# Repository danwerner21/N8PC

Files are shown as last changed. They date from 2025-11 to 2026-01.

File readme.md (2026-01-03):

# N8PC
The N8PC is a Z180 ATX format board with 512K RAM, 512K of ROM, that supports RomWBW and is compatible enough with MSX to run many games.  It supports a 82c42 PS2 keyboard controller, a TMS9918 emulator (either Pico9918, F19A or Tang Nano) for 80 column video output, a Ay-3-8910 PSG for sound, a 6242 RTC, ATARI/MSX style Joysticks (2 button supported) and 6 ISAish slots.  This computer is supported by the RomWBW ecosystem with full CP/M OS Support.

Note that 9.218Mhz is the recommended system clock speed for this system.  

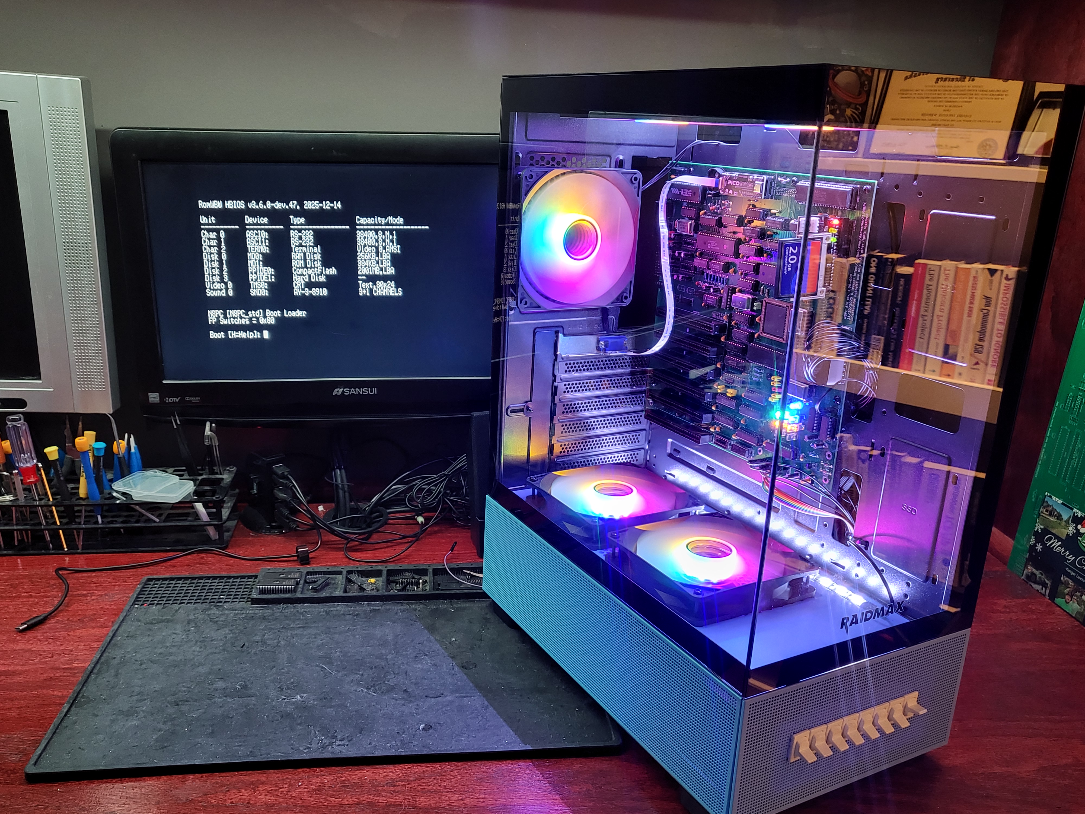
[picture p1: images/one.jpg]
System


## BUGS
```
V1.1 version PCBs have not been tested yet.

Bodges for V1.0 of Board
U33 Cut Pin 3 traces on both Top and Bottom
U33 Cut Pin 5 trace on Bottom

U6 Cut Pin 8 trace on Bottom (NOT TOP!!)

Connect CS_RTC from U47 Pin 2 to U9 Pin 11
Connect U33 Pin 3 To U5 Pin 5
Connect U33 Pin 5 To U5 Pin 6
Connect U18 Pin 2 to U18 Pin 13
```

### Jumper Settings
[TO DO]

### Building the system
[TO DO]

### Default Memory Map
** See RomWBW or C-BIOS Documentation
RomWBW Support: https://github.com/wwarthen/RomWBW
CBIOS MSX Game Support: https://github.com/danwerner21/msxbios

Note that the CBIOS MSX game support is still a work in progress.  It does work, but there is still much work to do. I am not including any actual game ROMS, I leave that to the builder to locate those ROMs as they are easily found on the Internet.

### Bill Of Materials
Reference|Value|Qty|Description
---------|-----|---|-----------
BT1|Battery_Cell|1|CR2032 battery holder
C1-C4,C17|22 uF|5|Polarized capacitor
C5-C8,C10-C13,C15,C16,C18-C27,C29-C33,C36-C41,C43-C54,C56|0.1 uF|44|Unpolarized capacitor
C28|1uF|1|Polarized capacitor
C34|4.7pF|1|
C35|10uF|1|Polarized capacitor
C55,C58,C61-C64,C67,C71-C73|1.0 uF|10|Polarized capacitor, small symbol
C57|0.01 uF|1|Unpolarized capacitor
C59,C60|15pf|2|Unpolarized capacitor
C101,C102|270 pF|2|Unpolarized capacitor
C109,C110|10 uF|2|Polarized capacitor, small symbol
D1,D2|1N4148|2|Diode
D3,D4|D|2|Diode
D5|1N5817|1|20V 1A Schottky Barrier Rectifier Diode, DO-41
D6|RUN/HALT|1|Dual LED, bidirectional
D7|LED1|1|Light emitting diode
D8|LED2|1|Light emitting diode
D9|LED3|1|Light emitting diode
D10|LED0|1|Light emitting diode
D11|IDE|1|Light emitting diode
D12|STATUS|1|Light emitting diode
J1,J2,J5,J7,J9,J13|IRQ Selection|6|Generic connector, double row, 02x06
J3,J4,J6,J8,J10,J14|Bus_ISA_8bit|6|8-bit ISA-PC bus connector
J11|F18A TANG NANO Connector|1|Generic connector, double row, 02x10
J12|FRONT_PANEL|1|Generic connector, double row, 02x11
J15|MOUSE|1|6-pin Mini-DIN connector
J16|KEYBOARD|1|6-pin Mini-DIN connector
J17,J19|TTL SERIAL CONSOLE|2|Generic connector, single row, 01x06
J18,J20|TTL CONSOLE PWR|2|Generic connector, single row, 01x02
J21|KEYBOARD IRQ|1|Generic connector, double row, 02x02
J22|BUS IRQ|1|Generic connector, double row, 02x02
J23|VIDEO IRQ|1|Generic connector, double row, 02x02
JP2|CTS0|1|Jumper, 2-pole, open
JP3|CTS1|1|Jumper, 2-pole, open
JP10|JUMPER|1|Jumper, 2-pole, open
K2|IDE_PWR|1|Generic connector, single row, 01x03
K3-K5,K16,K18|CONN_3|5|Generic connector, single row, 01x03
K17|CPU_CLK|1|Generic connector, single row, 01x03
P1|IO_ADDR|1|Generic connector, double row, 02x03
P11|CONN_10X2|1|Generic connector, double row, 02x10
P12|POWER_SW|1|Generic connector, single row, 01x02
P13,P18|SERIAL|2|Generic connector, double row, 02x05
P14|14.31818 MHz CLK|1|
P15|AUDIO|1|Generic connector, double row, 02x05
P16|IO_ADDR2|1|Generic connector, double row, 02x03
P19|ASCI OSC|1|
P27|FLOPPY|1|Generic connector, double row, 02x17
P29|PPIDE|1|Generic connector, double row, 02x20
P31|PARALLEL EXP|1|Generic connector, double row, 02x13
P37|CPU OSC|1|
P41|OSC_FDC|1|
P43|CHAN_MIX|1|Generic connector, double row, 02x02
P51|JOYSTICK0|1|Generic connector, double row, 02x05
P52|JOYSTICK1|1|Generic connector, double row, 02x05
R1,R3|10k|2|Resistor
R2,R5,R7,R9,R10,R36|470|6|Resistor
R4,R13,R14,R26|4.7K|4|Resistor
R6,R17,R19,R21|1000|4|Resistor
R8,R12,R46,R47,RN5,RR1,RR5,RR8,RV1,RV2|4700|10|9 resistor network, star topology, bussed resistors, small US symbol,Potentiometer,Resistor
R11|100|1|Resistor
R16,R22-R24|10K|4|Resistor
R42|2200|1|Resistor
RP1|150|1|8 resistor network, star topology, bussed resistors, small symbol
SW1|POWER|1|Push button switch, generic, two pins
SW2|RESET|1|Push button switch, generic, two pins
U1,U3,U4,U16,U31|74LS244|5|Octal Buffer and Line Driver With 3-State Output, active-low enables, non-inverting outputs
U2,U63|74LS14|2|Hex inverter schmitt trigger
U5|74LS02|1|quad 2-input NOR gate
U6,U7,U18|74LS32|3|Quad 2-input OR
U8|74LS08|1|Quad And2
U9,U58,U68|74LS138|3|Decoder 3 to 8 active low outputs
U10,U35|MAX232|2|Dual RS232 driver/receiver, 5V supply, 120kb/s, 0C-70C
U12|74LS74|1|Dual D Flip-flop, Set & Reset
U13|27C080|1|OTP EPROM 8 MiBit (1 Mi x 8)
U14|74LS125|1|Quad buffer 3-State outputs
U15|74LS245|1|Octal BUS Transceivers, 3-State outputs
U19|74HCT14|1|Hex inverter schmitt trigger
U21,U57|74LS682N|2|
U23|TMS9918 EMU|1|
U24|CLK|1|
U25|82c42|1|
U26|74LS06|1|
U29|DS1233|1|
U32|74LS139|1|Dual Decoder 1 of 4, Active low outputs
U33|74LS10|1|Triple 3-input NAND
U34|74LS393|1|Dual BCD 4-bit counter
U38|8255|1|Programmable Peripheral Interface, PDIP-40
U39|74LS04|1|Hex Inverter
U47|M6242|1|M6242
U48|AY-3-8910|1|
U49|74LS07N|1|Hex Buffers and Drivers With Open Collector High Voltage Outputs
U51|STEREO_JACK|1|Audio Jack, 3 Poles (Stereo / TRS)
U52|Z8S180|1|
U53|SRAM_512KO|1|512K x 8 Low Power CMOS RAM, DIP-32
U55|74LS273|1|8-bit D Flip-Flop, reset
U61|WD37C65BJM|1|
U66,U67|74LS157|2|Quad 2 to 1 line Multiplexer
U70|74LS174|1|Hex D-type Flip-Flop, reset
X1|RTC_OSC|1|Two pin crystal

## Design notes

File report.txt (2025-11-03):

Info: Backing up file '\\truenas.\Development\Vintage\ECB 6x0x-6U-012\sym-lib-table' to '\\truenas.\Development\Vintage\ECB 6x0x-6U-012\rescue-backup\sym-lib-table-2024-12-25-17-23-22'.
Info: Backing up file '\\truenas.\Development\Vintage\ECB 6x0x-6U-012\6x0x-6U.sch' to '\\truenas.\Development\Vintage\ECB 6x0x-6U-012\rescue-backup\6x0x-6U-2024-12-25-17-23-22.sch'.
Info: Backing up file '\\truenas.\Development\Vintage\ECB 6x0x-6U-012\PropTerm.sch' to '\\truenas.\Development\Vintage\ECB 6x0x-6U-012\rescue-backup\PropTerm-2024-12-25-17-23-22.sch'.
Info: Backing up file '\\truenas.\Development\Vintage\ECB 6x0x-6U-012\Power.sch' to '\\truenas.\Development\Vintage\ECB 6x0x-6U-012\rescue-backup\Power-2024-12-25-17-23-22.sch'.
Info: Backing up file '\\truenas.\Development\Vintage\ECB 6x0x-6U-012\Reset.sch' to '\\truenas.\Development\Vintage\ECB 6x0x-6U-012\rescue-backup\Reset-2024-12-25-17-23-22.sch'.
Info: Backing up file '\\truenas.\Development\Vintage\ECB 6x0x-6U-012\MMU-4.sch' to '\\truenas.\Development\Vintage\ECB 6x0x-6U-012\rescue-backup\MMU-4-2024-12-25-17-23-22.sch'.
Info: Backing up file '\\truenas.\Development\Vintage\ECB 6x0x-6U-012\cpu-6809.sch' to '\\truenas.\Development\Vintage\ECB 6x0x-6U-012\rescue-backup\cpu-6809-2024-12-25-17-23-22.sch'.
Info: Backing up file '\\truenas.\Development\Vintage\ECB 6x0x-6U-012\Spare.sch' to '\\truenas.\Development\Vintage\ECB 6x0x-6U-012\rescue-backup\Spare-2024-12-25-17-23-22.sch'.
Info: Backing up file '\\truenas.\Development\Vintage\ECB 6x0x-6U-012\IO.sch' to '\\truenas.\Development\Vintage\ECB 6x0x-6U-012\rescue-backup\IO-2024-12-25-17-23-22.sch'.
Info: Backing up file '\\truenas.\Development\Vintage\ECB 6x0x-6U-012\CPU-6802.sch' to '\\truenas.\Development\Vintage\ECB 6x0x-6U-012\rescue-backup\CPU-6802-2024-12-25-17-23-22.sch'.
Info: Backing up file '\\truenas.\Development\Vintage\ECB 6x0x-6U-012\memory-map.sch' to '\\truenas.\Development\Vintage\ECB 6x0x-6U-012\rescue-backup\memory-map-2024-12-25-17-23-22.sch'.
Info: Backing up file '\\truenas.\Development\Vintage\ECB 6x0x-6U-012\ECBbus.sch' to '\\truenas.\Development\Vintage\ECB 6x0x-6U-012\rescue-backup\ECBbus-2024-12-25-17-23-22.sch'.
Info: Backing up file '\\truenas.\Development\Vintage\ECB 6x0x-6U-012\Decoder.sch' to '\\truenas.\Development\Vintage\ECB 6x0x-6U-012\rescue-backup\Decoder-2024-12-25-17-23-22.sch'.
Info: Backing up file '\\truenas.\Development\Vintage\ECB 6x0x-6U-012\ACIA.sch' to '\\truenas.\Development\Vintage\ECB 6x0x-6U-012\rescue-backup\ACIA-2024-12-25-17-23-22.sch'.
Info: Backing up file '\\truenas.\Development\Vintage\ECB 6x0x-6U-012\TIMER.sch' to '\\truenas.\Development\Vintage\ECB 6x0x-6U-012\rescue-backup\TIMER-2024-12-25-17-23-22.sch'.
Info: Backing up file '\\truenas.\Development\Vintage\ECB 6x0x-6U-012\VIAS.sch' to '\\truenas.\Development\Vintage\ECB 6x0x-6U-012\rescue-backup\VIAS-2024-12-25-17-23-22.sch'.
Info: Backing up file '\\truenas.\Development\Vintage\ECB 6x0x-6U-012\PIA.sch' to '\\truenas.\Development\Vintage\ECB 6x0x-6U-012\rescue-backup\PIA-2024-12-25-17-23-22.sch'.
Info: Backing up file '\\truenas.\Development\Vintage\ECB 6x0x-6U-012\RTC.sch' to '\\truenas.\Development\Vintage\ECB 6x0x-6U-012\rescue-backup\RTC-2024-12-25-17-23-22.sch'.
Info: Backing up file '\\truenas.\Development\Vintage\ECB 6x0x-6U-012\6x0x-6U.kicad_pro' to '\\truenas.\Development\Vintage\ECB 6x0x-6U-012\rescue-backup\6x0x-6U-2024-12-25-17-23-22.kicad_pro'.
Info: Backing up file '\\truenas.\Development\Vintage\ECB 6x0x-6U-012\6x0x-6U-cache.lib' to '\\truenas.\Development\Vintage\ECB 6x0x-6U-012\rescue-backup\6x0x-6U-cache-2024-12-25-17-23-22.lib'.
Info: Backing up file '\\truenas.\Development\Vintage\ECB 6x0x-6U-012\6x0x-6U-rescue.lib' to '\\truenas.\Development\Vintage\ECB 6x0x-6U-012\rescue-backup\6x0x-6U-rescue-2024-12-25-17-23-22.lib'.
Info: Backing up file '\\truenas.\Development\Vintage\ECB 6x0x-6U-012\6x0x-6U-rescue.dcm' to '\\truenas.\Development\Vintage\ECB 6x0x-6U-012\rescue-backup\6x0x-6U-rescue-2024-12-25-17-23-22.dcm'.
Info: Adding library '6x0x-6U-rescue', file '${KIPRJMOD}/6x0x-6U-rescue.lib' to project symbol library table.
Symbol R mapped to symbol library '6x0x-6U-rescue'.
Symbol R_PACK7 mapped to symbol library '6x0x-6U-rescue'.
Symbol CP1 mapped to symbol library '6x0x-6U-rescue'.
Symbol 24C512 mapped to symbol library '6x0x-6U-rescue'.
Symbol CONN_4 mapped to symbol library '6x0x-6U-rescue'.
Symbol GND mapped to symbol library '6x0x-6U-rescue'.
Symbol VDD mapped to symbol library '6x0x-6U-rescue'.
Symbol MAX232 mapped to symbol library '6x0x-6U-rescue'.
Symbol CP1 mapped to symbol library '6x0x-6U-rescue'.
Symbol R mapped to symbol library '6x0x-6U-rescue'.
Symbol R mapped to symbol library '6x0x-6U-rescue'.
Symbol CRYSTAL mapped to symbol library '6x0x-6U-rescue'.
Symbol VDD mapped to symbol library '6x0x-6U-rescue'.
Symbol R mapped to symbol library '6x0x-6U-rescue'.
Symbol R mapped to symbol library '6x0x-6U-rescue'.
Symbol R mapped to symbol library '6x0x-6U-rescue'.
Symbol R mapped to symbol library '6x0x-6U-rescue'.
Symbol R mapped to symbol library '6x0x-6U-rescue'.
Symbol R mapped to symbol library '6x0x-6U-rescue'.
Symbol R mapped to symbol library '6x0x-6U-rescue'.
Symbol VCC mapped to symbol library '6x0x-6U-rescue'.
Symbol FUSE mapped to symbol library '6x0x-6U-rescue'.
Symbol R_PACK7 mapped to symbol library '6x0x-6U-rescue'.
Symbol JUMPER3 mapped to symbol library '6x0x-6U-rescue'.
Symbol 74LS06 mapped to symbol library '6x0x-6U-rescue'.
Symbol P8X32A mapped to symbol library '6x0x-6U-rescue'.
Symbol GND mapped to symbol library '6x0x-6U-rescue'.
Symbol VDD mapped to symbol library '6x0x-6U-rescue'.
Symbol GND mapped to symbol library '6x0x-6U-rescue'.
Symbol LED mapped to symbol library '6x0x-6U-rescue'.
Symbol 74LS06 mapped to symbol library '6x0x-6U-rescue'.
Symbol SDcard-mini_04 mapped to symbol library '6x0x-6U-rescue'.
Symbol VCC mapped to symbol library '6x0x-6U-rescue'.
Symbol R mapped to symbol library '6x0x-6U-rescue'.
Symbol CONN_6X2 mapped to symbol library '6x0x-6U-rescue'.
Symbol R mapped to symbol library '6x0x-6U-rescue'.
Symbol R mapped to symbol library '6x0x-6U-rescue'.
Symbol VDD mapped to symbol library '6x0x-6U-rescue'.
Symbol VDD mapped to symbol library '6x0x-6U-rescue'.
Symbol CP1 mapped to symbol library '6x0x-6U-rescue'.
Symbol C mapped to symbol library '6x0x-6U-rescue'.
Symbol GND mapped to symbol library '6x0x-6U-rescue'.
Symbol 74LS06 mapped to symbol library '6x0x-6U-rescue'.
Symbol GND mapped to symbol library '6x0x-6U-rescue'.
Symbol SPEAKER mapped to symbol library '6x0x-6U-rescue'.
Symbol GND mapped to symbol library '6x0x-6U-rescue'.
Symbol R mapped to symbol library '6x0x-6U-rescue'.
Symbol R mapped to symbol library '6x0x-6U-rescue'.
Symbol R mapped to symbol library '6x0x-6U-rescue'.
Symbol RR9 mapped to symbol library '6x0x-6U-rescue'.
Symbol VDD mapped to symbol library '6x0x-6U-rescue'.
Symbol JUMPER mapped to symbol library '6x0x-6U-rescue'.
Symbol CP1 mapped to symbol library '6x0x-6U-rescue'.
Symbol GND mapped to symbol library '6x0x-6U-rescue'.
Symbol VCC mapped to symbol library '6x0x-6U-rescue'.
Symbol CP1 mapped to symbol library '6x0x-6U-rescue'.
Symbol CONN_5X2 mapped to symbol library '6x0x-6U-rescue'.
Symbol CP1 mapped to symbol library '6x0x-6U-rescue'.
Symbol R mapped to symbol library '6x0x-6U-rescue'.
Symbol R mapped to symbol library '6x0x-6U-rescue'.
Symbol R mapped to symbol library '6x0x-6U-rescue'.
Symbol DE15 mapped to symbol library '6x0x-6U-rescue'.
Symbol GND mapped to symbol library '6x0x-6U-rescue'.
Symbol GND mapped to symbol library '6x0x-6U-rescue'.
Symbol CONN_9 mapped to symbol library '6x0x-6U-rescue'.
Symbol JUMPER mapped to symbol library '6x0x-6U-rescue'.
Symbol CONN_4 mapped to symbol library '6x0x-6U-rescue'.
Symbol GND mapped to symbol library '6x0x-6U-rescue'.
Symbol GND mapped to symbol library '6x0x-6U-rescue'.
Symbol GND mapped to symbol library '6x0x-6U-rescue'.
Symbol MINI_DIN_6 mapped to symbol library '6x0x-6U-rescue'.
Symbol R mapped to symbol library '6x0x-6U-rescue'.
Symbol 74LS14PWR mapped to symbol library '6x0x-6U-rescue'.
Symbol 74LS14PWR mapped to symbol library '6x0x-6U-rescue'.
Symbol DIODE mapped to symbol library '6x0x-6U-rescue'.
Symbol CP1 mapped to symbol library '6x0x-6U-rescue'.
Symbol 74LS14PWR mapped to symbol library '6x0x-6U-rescue'.
Symbol 74LS14PWR mapped to symbol library '6x0x-6U-rescue'.
Symbol 74LS14PWR mapped to symbol library '6x0x-6U-rescue'.
Symbol 74LS14PWR mapped to symbol library '6x0x-6U-rescue'.
Symbol 74LS74PWR mapped to symbol library '6x0x-6U-rescue'.
Symbol C mapped to symbol library '6x0x-6U-rescue'.
Symbol C mapped to symbol library '6x0x-6U-rescue'.
Symbol C mapped to symbol library '6x0x-6U-rescue'.
Symbol C mapped to symbol library '6x0x-6U-rescue'.
Symbol C mapped to symbol library '6x0x-6U-rescue'.
Symbol C mapped to symbol library '6x0x-6U-rescue'.
Symbol C mapped to symbol library '6x0x-6U-rescue'.
Symbol C mapped to symbol library '6x0x-6U-rescue'.
Symbol C mapped to symbol library '6x0x-6U-rescue'.
Symbol C mapped to symbol library '6x0x-6U-rescue'.
Symbol C mapped to symbol library '6x0x-6U-rescue'.
Symbol C mapped to symbol library '6x0x-6U-rescue'.
Symbol C mapped to symbol library '6x0x-6U-rescue'.
Symbol C mapped to symbol library '6x0x-6U-rescue'.
Symbol C mapped to symbol library '6x0x-6U-rescue'.
Symbol C mapped to symbol library '6x0x-6U-rescue'.
Symbol C mapped to symbol library '6x0x-6U-rescue'.
Symbol C mapped to symbol library '6x0x-6U-rescue'.
Symbol C mapped to symbol library '6x0x-6U-rescue'.
Symbol C mapped to symbol library '6x0x-6U-rescue'.
Symbol C mapped to symbol library '6x0x-6U-rescue'.
Symbol C mapped to symbol library '6x0x-6U-rescue'.
Symbol C mapped to symbol library '6x0x-6U-rescue'.
Symbol PWR_FLAG mapped to symbol library '6x0x-6U-rescue'.
Symbol DIODE mapped to symbol library '6x0x-6U-rescue'.
Symbol R mapped to symbol library '6x0x-6U-rescue'.
Symbol CONN_2 mapped to symbol library '6x0x-6U-rescue'.
Symbol SW_PUSH mapped to symbol library '6x0x-6U-rescue'.
Symbol CP1 mapped to symbol library '6x0x-6U-rescue'.
Symbol GND mapped to symbol library '6x0x-6U-rescue'.
Symbol R mapped to symbol library '6x0x-6U-rescue'.
Symbol R mapped to symbol library '6x0x-6U-rescue'.
Symbol PWR_FLAG mapped to symbol library '6x0x-6U-rescue'.
Symbol GND mapped to symbol library '6x0x-6U-rescue'.
Symbol CONN_10X2 mapped to symbol library '6x0x-6U-rescue'.
Symbol PWR_FLAG mapped to symbol library '6x0x-6U-rescue'.
Symbol GND mapped to symbol library '6x0x-6U-rescue'.
Symbol CONN_5 mapped to symbol library '6x0x-6U-rescue'.
Symbol GND mapped to symbol library '6x0x-6U-rescue'.
Symbol C mapped to symbol library '6x0x-6U-rescue'.
Symbol C mapped to symbol library '6x0x-6U-rescue'.
Symbol C mapped to symbol library '6x0x-6U-rescue'.
Symbol C mapped to symbol library '6x0x-6U-rescue'.
Symbol C mapped to symbol library '6x0x-6U-rescue'.
Symbol GND mapped to symbol library '6x0x-6U-rescue'.
Symbol VDD mapped to symbol library '6x0x-6U-rescue'.
Symbol C mapped to symbol library '6x0x-6U-rescue'.
Symbol C mapped to symbol library '6x0x-6U-rescue'.
Symbol C mapped to symbol library '6x0x-6U-rescue'.
Symbol C mapped to symbol library '6x0x-6U-rescue'.
Symbol C mapped to symbol library '6x0x-6U-rescue'.
Symbol PWR_FLAG mapped to symbol library '6x0x-6U-rescue'.
Symbol CONN_4 mapped to symbol library '6x0x-6U-rescue'.
Symbol GND mapped to symbol library '6x0x-6U-rescue'.
Symbol C mapped to symbol library '6x0x-6U-rescue'.
Symbol C mapped to symbol library '6x0x-6U-rescue'.
Symbol VCC mapped to symbol library '6x0x-6U-rescue'.
Symbol C mapped to symbol library '6x0x-6U-rescue'.
Symbol GND mapped to symbol library '6x0x-6U-rescue'.
Symbol VCC mapped to symbol library '6x0x-6U-rescue'.
Symbol C mapped to symbol library '6x0x-6U-rescue'.
Symbol C mapped to symbol library '6x0x-6U-rescue'.
Symbol C mapped to symbol library '6x0x-6U-rescue'.
Symbol C mapped to symbol library '6x0x-6U-rescue'.
Symbol C mapped to symbol library '6x0x-6U-rescue'.
Symbol C mapped to symbol library '6x0x-6U-rescue'.
Symbol C mapped to symbol library '6x0x-6U-rescue'.
Symbol C mapped to symbol library '6x0x-6U-rescue'.
Symbol C mapped to symbol library '6x0x-6U-rescue'.
Symbol C mapped to symbol library '6x0x-6U-rescue'.
Symbol GND mapped to symbol library '6x0x-6U-rescue'.
Symbol VCC mapped to symbol library '6x0x-6U-rescue'.
Symbol C mapped to symbol library '6x0x-6U-rescue'.
Symbol C mapped to symbol library '6x0x-6U-rescue'.
Symbol C mapped to symbol library '6x0x-6U-rescue'.
Symbol CP mapped to symbol library '6x0x-6U-rescue'.
Symbol CONN_1 mapped to symbol library '6x0x-6U-rescue'.
Symbol GND mapped to symbol library '6x0x-6U-rescue'.
Symbol CONN_1 mapped to symbol library '6x0x-6U-rescue'.
Symbol CP mapped to symbol library '6x0x-6U-rescue'.
Symbol GND mapped to symbol library '6x0x-6U-rescue'.
Symbol LM7805 mapped to symbol library '6x0x-6U-rescue'.
Symbol GND mapped to symbol library '6x0x-6U-rescue'.
Symbol GND mapped to symbol library '6x0x-6U-rescue'.
Symbol VCC mapped to symbol library '6x0x-6U-rescue'.
Symbol GND mapped to symbol library '6x0x-6U-rescue'.
Symbol CP mapped to symbol library '6x0x-6U-rescue'.
Symbol VCC mapped to symbol library '6x0x-6U-rescue'.
Symbol GND mapped to symbol library '6x0x-6U-rescue'.
Symbol CP mapped to symbol library '6x0x-6U-rescue'.
Symbol VCC mapped to symbol library '6x0x-6U-rescue'.
Symbol GND mapped to symbol library '6x0x-6U-rescue'.
Symbol CP mapped to symbol library '6x0x-6U-rescue'.
Symbol VCC mapped to symbol library '6x0x-6U-rescue'.
Symbol GND mapped to symbol library '6x0x-6U-rescue'.
Symbol CP mapped to symbol library '6x0x-6U-rescue'.
Symbol GND mapped to symbol library '6x0x-6U-rescue'.
Symbol GND mapped to symbol library '6x0x-6U-rescue'.
Symbol CONN_1 mapped to symbol library '6x0x-6U-rescue'.
Symbol CONN_1 mapped to symbol library '6x0x-6U-rescue'.
Symbol CONN_1 mapped to symbol library '6x0x-6U-rescue'.
Symbol SWITCH_INV mapped to symbol library '6x0x-6U-rescue'.
Symbol LED mapped to symbol library '6x0x-6U-rescue'.
Symbol GND mapped to symbol library '6x0x-6U-rescue'.
Symbol R mapped to symbol library '6x0x-6U-rescue'.
Symbol SW_PUSH mapped to symbol library '6x0x-6U-rescue'.
Symbol CP1 mapped to symbol library '6x0x-6U-rescue'.
Symbol VCC mapped to symbol library '6x0x-6U-rescue'.
Symbol R mapped to symbol library '6x0x-6U-rescue'.
Symbol 74LS14 mapped to symbol library '6x0x-6U-rescue'.
Symbol 74LS06 mapped to symbol library '6x0x-6U-rescue'.
Symbol 74LS32 mapped to symbol library '6x0x-6U-rescue'.
Symbol 74LS06 mapped to symbol library '6x0x-6U-rescue'.
Symbol R mapped to symbol library '6x0x-6U-rescue'.
Symbol JUMPER mapped to symbol library '6x0x-6U-rescue'.
Symbol 74LS174 mapped to symbol library '6x0x-6U-rescue'.
Symbol 74LS138 mapped to symbol library '6x0x-6U-rescue'.
Symbol 74LS08 mapped to symbol library '6x0x-6U-rescue'.
Symbol GND mapped to symbol library '6x0x-6U-rescue'.
Symbol VCC mapped to symbol library '6x0x-6U-rescue'.
Symbol GND mapped to symbol library '6x0x-6U-rescue'.
Symbol 74LS244 mapped to symbol library '6x0x-6U-rescue'.
Symbol 74LS245 mapped to symbol library '6x0x-6U-rescue'.
Symbol SRAM-32K mapped to symbol library '6x0x-6U-rescue'.
Symbol 74LS04 mapped to symbol library '6x0x-6U-rescue'.
Symbol 74LS374 mapped to symbol library '6x0x-6U-rescue'.
Symbol 74LS157 mapped to symbol library '6x0x-6U-rescue'.
Symbol 74LS244 mapped to symbol library '6x0x-6U-rescue'.
Symbol 74LS08 mapped to symbol library '6x0x-6U-rescue'.
Symbol 74LS257 mapped to symbol library '6x0x-6U-rescue'.
Symbol 74LS257 mapped to symbol library '6x0x-6U-rescue'.
Symbol 74LS08 mapped to symbol library '6x0x-6U-rescue'.
Symbol 74LS08 mapped to symbol library '6x0x-6U-rescue'.
Symbol VCC mapped to symbol library '6x0x-6U-rescue'.
Symbol 74LS74 mapped to symbol library '6x0x-6U-rescue'.
Symbol 74LS244 mapped to symbol library '6x0x-6U-rescue'.
Symbol 74LS244 mapped to symbol library '6x0x-6U-rescue'.
Symbol 74LS14 mapped to symbol library '6x0x-6U-rescue'.
Symbol 74LS06 mapped to symbol library '6x0x-6U-rescue'.
Symbol CONN_3 mapped to symbol library '6x0x-6U-rescue'.
Symbol 74LS04 mapped to symbol library '6x0x-6U-rescue'.
Symbol 74LS00 mapped to symbol library '6x0x-6U-rescue'.
Symbol 74LS14 mapped to symbol library '6x0x-6U-rescue'.
Symbol GND mapped to symbol library '6x0x-6U-rescue'.
Symbol GND mapped to symbol library '6x0x-6U-rescue'.
Symbol CONN_3X2 mapped to symbol library '6x0x-6U-rescue'.
Symbol 74LS02 mapped to symbol library '6x0x-6U-rescue'.
Symbol MC68B09 mapped to symbol library '6x0x-6U-rescue'.
Symbol JUMPER mapped to symbol library '6x0x-6U-rescue'.
Symbol 74LS244 mapped to symbol library '6x0x-6U-rescue'.
Symbol CONN_3 mapped to symbol library '6x0x-6U-rescue'.
Symbol CONN_4X2 mapped to symbol library '6x0x-6U-rescue'.
Symbol VCC mapped to symbol library '6x0x-6U-rescue'.
Symbol RR9 mapped to symbol library '6x0x-6U-rescue'.
Symbol R mapped to symbol library '6x0x-6U-rescue'.
Symbol VCC mapped to symbol library '6x0x-6U-rescue'.
Symbol VCC mapped to symbol library '6x0x-6U-rescue'.
Symbol R mapped to symbol library '6x0x-6U-rescue'.
Symbol 74LS240 mapped to symbol library '6x0x-6U-rescue'.
Symbol GND mapped to symbol library '6x0x-6U-rescue'.
Symbol GND mapped to symbol library '6x0x-6U-rescue'.
Symbol C mapped to symbol library '6x0x-6U-rescue'.
Symbol VCC mapped to symbol library '6x0x-6U-rescue'.
Symbol GND mapped to symbol library '6x0x-6U-rescue'.
Symbol DIL14 mapped to symbol library '6x0x-6U-rescue'.
Symbol 74LS06 mapped to symbol library '6x0x-6U-rescue'.
Symbol 74LS04 mapped to symbol library '6x0x-6U-rescue'.
Symbol 74LS00 mapped to symbol library '6x0x-6U-rescue'.
Symbol 74LS163 mapped to symbol library '6x0x-6U-rescue'.
Symbol 74LS00 mapped to symbol library '6x0x-6U-rescue'.
Symbol 74LS14 mapped to symbol library '6x0x-6U-rescue'.
Symbol 74LS14 mapped to symbol library '6x0x-6U-rescue'.
Symbol 74LS86 mapped to symbol library '6x0x-6U-rescue'.
Symbol 74LS74 mapped to symbol library '6x0x-6U-rescue'.
Symbol 74LS74PWR mapped to symbol library '6x0x-6U-rescue'.
Symbol 74LS06 mapped to symbol library '6x0x-6U-rescue'.
Symbol 74LS06 mapped to symbol library '6x0x-6U-rescue'.
Symbol 74LS06 mapped to symbol library '6x0x-6U-rescue'.
Symbol GND mapped to symbol library '6x0x-6U-rescue'.
Symbol 74LS245 mapped to symbol library '6x0x-6U-rescue'.
Symbol RR9 mapped to symbol library '6x0x-6U-rescue'.
Symbol 74LS245 mapped to symbol library '6x0x-6U-rescue'.
Symbol 74LS245 mapped to symbol library '6x0x-6U-rescue'.
Symbol 74LS245 mapped to symbol library '6x0x-6U-rescue'.
Symbol 74LS06 mapped to symbol library '6x0x-6U-rescue'.
Symbol JUMPER mapped to symbol library '6x0x-6U-rescue'.
Symbol 74LS00 mapped to symbol library '6x0x-6U-rescue'.
Symbol 74LS86 mapped to symbol library '6x0x-6U-rescue'.
Symbol 74LS00 mapped to symbol library '6x0x-6U-rescue'.
Symbol GND mapped to symbol library '6x0x-6U-rescue'.
Symbol GND mapped to symbol library '6x0x-6U-rescue'.
Symbol MC6802-6502-N8VEM mapped to symbol library '6x0x-6U-rescue'.
Symbol CONN_4 mapped to symbol library '6x0x-6U-rescue'.
Symbol CONN_3 mapped to symbol library '6x0x-6U-rescue'.
Symbol CONN_3 mapped to symbol library '6x0x-6U-rescue'.
Symbol GND mapped to symbol library '6x0x-6U-rescue'.
Symbol VCC mapped to symbol library '6x0x-6U-rescue'.
Symbol CONN_3 mapped to symbol library '6x0x-6U-rescue'.
Symbol GND mapped to symbol library '6x0x-6U-rescue'.
Symbol CONN_3 mapped to symbol library '6x0x-6U-rescue'.
Symbol GND mapped to symbol library '6x0x-6U-rescue'.
Symbol 74LS245 mapped to symbol library '6x0x-6U-rescue'.
Symbol CONN_3 mapped to symbol library '6x0x-6U-rescue'.
Symbol 74LS14 mapped to symbol library '6x0x-6U-rescue'.
Symbol 74LS00 mapped to symbol library '6x0x-6U-rescue'.
Symbol CONN_3 mapped to symbol library '6x0x-6U-rescue'.
Symbol 74LS244 mapped to symbol library '6x0x-6U-rescue'.
Symbol 74LS682 mapped to symbol library '6x0x-6U-rescue'.
Symbol 74LS04 mapped to symbol library '6x0x-6U-rescue'.
Symbol GND mapped to symbol library '6x0x-6U-rescue'.
Symbol VCC mapped to symbol library '6x0x-6U-rescue'.
Symbol CONN_4X2 mapped to symbol library '6x0x-6U-rescue'.
Symbol 74LS32 mapped to symbol library '6x0x-6U-rescue'.
Symbol 74LS32 mapped to symbol library '6x0x-6U-rescue'.
Symbol 74LS00 mapped to symbol library '6x0x-6U-rescue'.
Symbol CONN_3 mapped to symbol library '6x0x-6U-rescue'.
Symbol 74LS02 mapped to symbol library '6x0x-6U-rescue'.
Symbol 74LS86 mapped to symbol library '6x0x-6U-rescue'.
Symbol 74LS86 mapped to symbol library '6x0x-6U-rescue'.
Symbol 74LS04 mapped to symbol library '6x0x-6U-rescue'.
Symbol 74LS02 mapped to symbol library '6x0x-6U-rescue'.
Symbol 74LS02 mapped to symbol library '6x0x-6U-rescue'.
Symbol SRAM_512K mapped to symbol library '6x0x-6U-rescue'.
Symbol VCC mapped to symbol library '6x0x-6U-rescue'.
Symbol R mapped to symbol library '6x0x-6U-rescue'.
Symbol 29F040 mapped to symbol library '6x0x-6U-rescue'.
Symbol VCC mapped to symbol library '6x0x-6U-rescue'.
Symbol GND mapped to symbol library '6x0x-6U-rescue'.
Symbol C96ABC mapped to symbol library '6x0x-6U-rescue'.
Symbol 74LS138 mapped to symbol library '6x0x-6U-rescue'.
Symbol 74LS04 mapped to symbol library '6x0x-6U-rescue'.
Symbol 74LS32 mapped to symbol library '6x0x-6U-rescue'.
Symbol 74LS00 mapped to symbol library '6x0x-6U-rescue'.
Symbol R mapped to symbol library '6x0x-6U-rescue'.
Symbol JUMPER mapped to symbol library '6x0x-6U-rescue'.
Symbol VCC mapped to symbol library '6x0x-6U-rescue'.
Symbol R mapped to symbol library '6x0x-6U-rescue'.
Symbol R mapped to symbol library '6x0x-6U-rescue'.
Symbol G65SC51P mapped to symbol library '6x0x-6U-rescue'.
Symbol VCC mapped to symbol library '6x0x-6U-rescue'.
Symbol R mapped to symbol library '6x0x-6U-rescue'.
Symbol GND mapped to symbol library '6x0x-6U-rescue'.
Symbol C mapped to symbol library '6x0x-6U-rescue'.
Symbol VCC mapped to symbol library '6x0x-6U-rescue'.
Symbol GND mapped to symbol library '6x0x-6U-rescue'.
Symbol CONN_5X2 mapped to symbol library '6x0x-6U-rescue'.
Symbol GND mapped to symbol library '6x0x-6U-rescue'.
Symbol DIL14 mapped to symbol library '6x0x-6U-rescue'.
Symbol CP mapped to symbol library '6x0x-6U-rescue'.
Symbol CP mapped to symbol library '6x0x-6U-rescue'.
Symbol MAX232 mapped to symbol library '6x0x-6U-rescue'.
Symbol GND mapped to symbol library '6x0x-6U-rescue'.
Symbol VCC mapped to symbol library '6x0x-6U-rescue'.
Symbol CONN_5X2 mapped to symbol library '6x0x-6U-rescue'.
Symbol GND mapped to symbol library '6x0x-6U-rescue'.
Symbol CP mapped to symbol library '6x0x-6U-rescue'.
Symbol CP mapped to symbol library '6x0x-6U-rescue'.
Symbol GND mapped to symbol library '6x0x-6U-rescue'.
Symbol CP mapped to symbol library '6x0x-6U-rescue'.
Symbol 74LS06 mapped to symbol library '6x0x-6U-rescue'.
Symbol JUMPER mapped to symbol library '6x0x-6U-rescue'.
Symbol 6840 mapped to symbol library '6x0x-6U-rescue'.
Symbol CONN_8X2 mapped to symbol library '6x0x-6U-rescue'.
Symbol CONN_3 mapped to symbol library '6x0x-6U-rescue'.
Symbol CONN_3 mapped to symbol library '6x0x-6U-rescue'.
Symbol GND mapped to symbol library '6x0x-6U-rescue'.
Symbol CONN_13X2 mapped to symbol library '6x0x-6U-rescue'.
Symbol G65SC22P mapped to symbol library '6x0x-6U-rescue'.
Symbol CONN_5X2 mapped to symbol library '6x0x-6U-rescue'.
Symbol JUMPER mapped to symbol library '6x0x-6U-rescue'.
Symbol G65SC22P mapped to symbol library '6x0x-6U-rescue'.
Symbol 6821 mapped to symbol library '6x0x-6U-rescue'.
Symbol CONN_8X2 mapped to symbol library '6x0x-6U-rescue'.
Symbol RR9 mapped to symbol library '6x0x-6U-rescue'.
Symbol CONN_4 mapped to symbol library '6x0x-6U-rescue'.
Symbol GND mapped to symbol library '6x0x-6U-rescue'.
Symbol CRYSTAL mapped to symbol library '6x0x-6U-rescue'.
Symbol JUMPER mapped to symbol library '6x0x-6U-rescue'.
Symbol DS1302 mapped to symbol library '6x0x-6U-rescue'.
Symbol VCC mapped to symbol library '6x0x-6U-rescue'.
Symbol GND mapped to symbol library '6x0x-6U-rescue'.
Info: Symbol library table mapping complete!
Info: Created project symbol library table.

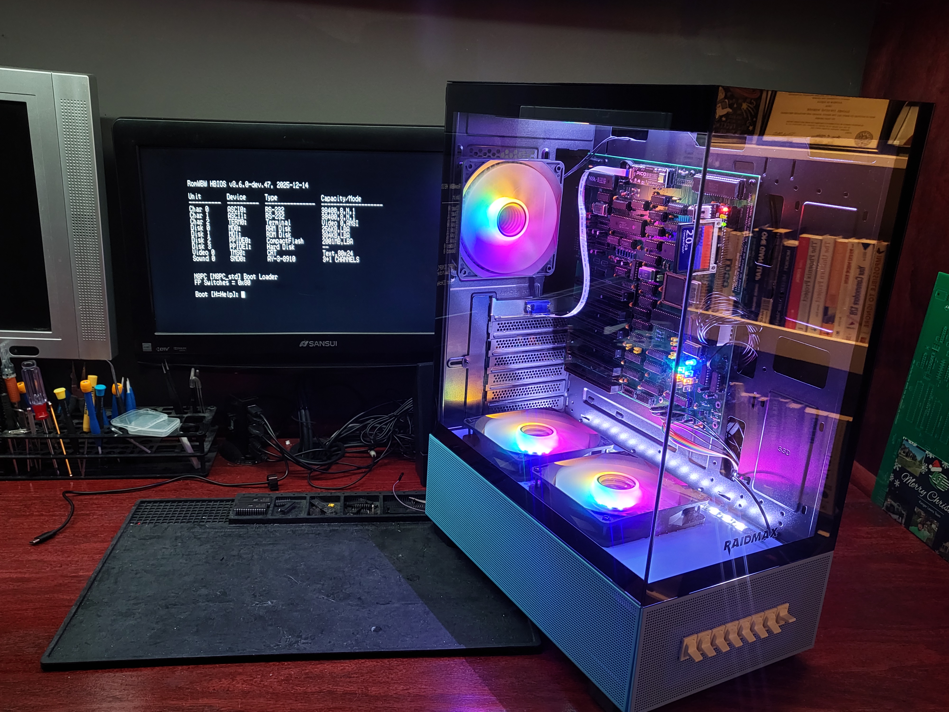
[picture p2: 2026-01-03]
images/three.jpg

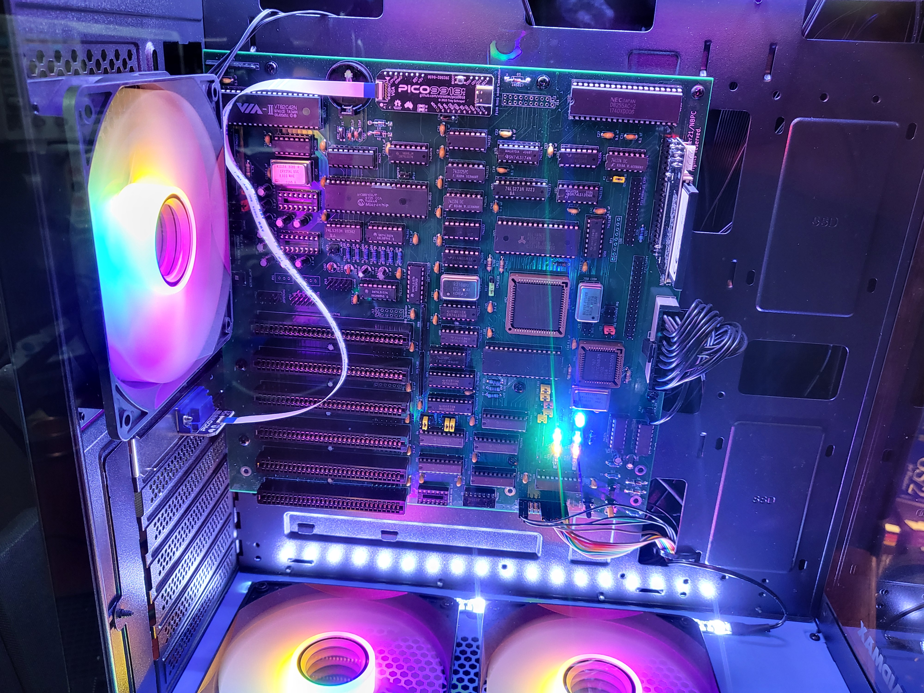
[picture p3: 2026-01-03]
images/two.jpg

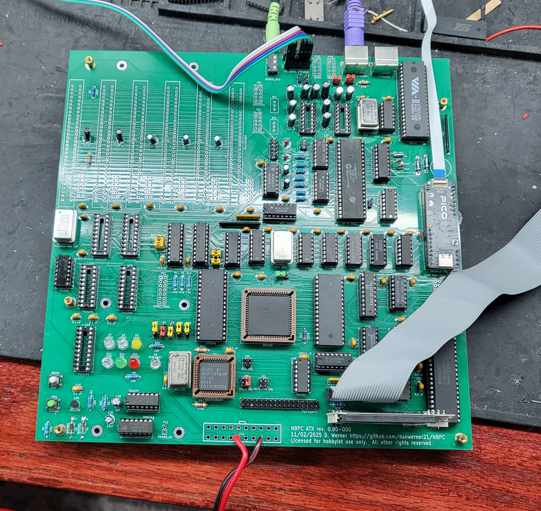
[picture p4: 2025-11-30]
images/N8PC.png

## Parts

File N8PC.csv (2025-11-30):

Reference | Value | Qty | Description
BT1 | Battery_Cell | 1 | Single-cell battery
C1-C4,C17 | 22 uF | 5 | Polarized capacitor
C5-C8,C10-C13,C15,C16,C18-C27,C29-C33,C36-C41,C43-C54,C56 | 0.1 uF | 44 | Unpolarized capacitor
C28 | 1uF | 1 | Polarized capacitor
C34 | 4.7pF | 1
C35 | 10uF | 1 | Polarized capacitor
C55,C58,C61-C64,C67,C71-C73 | 1.0 uF | 10 | Polarized capacitor, small symbol
C57 | 0.01 uF | 1 | Unpolarized capacitor
C59,C60 | 15pf | 2 | Unpolarized capacitor
C101,C102 | 270 pF | 2 | Unpolarized capacitor
C109,C110 | 10 uF | 2 | Polarized capacitor, small symbol
D1,D2 | 1N4148 | 2 | Diode
D3,D4 | D | 2 | Diode
D5 | 1N5817 | 1 | 20V 1A Schottky Barrier Rectifier Diode, DO-41
D6 | RUN/HALT | 1 | Dual LED, bidirectional
D7 | LED1 | 1 | Light emitting diode
D8 | LED2 | 1 | Light emitting diode
D9 | LED3 | 1 | Light emitting diode
D10 | LED0 | 1 | Light emitting diode
D11 | IDE | 1 | Light emitting diode
D12 | STATUS | 1 | Light emitting diode
J1,J2,J5,J7,J9,J13 | IRQ Selection | 6 | Generic connector, double row, 02x06, odd/even pin numbering scheme (row 1 odd numbers, row 2 even numbers), script generated (kicad-library-utils/schlib/autogen/connector/)
J3,J4,J6,J8,J10,J14 | Bus_ISA_8bit | 6 | 8-bit ISA-PC bus connector
J11 | F18A TANG NANO Connector | 1 | Generic connector, double row, 02x10, odd/even pin numbering scheme (row 1 odd numbers, row 2 even numbers), script generated (kicad-library-utils/schlib/autogen/connector/)
J12 | FRONT_PANEL | 1 | Generic connector, double row, 02x11, odd/even pin numbering scheme (row 1 odd numbers, row 2 even numbers), script generated (kicad-library-utils/schlib/autogen/connector/)
J15 | MOUSE | 1 | 6-pin Mini-DIN connector
J16 | KEYBOARD | 1 | 6-pin Mini-DIN connector
J17,J19 | TTL SERIAL CONSOLE | 2 | Generic connector, single row, 01x06, script generated (kicad-library-utils/schlib/autogen/connector/)
J18,J20 | TTL CONSOLE PWR | 2 | Generic connector, single row, 01x02, script generated (kicad-library-utils/schlib/autogen/connector/)
J21 | KEYBOARD IRQ | 1 | Generic connector, double row, 02x02, counter clockwise pin numbering scheme (similar to DIP package numbering), script generated (kicad-library-utils/schlib/autogen/connector/)
J22 | BUS IRQ | 1 | Generic connector, double row, 02x02, counter clockwise pin numbering scheme (similar to DIP package numbering), script generated (kicad-library-utils/schlib/autogen/connector/)
J23 | VIDEO IRQ | 1 | Generic connector, double row, 02x02, counter clockwise pin numbering scheme (similar to DIP package numbering), script generated (kicad-library-utils/schlib/autogen/connector/)
JP2 | CTS0 | 1 | Jumper, 2-pole, open
JP3 | CTS1 | 1 | Jumper, 2-pole, open
JP10 | JUMPER | 1 | Jumper, 2-pole, open
K2 | IDE_PWR | 1 | Generic connector, single row, 01x03, script generated (kicad-library-utils/schlib/autogen/connector/)
K3-K5,K16,K18 | CONN_3 | 5 | Generic connector, single row, 01x03, script generated (kicad-library-utils/schlib/autogen/connector/)
K17 | CPU_CLK | 1 | Generic connector, single row, 01x03, script generated (kicad-library-utils/schlib/autogen/connector/)
P1 | IO_ADDR | 1 | Generic connector, double row, 02x03, odd/even pin numbering scheme (row 1 odd numbers, row 2 even numbers), script generated (kicad-library-utils/schlib/autogen/connector/)
P11 | CONN_10X2 | 1 | Generic connector, double row, 02x10, odd/even pin numbering scheme (row 1 odd numbers, row 2 even numbers), script generated (kicad-library-utils/schlib/autogen/connector/)
P12 | POWER_SW | 1 | Generic connector, single row, 01x02, script generated (kicad-library-utils/schlib/autogen/connector/)
P13,P18 | SERIAL | 2 | Generic connector, double row, 02x05, odd/even pin numbering scheme (row 1 odd numbers, row 2 even numbers), script generated (kicad-library-utils/schlib/autogen/connector/)
P14 | 14.31818 MHz CLK | 1
P15 | AUDIO | 1 | Generic connector, double row, 02x05, odd/even pin numbering scheme (row 1 odd numbers, row 2 even numbers), script generated (kicad-library-utils/schlib/autogen/connector/)
P16 | IO_ADDR2 | 1 | Generic connector, double row, 02x03, odd/even pin numbering scheme (row 1 odd numbers, row 2 even numbers), script generated (kicad-library-utils/schlib/autogen/connector/)
P19 | ASCI OSC | 1
P27 | FLOPPY | 1 | Generic connector, double row, 02x17, odd/even pin numbering scheme (row 1 odd numbers, row 2 even numbers), script generated (kicad-library-utils/schlib/autogen/connector/)
P29 | PPIDE | 1 | Generic connector, double row, 02x20, odd/even pin numbering scheme (row 1 odd numbers, row 2 even numbers), script generated (kicad-library-utils/schlib/autogen/connector/)
P31 | PARALLEL EXP | 1 | Generic connector, double row, 02x13, odd/even pin numbering scheme (row 1 odd numbers, row 2 even numbers), script generated (kicad-library-utils/schlib/autogen/connector/)
P37 | CPU OSC | 1
P41 | OSC_FDC | 1
P43 | CHAN_MIX | 1 | Generic connector, double row, 02x02, odd/even pin numbering scheme (row 1 odd numbers, row 2 even numbers), script generated (kicad-library-utils/schlib/autogen/connector/)
P51 | JOYSTICK0 | 1 | Generic connector, double row, 02x05, odd/even pin numbering scheme (row 1 odd numbers, row 2 even numbers), script generated (kicad-library-utils/schlib/autogen/connector/)
P52 | JOYSTICK1 | 1 | Generic connector, double row, 02x05, odd/even pin numbering scheme (row 1 odd numbers, row 2 even numbers), script generated (kicad-library-utils/schlib/autogen/connector/)
R1,R3 | 10k | 2 | Resistor
R2,R5,R7,R9,R10,R36 | 470 | 6 | Resistor
R4,R13,R14,R26 | 4.7K | 4 | Resistor
R6,R17,R19,R21 | 1000 | 4 | Resistor
R8,R12,R46,R47,RN5,RR1,RR5,RR8,RV1,RV2 | 4700 | 10 | 9 resistor network, star topology, bussed resistors, small US symbol,Potentiometer,Resistor
R11 | 100 | 1 | Resistor
R16,R22-R24 | 10K | 4 | Resistor
R42 | 2200 | 1 | Resistor
RP1 | 150 | 1 | 8 resistor network, star topology, bussed resistors, small symbol
SW1 | POWER | 1 | Push button switch, generic, two pins
SW2 | RESET | 1 | Push button switch, generic, two pins
U1,U3,U4,U16,U31 | 74LS244 | 5 | Octal Buffer and Line Driver With 3-State Output, active-low enables, non-inverting outputs
U2,U63 | 74LS14 | 2 | Hex inverter schmitt trigger
U5 | 74LS02 | 1 | quad 2-input NOR gate
U6,U7,U18 | 74LS32 | 3 | Quad 2-input OR
U8 | 74LS08 | 1 | Quad And2
U9,U58,U68 | 74LS138 | 3 | Decoder 3 to 8 active low outputs
U10,U35 | MAX232 | 2 | Dual RS232 driver/receiver, 5V supply, 120kb/s, 0C-70C
U12 | 74LS74 | 1 | Dual D Flip-flop, Set & Reset
U13 | 27C080 | 1 | OTP EPROM 8 MiBit (1 Mi x 8)
U14 | 74LS125 | 1 | Quad buffer 3-State outputs
U15 | 74LS245 | 1 | Octal BUS Transceivers, 3-State outputs
U19 | 74HCT14 | 1 | Hex inverter schmitt trigger
U21,U57 | 74LS682N | 2
U23 | TMS9918 EMU | 1
U24 | CLK | 1
U25 | 82c42 | 1
U26 | 74LS06 | 1
U29 | DS1233 | 1
U32 | 74LS139 | 1 | Dual Decoder 1 of 4, Active low outputs
U33 | 74LS10 | 1 | Triple 3-input NAND
U34 | 74LS393 | 1 | Dual BCD 4-bit counter
U38 | 8255 | 1 | Programmable Peripheral Interface, PDIP-40
U39 | 74LS04 | 1 | Hex Inverter
U47 | M6242 | 1 | M6242
U48 | AY-3-8910 | 1
U49 | 74LS07N | 1 | Hex Buffers and Drivers With Open Collector High Voltage Outputs
U51 | STEREO_JACK | 1 | Audio Jack, 3 Poles (Stereo / TRS)
U52 | Z8S180 | 1
U53 | SRAM_512KO | 1 | 512K x 8 Low Power CMOS RAM, DIP-32
U55 | 74LS273 | 1 | 8-bit D Flip-Flop, reset
U61 | WD37C65BJM | 1
U66,U67 | 74LS157 | 2 | Quad 2 to 1 line Multiplexer
U70 | 74LS174 | 1 | Hex D-type Flip-Flop, reset
X1 | RTC_OSC | 1 | Two pin crystal

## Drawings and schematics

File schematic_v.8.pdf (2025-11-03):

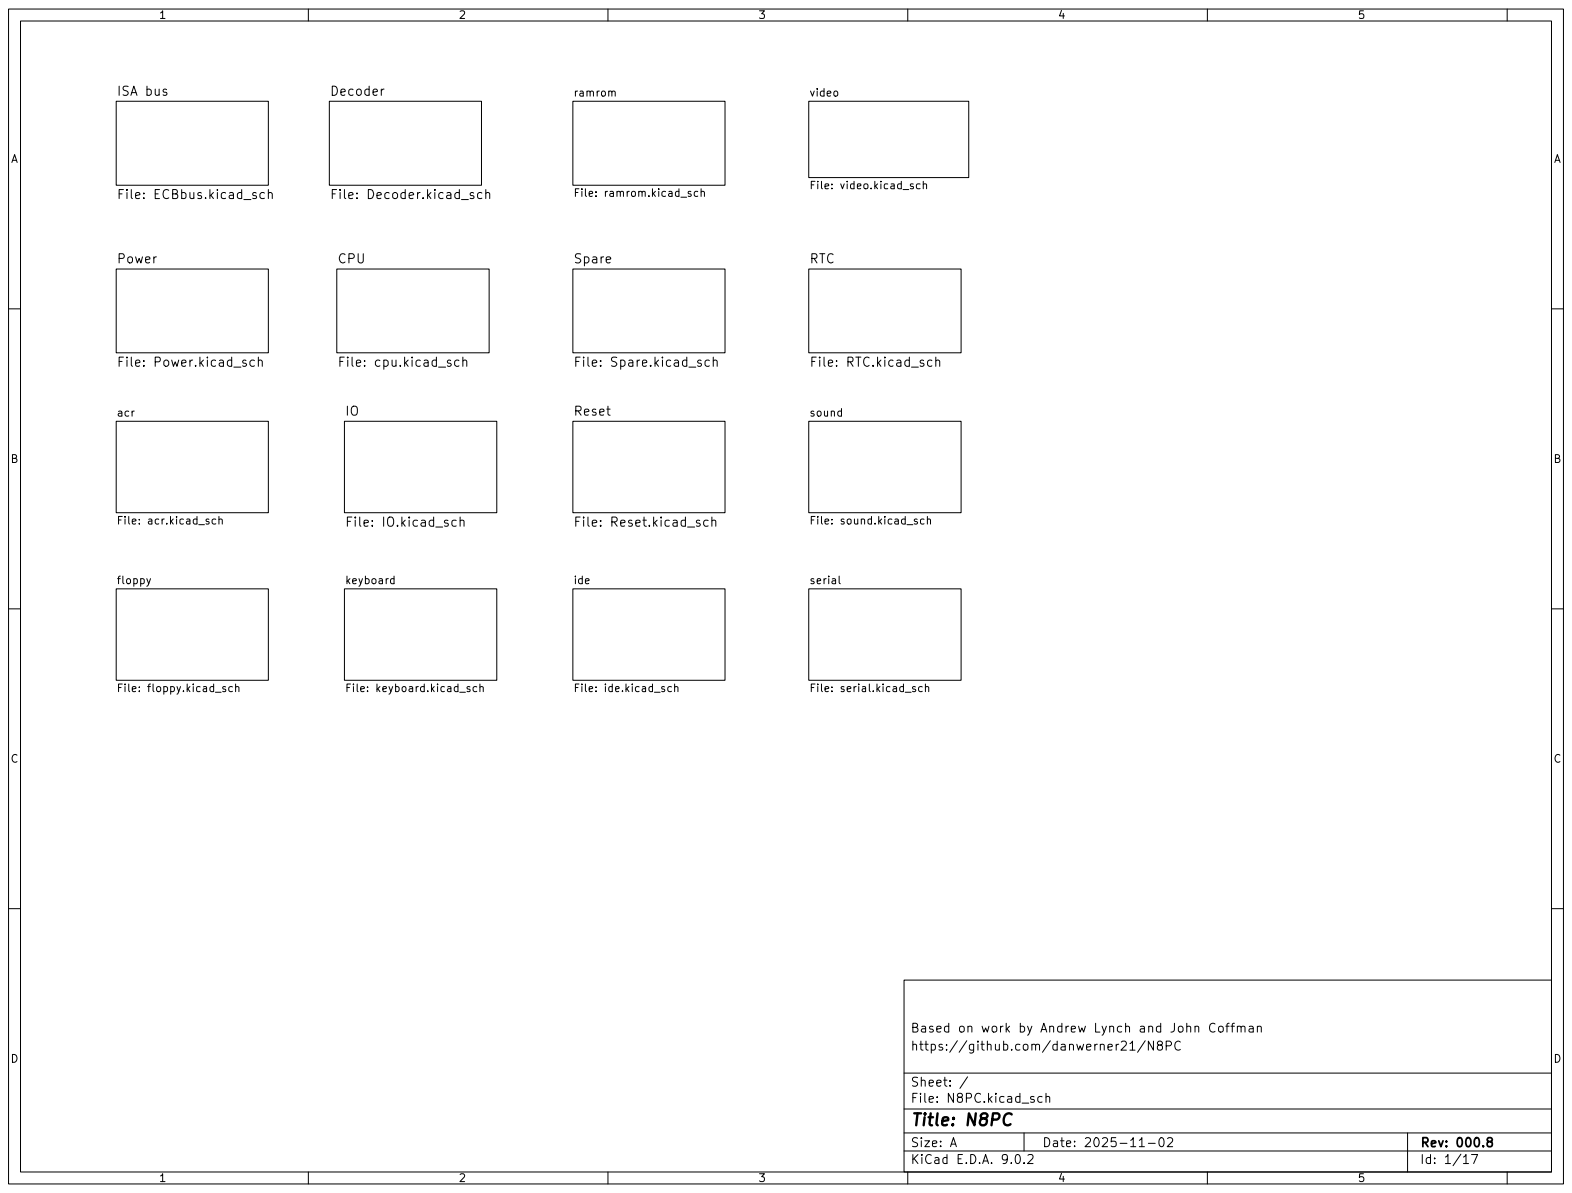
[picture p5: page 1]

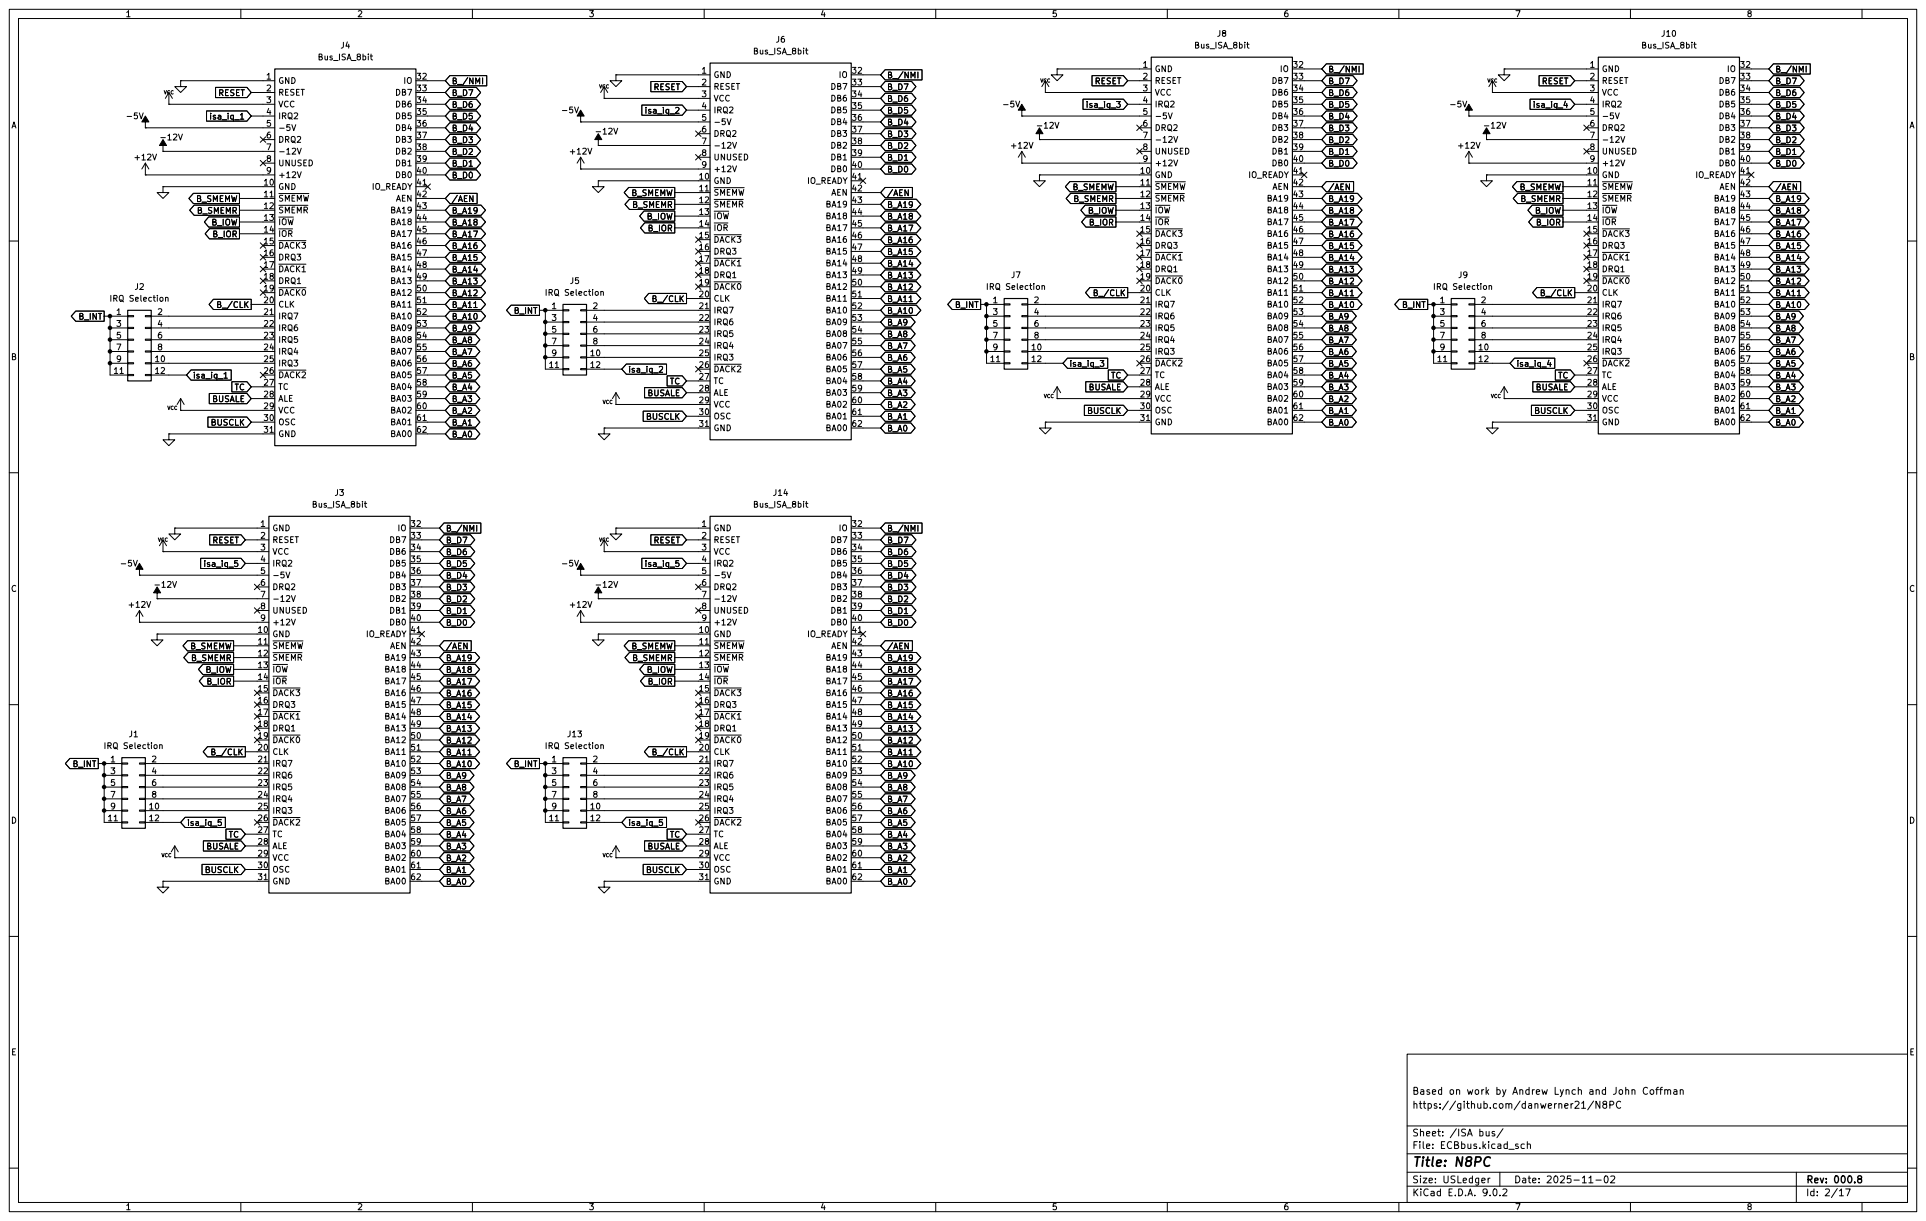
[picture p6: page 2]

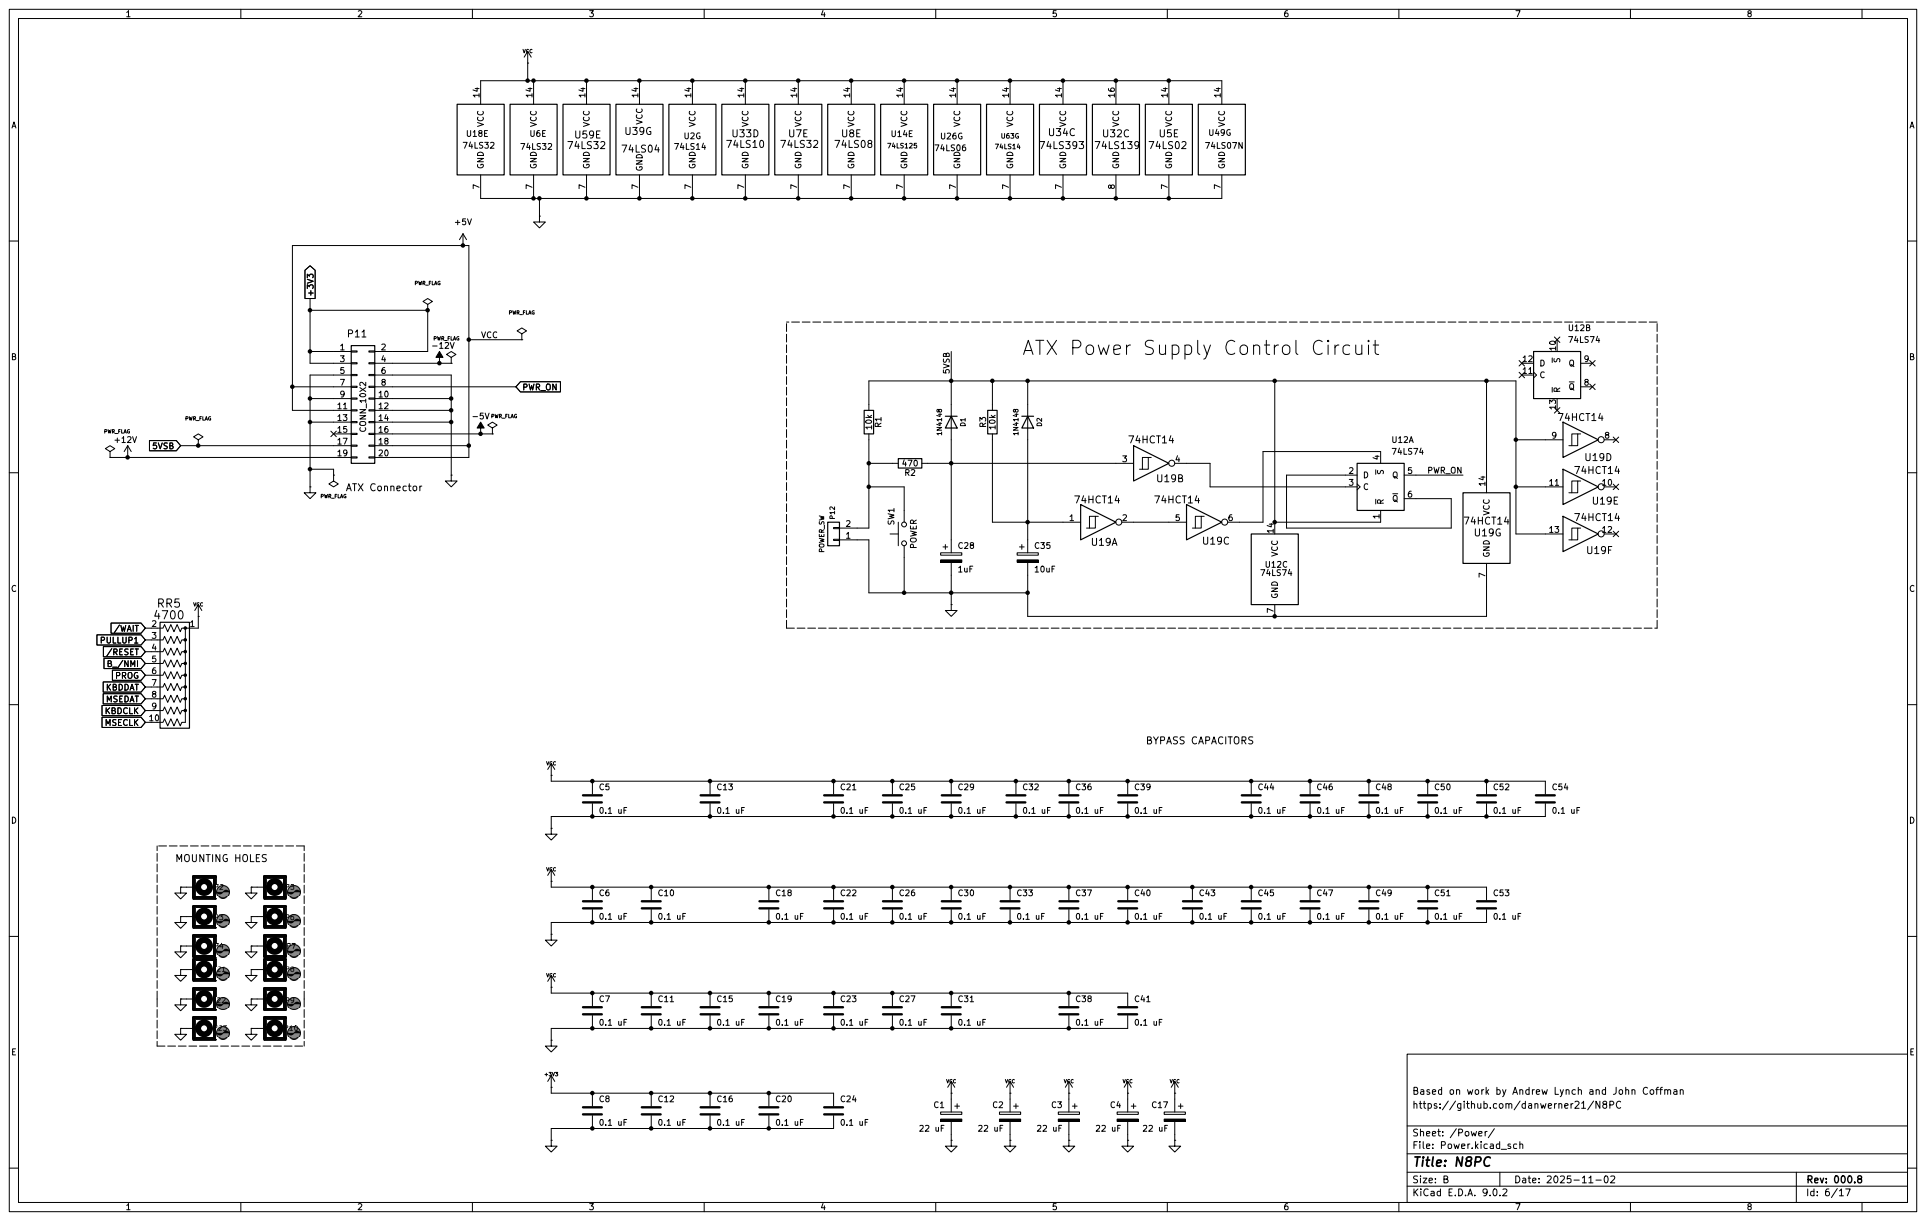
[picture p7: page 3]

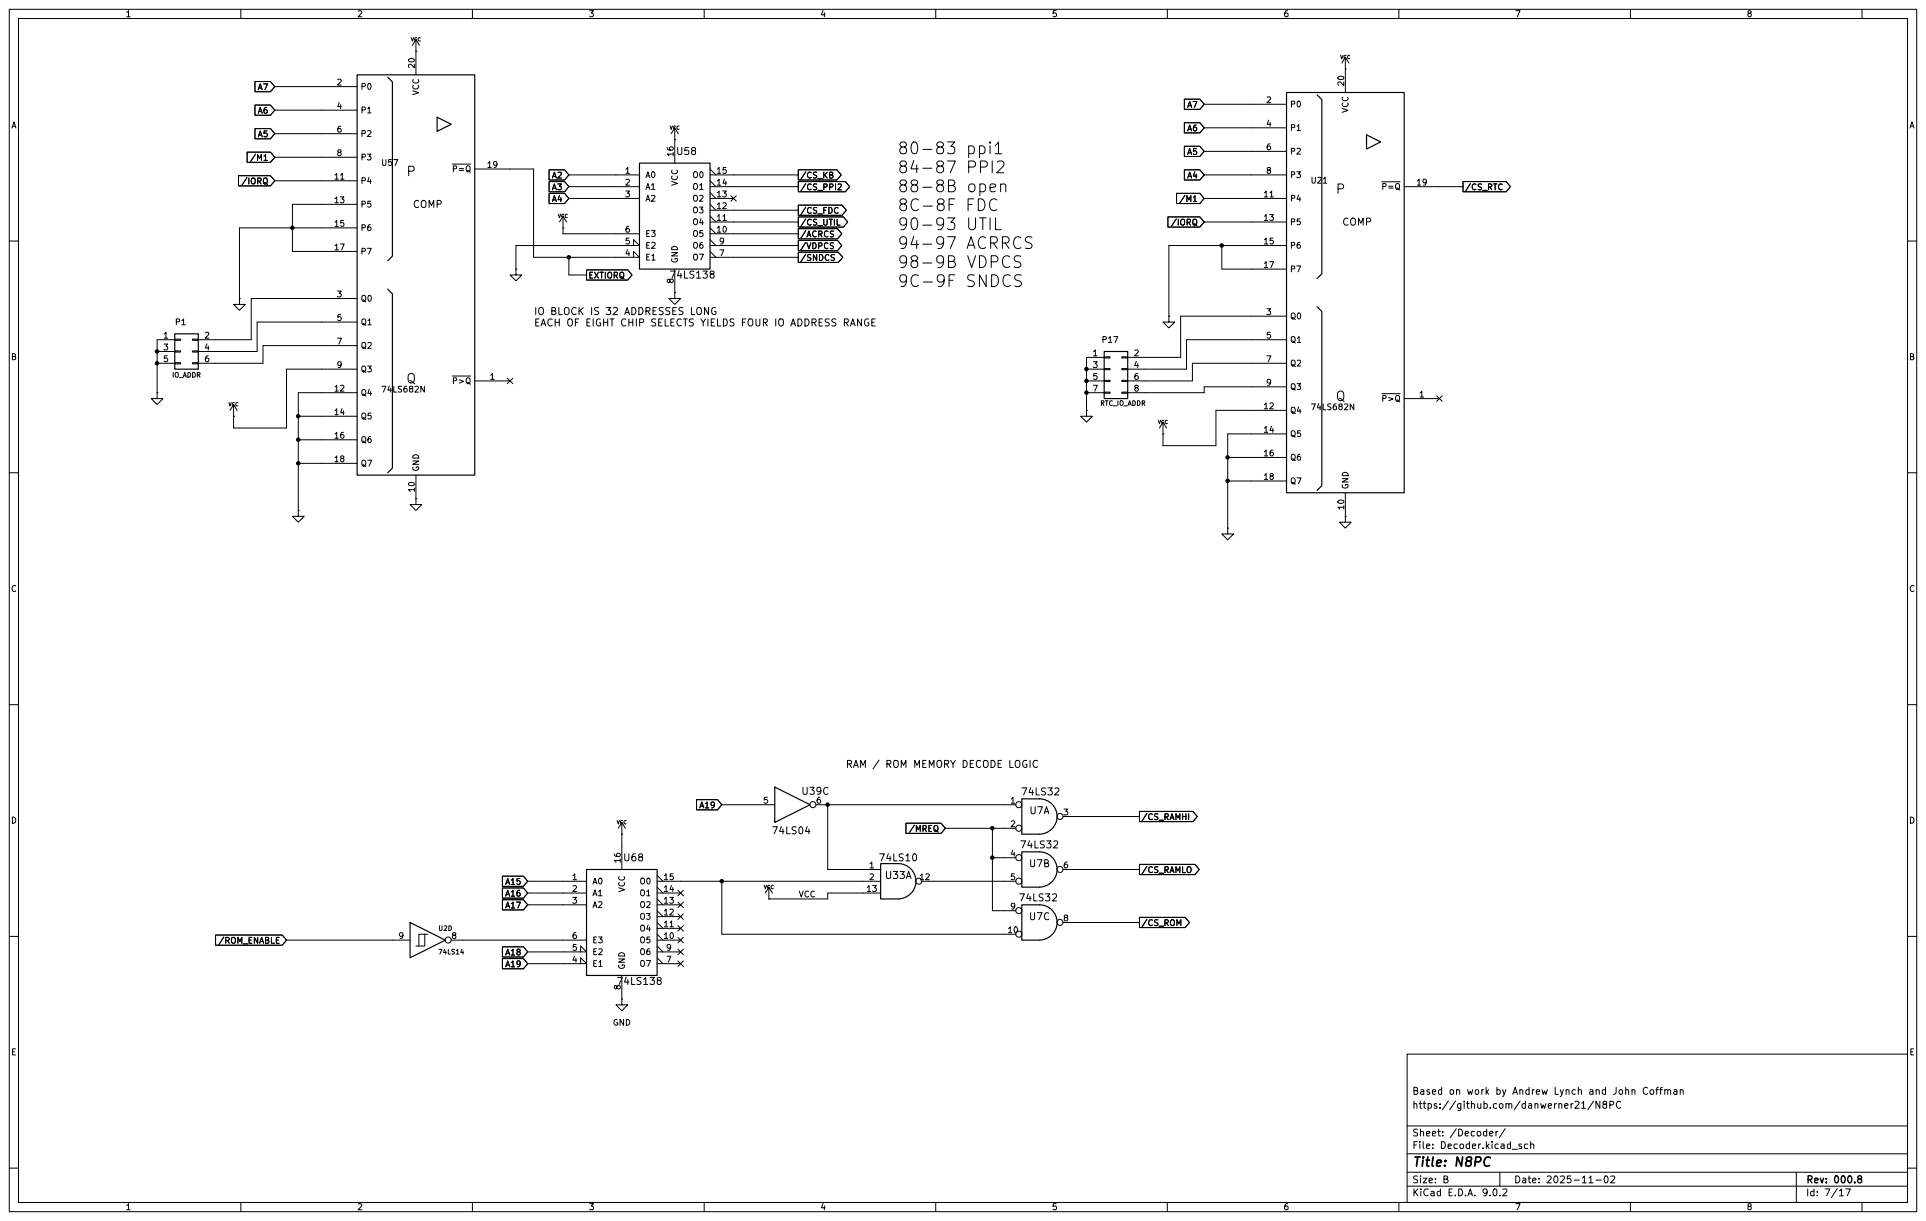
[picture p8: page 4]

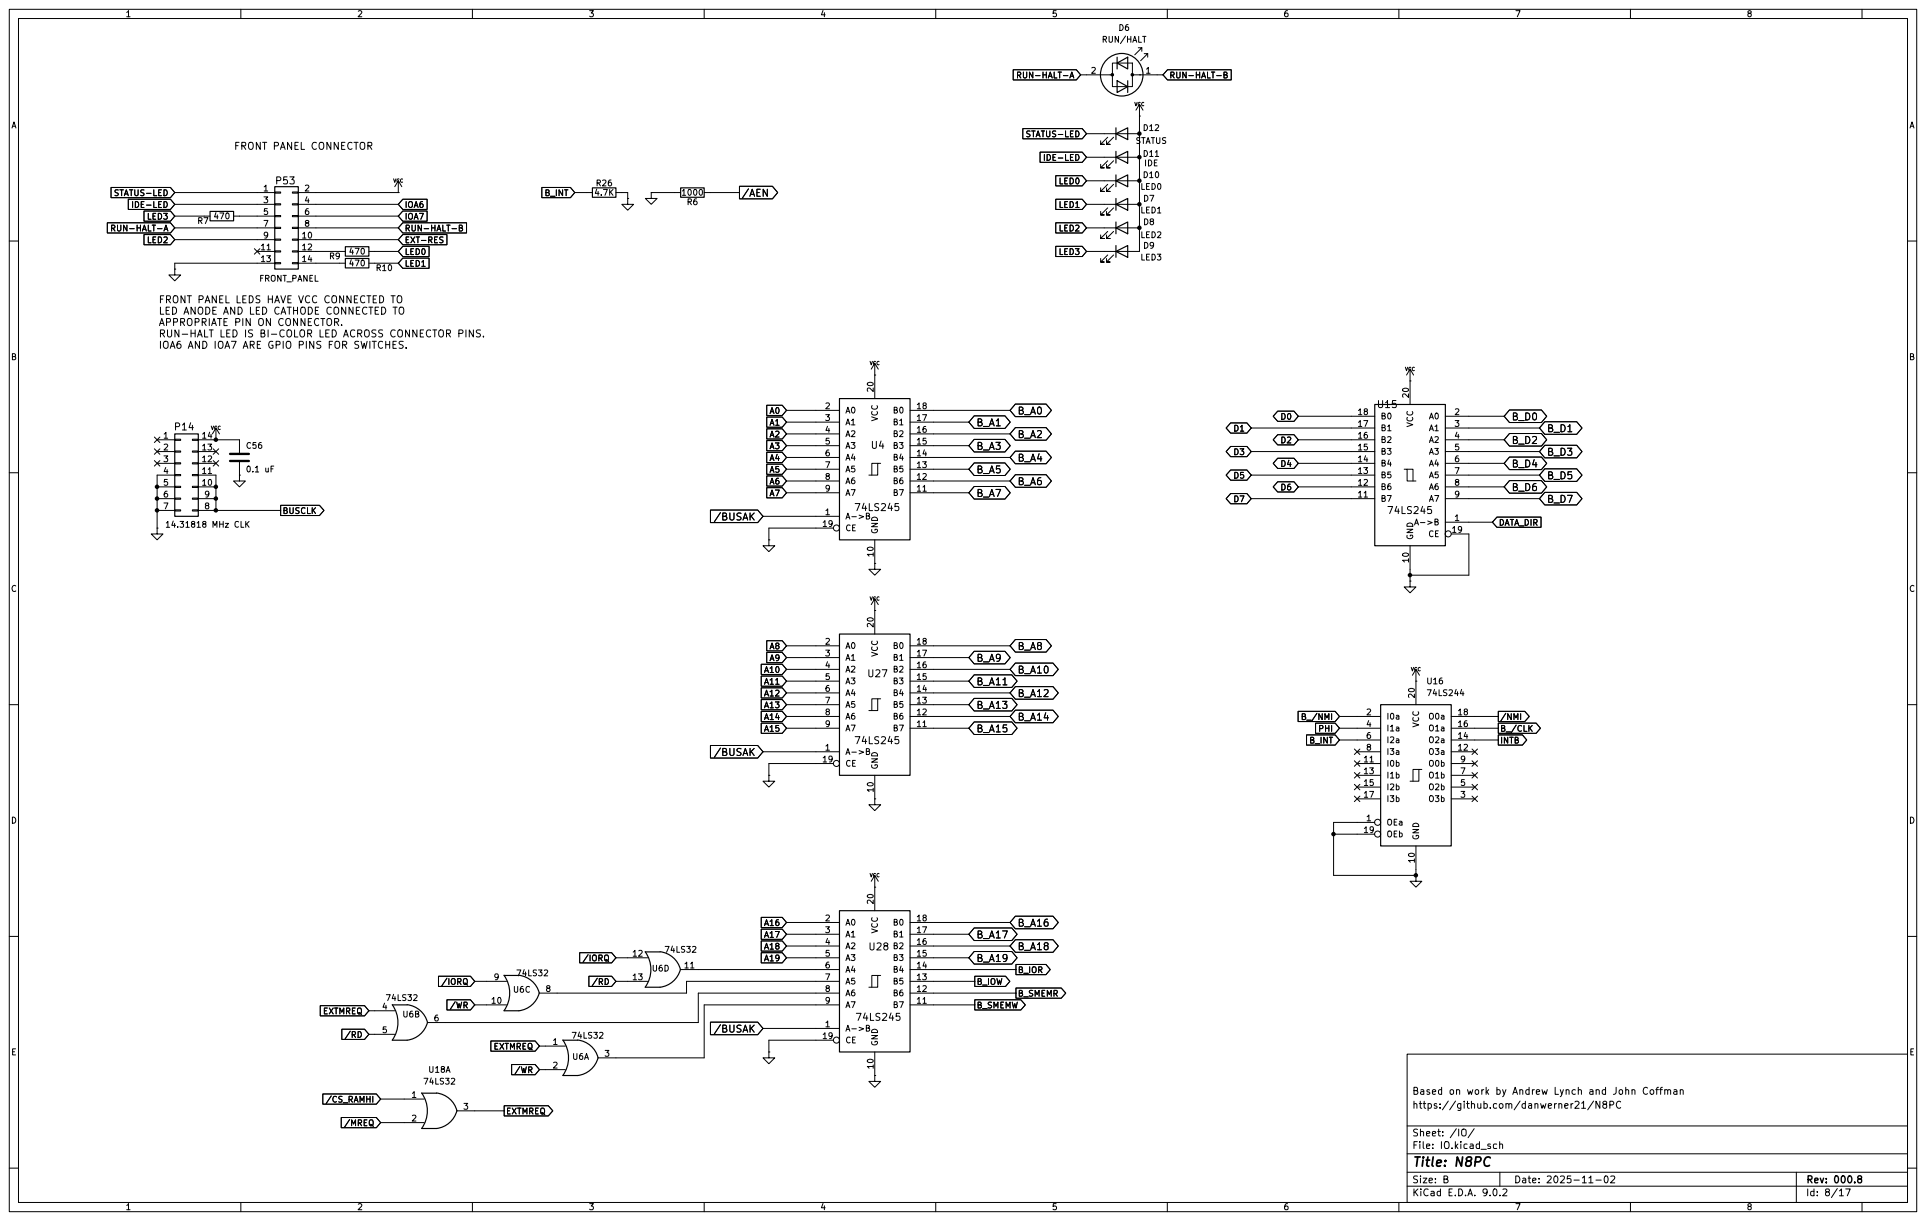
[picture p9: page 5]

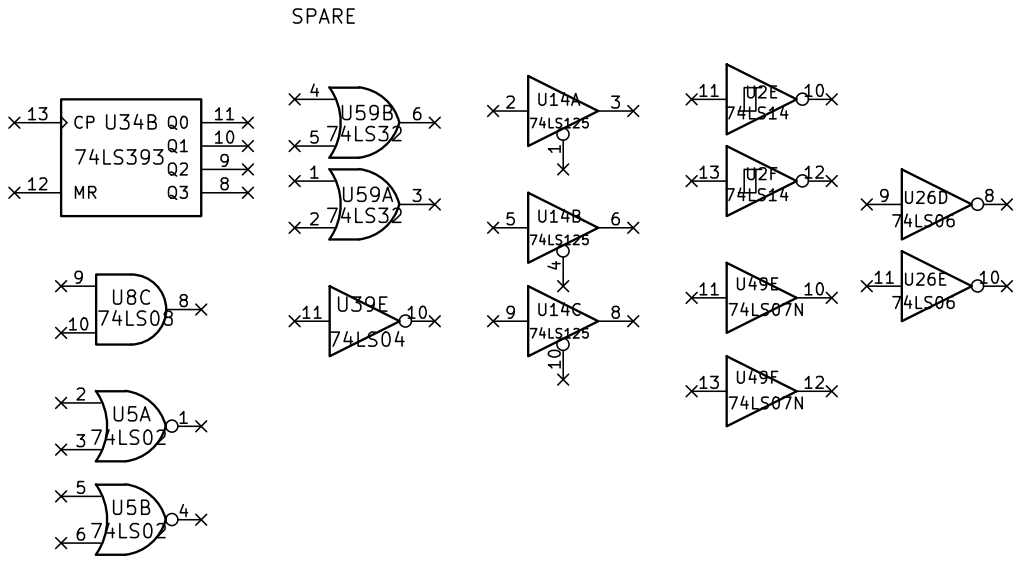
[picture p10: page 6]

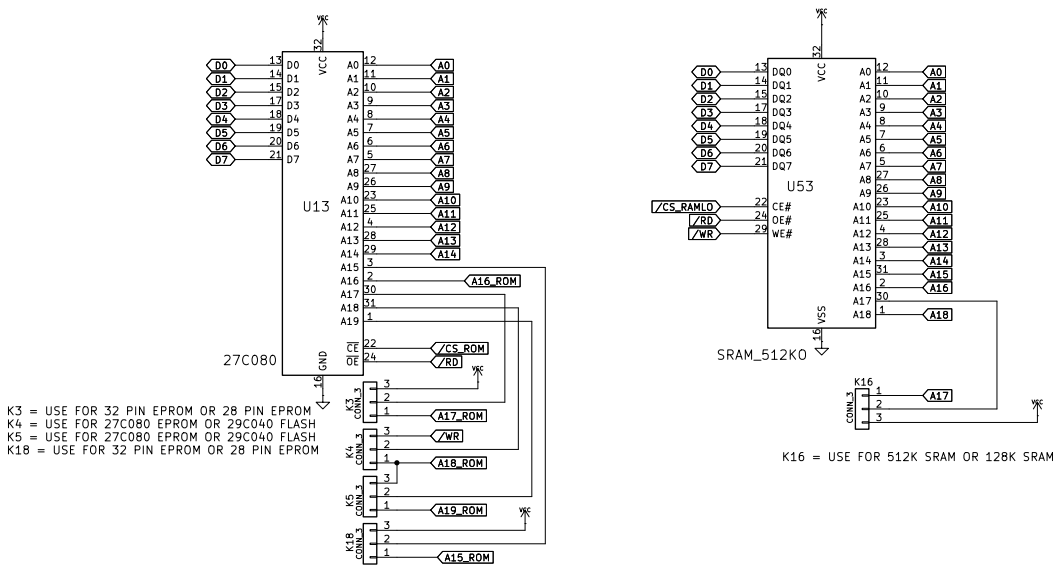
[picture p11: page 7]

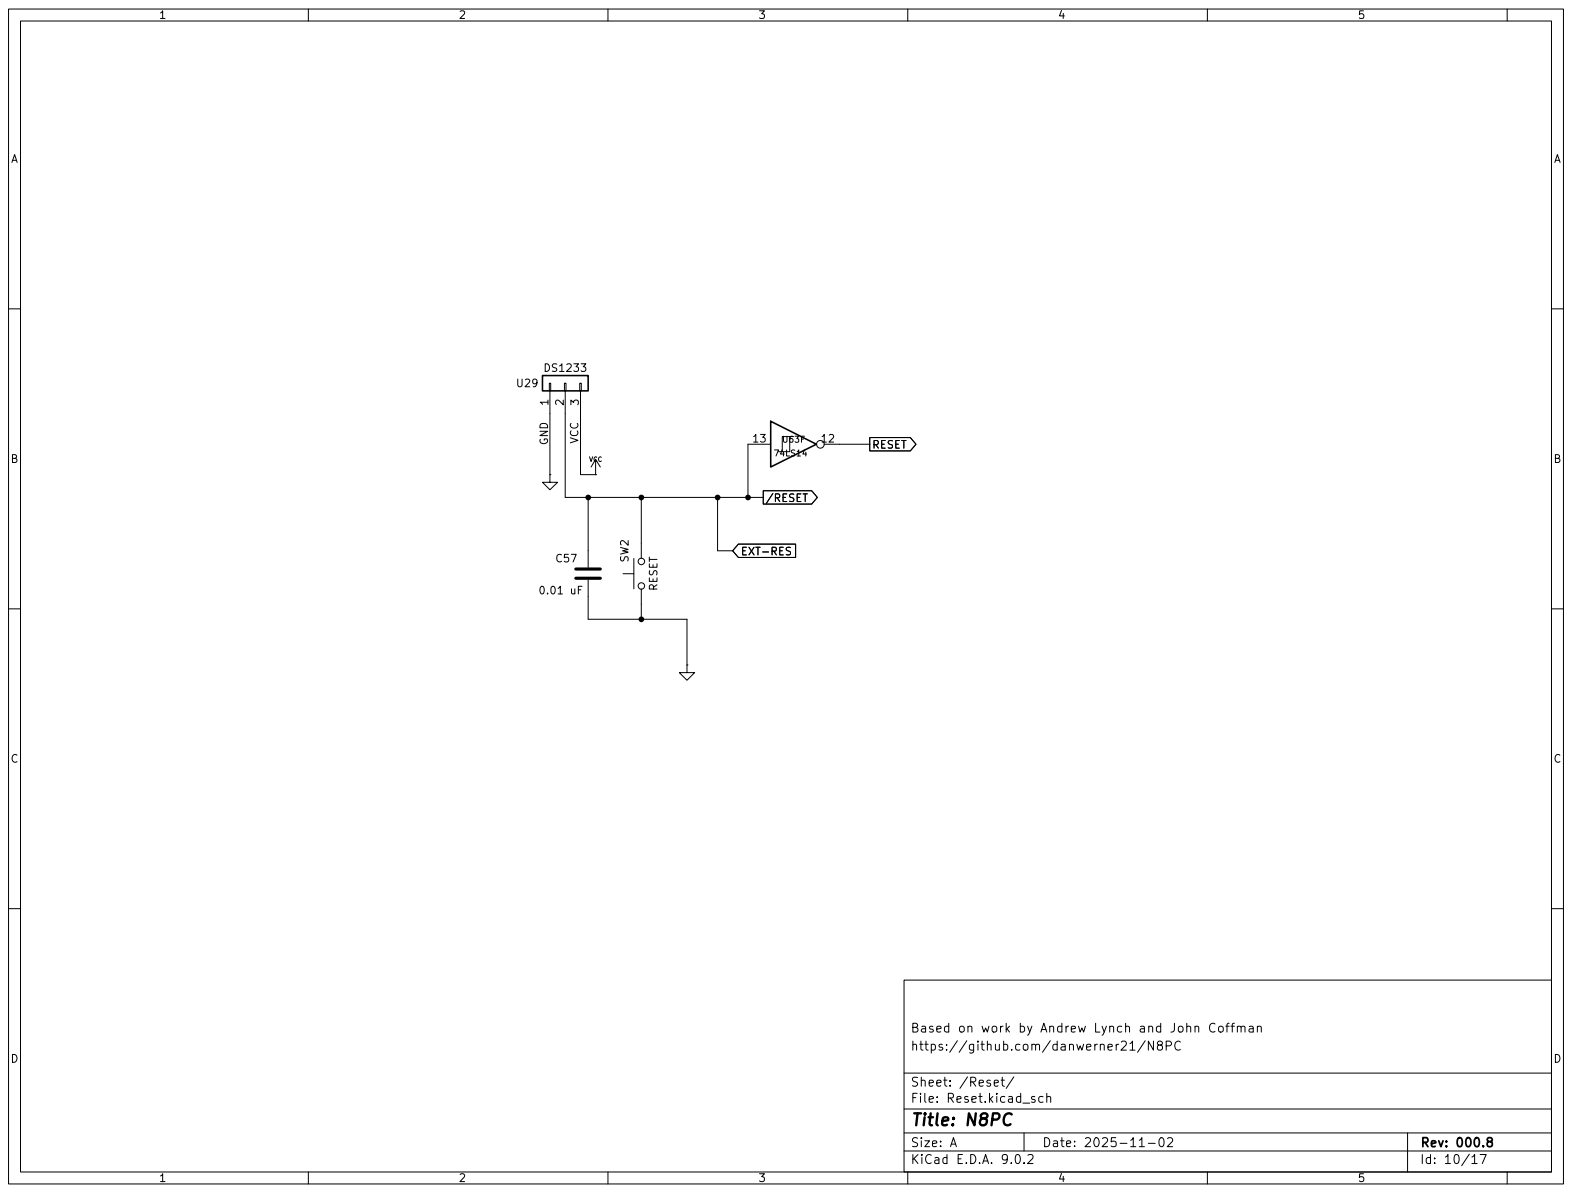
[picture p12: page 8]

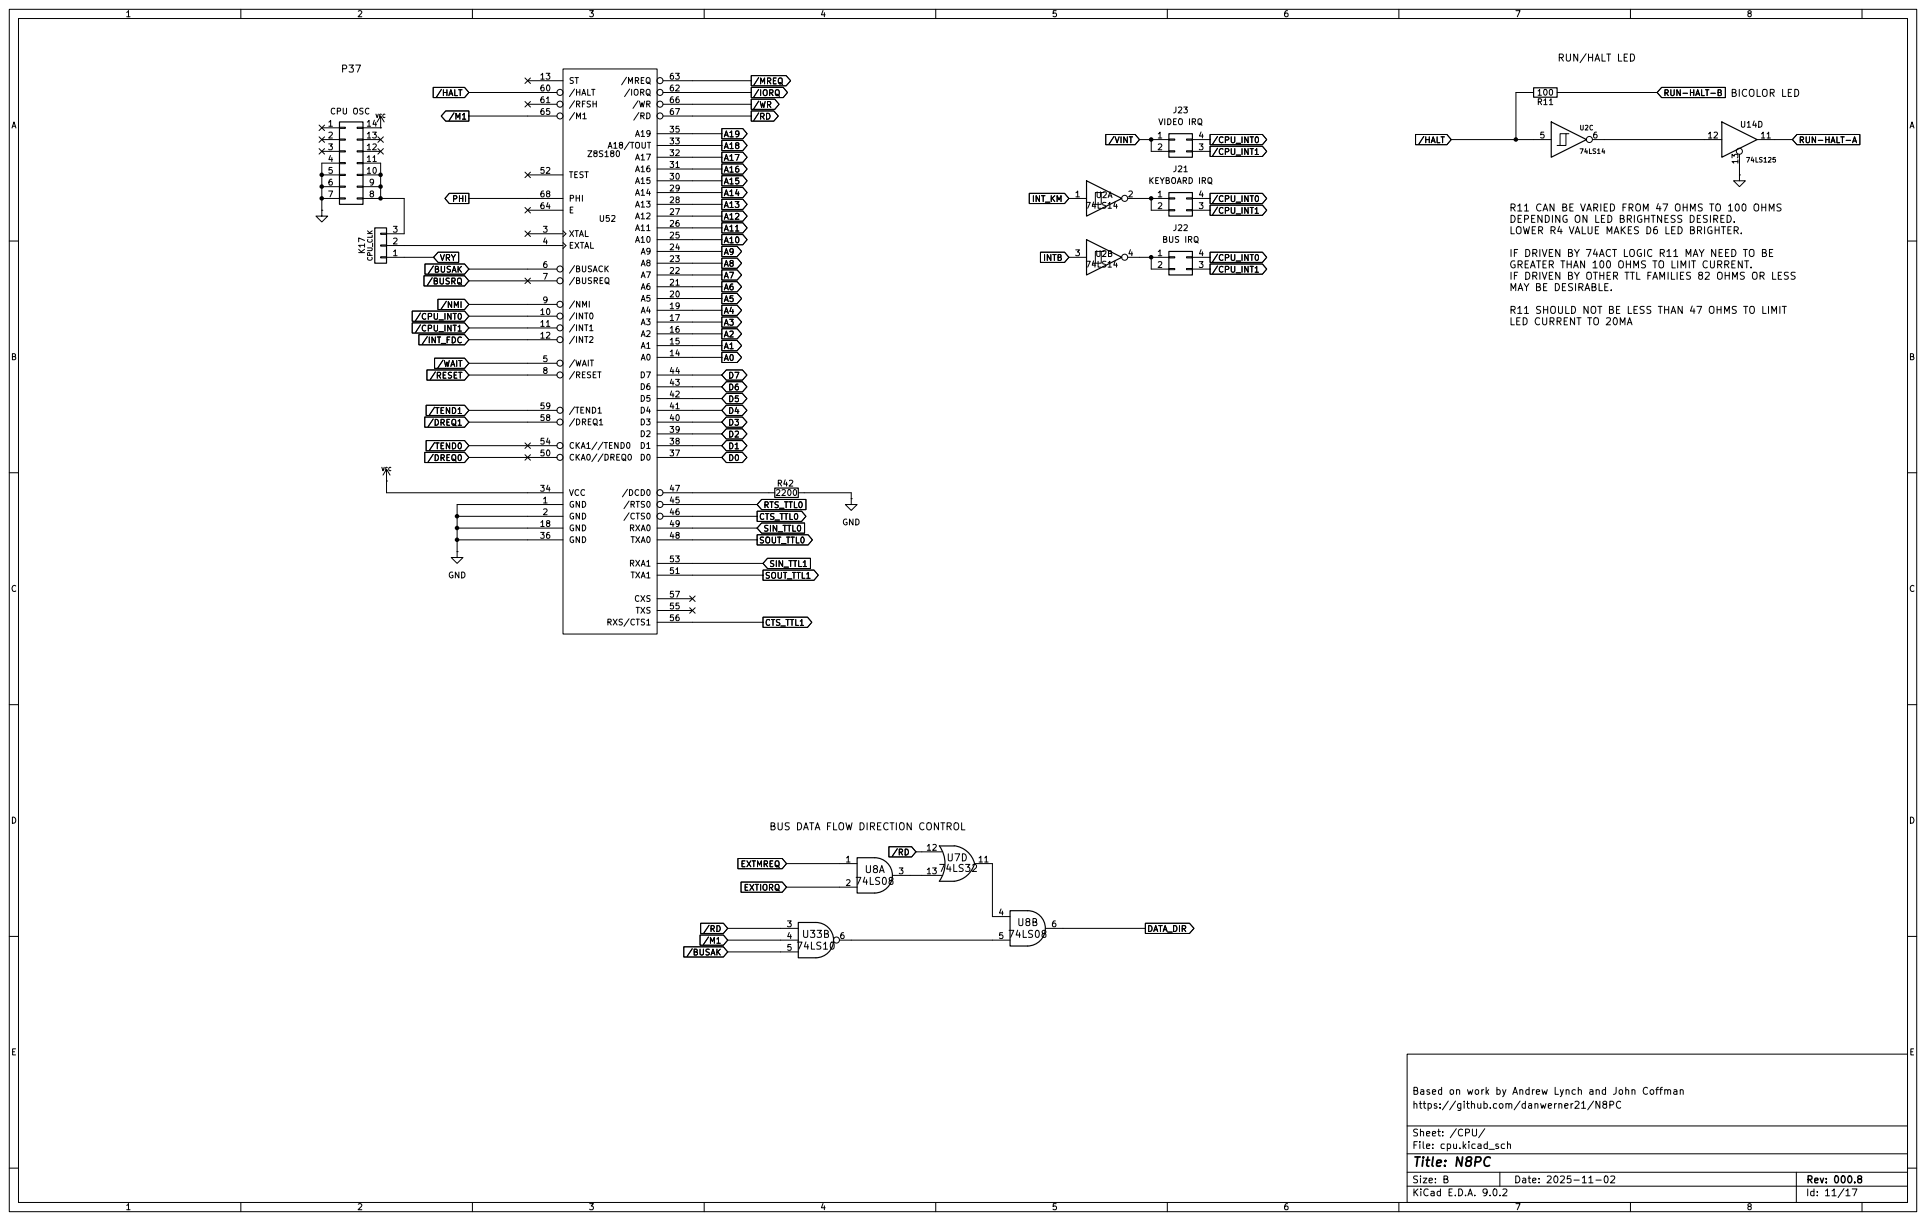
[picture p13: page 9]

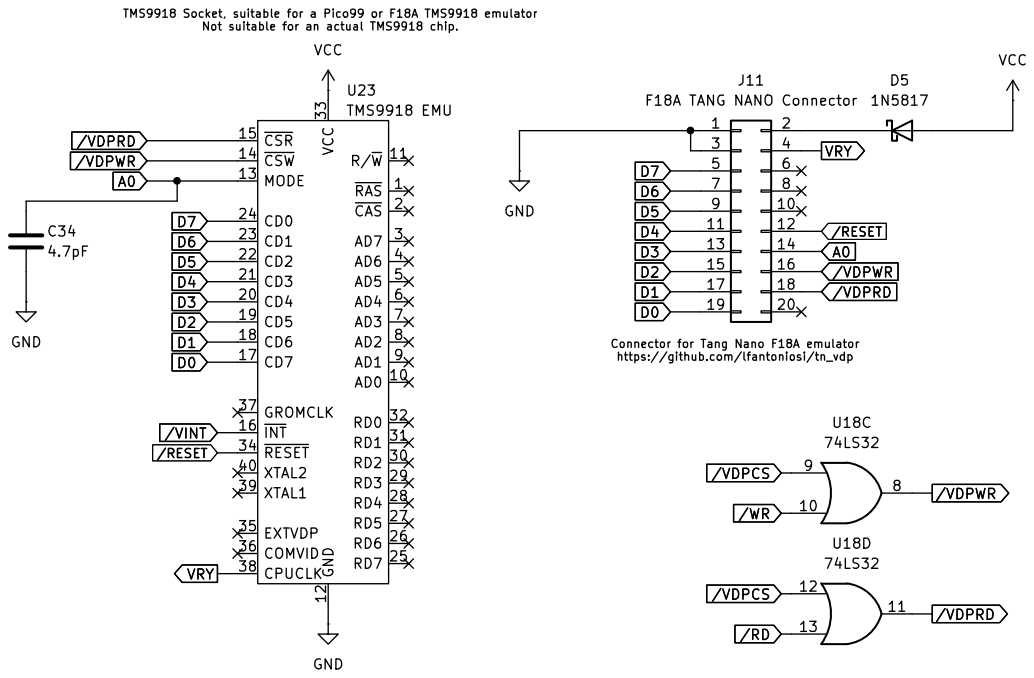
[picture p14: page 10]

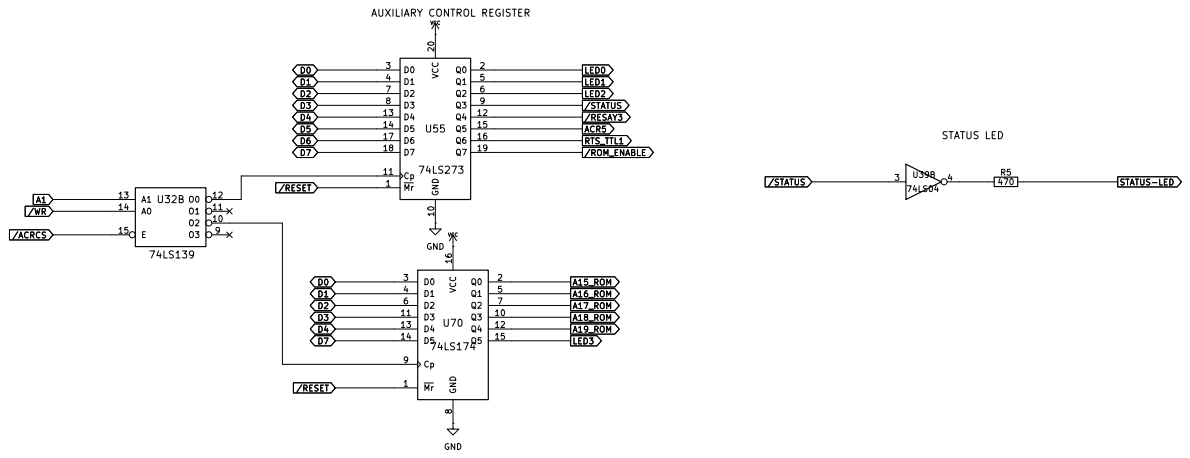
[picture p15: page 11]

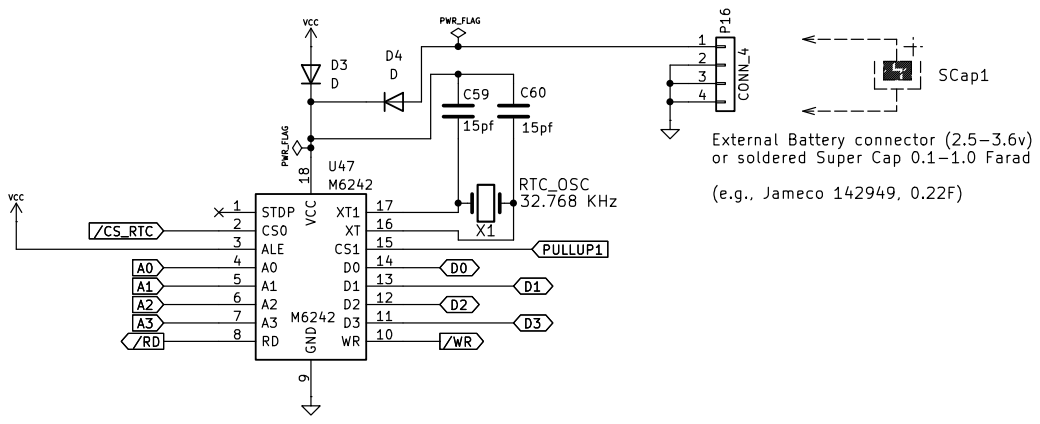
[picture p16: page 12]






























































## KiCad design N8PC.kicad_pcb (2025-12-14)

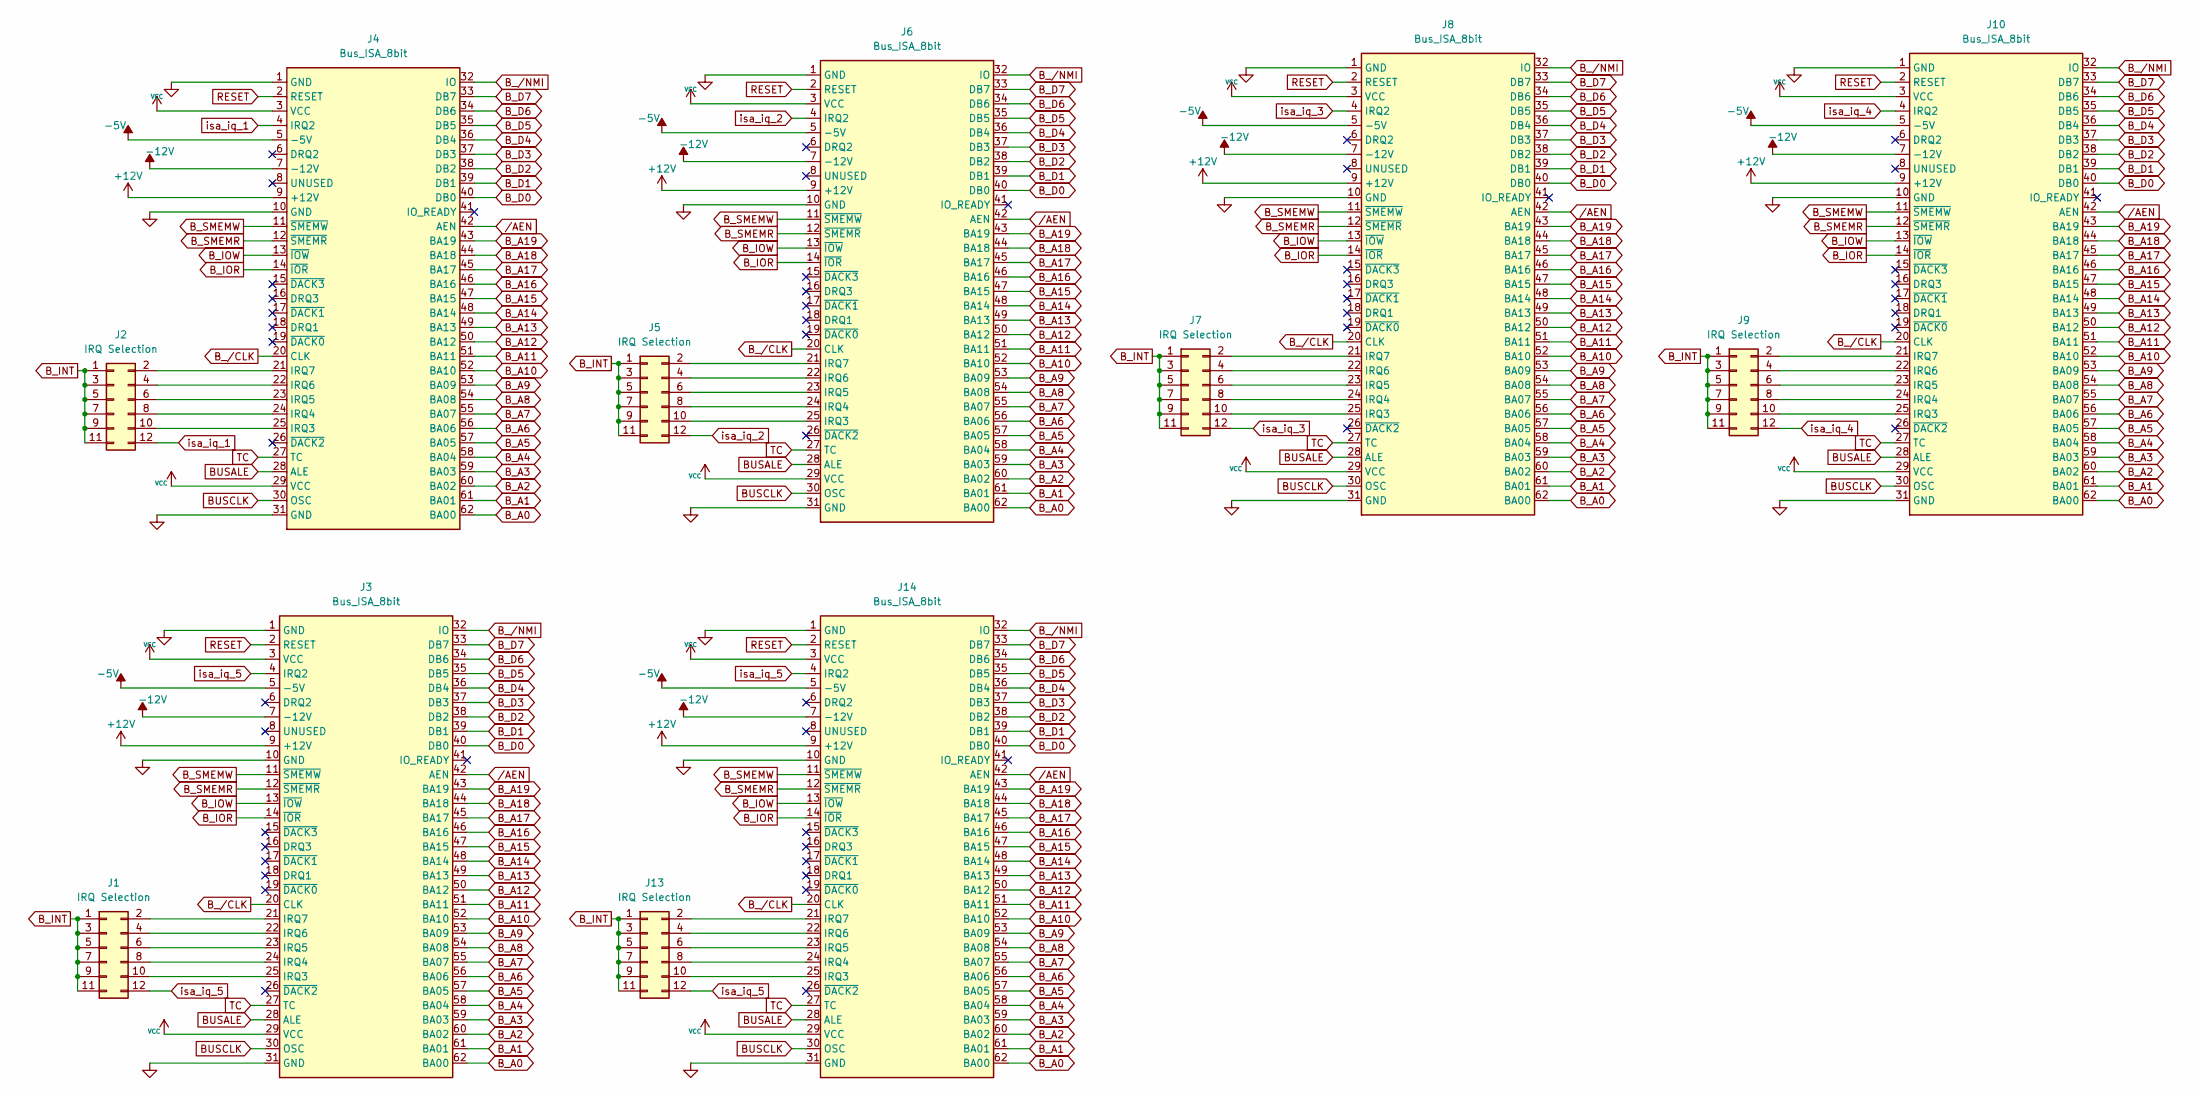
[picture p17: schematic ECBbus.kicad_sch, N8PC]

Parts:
J1, J2, J5, J7, J9, J13: IRQ Selection; STD_DDW_PINHEAD_V_2x06
J3, J4, J6, J8, J10, J14: Bus_ISA_8bit; BUSPC_HOST

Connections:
+5V: J3.3 (VCC), J3.29 (VCC), J4.3 (VCC), J4.29 (VCC), J6.3 (VCC), J6.29 (VCC), J8.3 (VCC), J8.29 (VCC), J10.3 (VCC), J10.29 (VCC), J14.3 (VCC), J14.29 (VCC); also elsewhere on the board
+12V: J3.9 (+12V), J4.9 (+12V), J6.9 (+12V), J8.9 (+12V), J10.9 (+12V), J14.9 (+12V); also elsewhere on the board
-5V: J3.5 (-5V), J4.5 (-5V), J6.5 (-5V), J8.5 (-5V), J10.5 (-5V), J14.5 (-5V); also elsewhere on the board
-12V: J3.7 (-12V), J4.7 (-12V), J6.7 (-12V), J8.7 (-12V), J10.7 (-12V), J14.7 (-12V); also elsewhere on the board
BUSALE: J3.28 (ALE), J4.28 (ALE), J6.28 (ALE), J8.28 (ALE), J10.28 (ALE), J14.28 (ALE)
BUSCLK: J3.30 (OSC), J4.30 (OSC), J6.30 (OSC), J8.30 (OSC), J10.30 (OSC), J14.30 (OSC); also elsewhere on the board
B_A0: J3.62 (BA00), J4.62 (BA00), J6.62 (BA00), J8.62 (BA00), J10.62 (BA00), J14.62 (BA00); also elsewhere on the board
B_A1: J3.61 (BA01), J4.61 (BA01), J6.61 (BA01), J8.61 (BA01), J10.61 (BA01), J14.61 (BA01); also elsewhere on the board
B_A2: J3.60 (BA02), J4.60 (BA02), J6.60 (BA02), J8.60 (BA02), J10.60 (BA02), J14.60 (BA02); also elsewhere on the board
B_A3: J3.59 (BA03), J4.59 (BA03), J6.59 (BA03), J8.59 (BA03), J10.59 (BA03), J14.59 (BA03); also elsewhere on the board
B_A4: J3.58 (BA04), J4.58 (BA04), J6.58 (BA04), J8.58 (BA04), J10.58 (BA04), J14.58 (BA04); also elsewhere on the board
B_A5: J3.57 (BA05), J4.57 (BA05), J6.57 (BA05), J8.57 (BA05), J10.57 (BA05), J14.57 (BA05); also elsewhere on the board
B_A6: J3.56 (BA06), J4.56 (BA06), J6.56 (BA06), J8.56 (BA06), J10.56 (BA06), J14.56 (BA06); also elsewhere on the board
B_A7: J3.55 (BA07), J4.55 (BA07), J6.55 (BA07), J8.55 (BA07), J10.55 (BA07), J14.55 (BA07); also elsewhere on the board
B_A8: J3.54 (BA08), J4.54 (BA08), J6.54 (BA08), J8.54 (BA08), J10.54 (BA08), J14.54 (BA08); also elsewhere on the board
B_A9: J3.53 (BA09), J4.53 (BA09), J6.53 (BA09), J8.53 (BA09), J10.53 (BA09), J14.53 (BA09); also elsewhere on the board
B_A10: J3.52 (BA10), J4.52 (BA10), J6.52 (BA10), J8.52 (BA10), J10.52 (BA10), J14.52 (BA10); also elsewhere on the board
B_A11: J3.51 (BA11), J4.51 (BA11), J6.51 (BA11), J8.51 (BA11), J10.51 (BA11), J14.51 (BA11); also elsewhere on the board
B_A12: J3.50 (BA12), J4.50 (BA12), J6.50 (BA12), J8.50 (BA12), J10.50 (BA12), J14.50 (BA12); also elsewhere on the board
B_A13: J3.49 (BA13), J4.49 (BA13), J6.49 (BA13), J8.49 (BA13), J10.49 (BA13), J14.49 (BA13); also elsewhere on the board
B_A14: J3.48 (BA14), J4.48 (BA14), J6.48 (BA14), J8.48 (BA14), J10.48 (BA14), J14.48 (BA14); also elsewhere on the board
B_A15: J3.47 (BA15), J4.47 (BA15), J6.47 (BA15), J8.47 (BA15), J10.47 (BA15), J14.47 (BA15); also elsewhere on the board
B_A16: J3.46 (BA16), J4.46 (BA16), J6.46 (BA16), J8.46 (BA16), J10.46 (BA16), J14.46 (BA16); also elsewhere on the board
B_A17: J3.45 (BA17), J4.45 (BA17), J6.45 (BA17), J8.45 (BA17), J10.45 (BA17), J14.45 (BA17); also elsewhere on the board
B_A18: J3.44 (BA18), J4.44 (BA18), J6.44 (BA18), J8.44 (BA18), J10.44 (BA18), J14.44 (BA18); also elsewhere on the board
B_A19: J3.43 (BA19), J4.43 (BA19), J6.43 (BA19), J8.43 (BA19), J10.43 (BA19), J14.43 (BA19); also elsewhere on the board
B_D0: J3.40 (DB0), J4.40 (DB0), J6.40 (DB0), J8.40 (DB0), J10.40 (DB0), J14.40 (DB0); also elsewhere on the board
B_D1: J3.39 (DB1), J4.39 (DB1), J6.39 (DB1), J8.39 (DB1), J10.39 (DB1), J14.39 (DB1); also elsewhere on the board
B_D2: J3.38 (DB2), J4.38 (DB2), J6.38 (DB2), J8.38 (DB2), J10.38 (DB2), J14.38 (DB2); also elsewhere on the board
B_D3: J3.37 (DB3), J4.37 (DB3), J6.37 (DB3), J8.37 (DB3), J10.37 (DB3), J14.37 (DB3); also elsewhere on the board
B_D4: J3.36 (DB4), J4.36 (DB4), J6.36 (DB4), J8.36 (DB4), J10.36 (DB4), J14.36 (DB4); also elsewhere on the board
B_D5: J3.35 (DB5), J4.35 (DB5), J6.35 (DB5), J8.35 (DB5), J10.35 (DB5), J14.35 (DB5); also elsewhere on the board
B_D6: J3.34 (DB6), J4.34 (DB6), J6.34 (DB6), J8.34 (DB6), J10.34 (DB6), J14.34 (DB6); also elsewhere on the board
B_D7: J3.33 (DB7), J4.33 (DB7), J6.33 (DB7), J8.33 (DB7), J10.33 (DB7), J14.33 (DB7); also elsewhere on the board
B_INT: J1.1, J1.3, J1.5, J1.7, J1.9, J1.11, J2.1, J2.3, J2.5, J2.7, J2.9, J2.11, J5.1, J5.3, J5.5, J5.7, J5.9, J5.11, J7.1, J7.3, J7.5, J7.7, J7.9, J7.11, J9.1, J9.3, J9.5, J9.7, J9.9, J9.11, J13.1, J13.3, J13.5, J13.7, J13.9, J13.11; also elsewhere on the board
B_IOR: J3.14 (~IOR), J4.14 (~IOR), J6.14 (~IOR), J8.14 (~IOR), J10.14 (~IOR), J14.14 (~IOR); also elsewhere on the board
B_IOW: J3.13 (~IOW), J4.13 (~IOW), J6.13 (~IOW), J8.13 (~IOW), J10.13 (~IOW), J14.13 (~IOW); also elsewhere on the board
B_SMEMR: J3.12 (~SMEMR), J4.12 (~SMEMR), J6.12 (~SMEMR), J8.12 (~SMEMR), J10.12 (~SMEMR), J14.12 (~SMEMR); also elsewhere on the board
B_SMEMW: J3.11 (~SMEMW), J4.11 (~SMEMW), J6.11 (~SMEMW), J8.11 (~SMEMW), J10.11 (~SMEMW), J14.11 (~SMEMW); also elsewhere on the board
B_/CLK: J3.20 (CLK), J4.20 (CLK), J6.20 (CLK), J8.20 (CLK), J10.20 (CLK), J14.20 (CLK); also elsewhere on the board
B_/NMI: J3.32 (IO), J4.32 (IO), J6.32 (IO), J8.32 (IO), J10.32 (IO), J14.32 (IO); also elsewhere on the board
GND: J3.1 (GND), J3.10 (GND), J3.31 (GND), J4.1 (GND), J4.10 (GND), J4.31 (GND), J6.1 (GND), J6.10 (GND), J6.31 (GND), J8.1 (GND), J8.10 (GND), J8.31 (GND), J10.1 (GND), J10.10 (GND), J10.31 (GND), J14.1 (GND), J14.10 (GND), J14.31 (GND); also elsewhere on the board
unnamed: J1.2, J3.21 (IRQ7)
unnamed: J1.4, J3.22 (IRQ6)
unnamed: J1.6, J3.23 (IRQ5)
unnamed: J1.8, J3.24 (IRQ4)
unnamed: J1.10, J3.25 (IRQ3)
unnamed: J2.2, J4.21 (IRQ7)
unnamed: J2.4, J4.22 (IRQ6)
unnamed: J2.6, J4.23 (IRQ5)
unnamed: J2.8, J4.24 (IRQ4)
unnamed: J2.10, J4.25 (IRQ3)
unnamed: J5.2, J6.21 (IRQ7)
unnamed: J5.4, J6.22 (IRQ6)
unnamed: J5.6, J6.23 (IRQ5)
unnamed: J5.8, J6.24 (IRQ4)
unnamed: J5.10, J6.25 (IRQ3)
unnamed: J7.2, J8.21 (IRQ7)
unnamed: J7.4, J8.22 (IRQ6)
unnamed: J7.6, J8.23 (IRQ5)
unnamed: J7.8, J8.24 (IRQ4)
unnamed: J7.10, J8.25 (IRQ3)
unnamed: J9.10, J10.25 (IRQ3)
unnamed: J9.8, J10.24 (IRQ4)
unnamed: J9.6, J10.23 (IRQ5)
unnamed: J9.4, J10.22 (IRQ6)
unnamed: J9.2, J10.21 (IRQ7)
unnamed: J13.2, J14.21 (IRQ7)
unnamed: J13.4, J14.22 (IRQ6)
unnamed: J13.6, J14.23 (IRQ5)
unnamed: J13.8, J14.24 (IRQ4)
unnamed: J13.10, J14.25 (IRQ3)
RESET: J3.2 (RESET), J4.2 (RESET), J6.2 (RESET), J8.2 (RESET), J10.2 (RESET), J14.2 (RESET); also elsewhere on the board
TC: J3.27 (TC), J4.27 (TC), J6.27 (TC), J8.27 (TC), J10.27 (TC), J14.27 (TC)
isa_iq_1: J2.12, J4.4 (IRQ2)
isa_iq_2: J5.12, J6.4 (IRQ2)
isa_iq_3: J7.12, J8.4 (IRQ2)
isa_iq_4: J9.12, J10.4 (IRQ2)
isa_iq_5: J1.12, J3.4 (IRQ2), J13.12, J14.4 (IRQ2)
/AEN: J3.42 (AEN), J4.42 (AEN), J6.42 (AEN), J8.42 (AEN), J10.42 (AEN), J14.42 (AEN); also elsewhere on the board

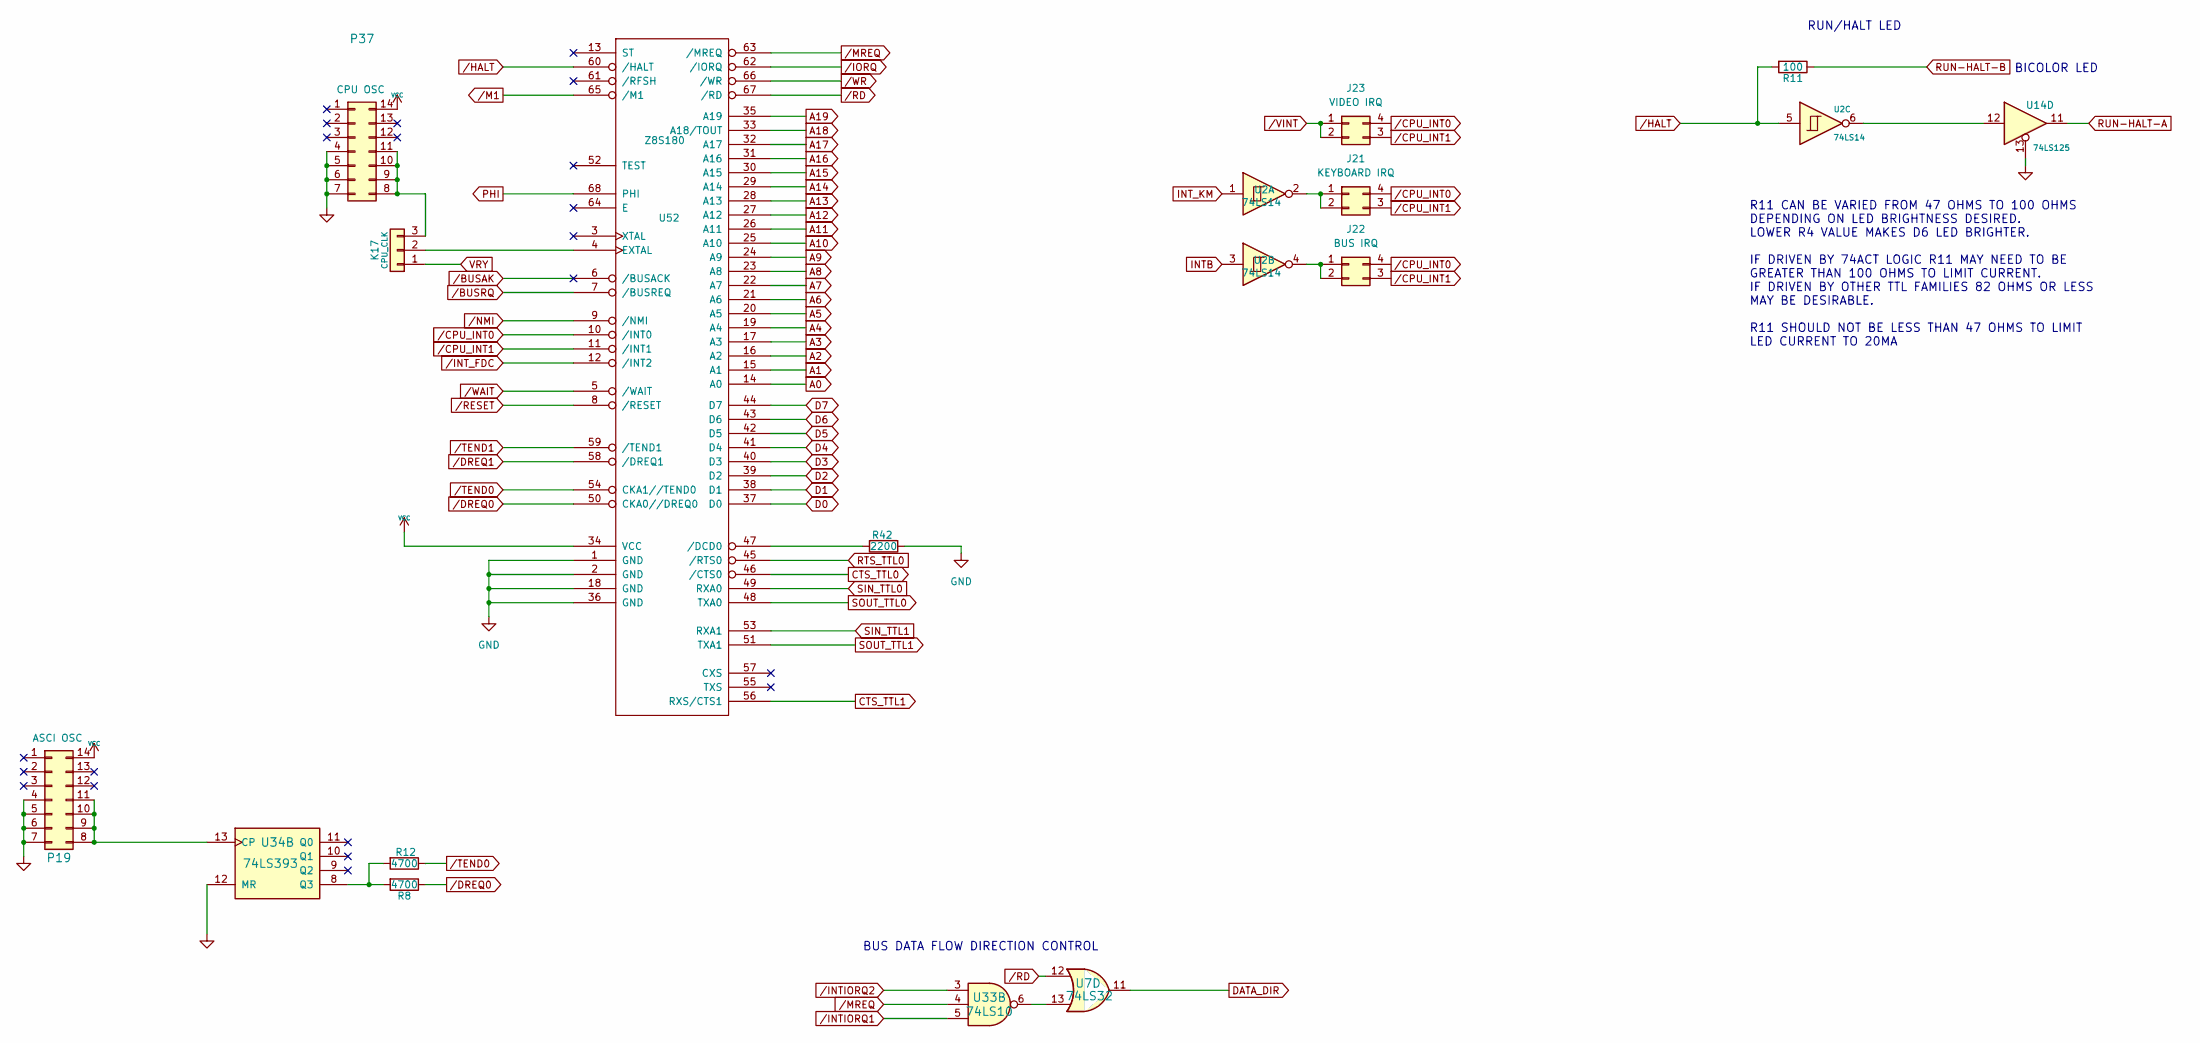
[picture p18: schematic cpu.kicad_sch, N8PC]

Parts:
J21: KEYBOARD IRQ; STD_DDW_PinHeader_2x02
J22: BUS IRQ; STD_DDW_PinHeader_2x02
J23: VIDEO IRQ; STD_DDW_PinHeader_2x02
K17: CPU_CLK; STD_DDW_PINHEAD_V_1x03
P19: ASCI OSC; STD_DDW_DIP14
P37: CPU OSC; STD_DDW_DIP14
R8, R12: 4700; STD_DDW_RESISTOR
R11: 100; STD_DDW_RESISTOR
R42: 2200; STD_DDW_RESISTOR
U2: 74LS14; STD_DDW_DIP14
U7: 74LS32; STD_DDW_DIP14
U14: 74LS125; STD_DDW_DIP14
U33: 74LS10; STD_DDW_DIP14
U34: 74LS393; STD_DDW_DIP14
U52: Z8S180; STD_DDW_PLCC-68

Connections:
+5V: P19.14, P37.14, U52.34 (VCC); also elsewhere on the board
A0: U52.14 (A0); also elsewhere on the board
A1: U52.15 (A1); also elsewhere on the board
A2: U52.16 (A2); also elsewhere on the board
A3: U52.17 (A3); also elsewhere on the board
A4: U52.19 (A4); also elsewhere on the board
A5: U52.20 (A5); also elsewhere on the board
A6: U52.21 (A6); also elsewhere on the board
A7: U52.22 (A7); also elsewhere on the board
A8: U52.23 (A8); also elsewhere on the board
A9: U52.24 (A9); also elsewhere on the board
A10: U52.25 (A10); also elsewhere on the board
A11: U52.26 (A11); also elsewhere on the board
A12: U52.27 (A12); also elsewhere on the board
A13: U52.28 (A13); also elsewhere on the board
A14: U52.29 (A14); also elsewhere on the board
A15: U52.30 (A15); also elsewhere on the board
A16: U52.31 (A16); also elsewhere on the board
A17: U52.32 (A17); also elsewhere on the board
A18: U52.33 (A18/TOUT); also elsewhere on the board
A19: U52.35 (A19); also elsewhere on the board
CTS_TTL0: U52.46 (/CTS0); also elsewhere on the board
CTS_TTL1: U52.56 (RXS/CTS1); also elsewhere on the board
D0: U52.37 (D0); also elsewhere on the board
D1: U52.38 (D1); also elsewhere on the board
D2: U52.39 (D2); also elsewhere on the board
D3: U52.40 (D3); also elsewhere on the board
D4: U52.41 (D4); also elsewhere on the board
D5: U52.42 (D5); also elsewhere on the board
D6: U52.43 (D6); also elsewhere on the board
D7: U52.44 (D7); also elsewhere on the board
DATA_DIR: U7.11; also elsewhere on the board
EXT-RES: U52.8 (/RESET); also elsewhere on the board
GND: P19.4, P19.5, P19.6, P19.7, P37.4, P37.5, P37.6, P37.7, R42.1, U14.13, U34.12 (MR), U52.1 (GND), U52.2 (GND), U52.18 (GND), U52.36 (GND); also elsewhere on the board
INTB: U2.3; also elsewhere on the board
INT_KM: U2.1; also elsewhere on the board
unnamed: J21.1, J21.2, U2.2
unnamed: J22.1, J22.2, U2.4
unnamed: K17.2, U52.4 (EXTAL)
unnamed: K17.3, P37.8, P37.9, P37.10, P37.11
unnamed: U2.6, U14.12
unnamed: U7.13, U33.6
unnamed: P19.8, P19.9, P19.10, P19.11, U34.13 (CP)
unnamed: R8.2, R12.2, U34.8 (Q3)
unnamed: R42.2, U52.47 (/DCD0)
PHI: U52.68 (PHI); also elsewhere on the board
RTS_TTL0: U52.45 (/RTS0); also elsewhere on the board
RUN-HALT-A: U14.11; also elsewhere on the board
RUN-HALT-B: R11.1; also elsewhere on the board
SIN_TTL0: U52.49 (RXA0); also elsewhere on the board
SIN_TTL1: U52.53 (RXA1); also elsewhere on the board
SOUT_TTL0: U52.48 (TXA0); also elsewhere on the board
SOUT_TTL1: U52.51 (TXA1); also elsewhere on the board
VRY: K17.1; also elsewhere on the board
/BUSAK: U52.6 (/BUSACK)
/BUSRQ: U52.7 (/BUSREQ); also elsewhere on the board
/CPU_INT0: J21.4, J22.4, J23.4, U52.10 (/INT0); also elsewhere on the board
/CPU_INT1: J21.3, J22.3, J23.3, U52.11 (/INT1); also elsewhere on the board
/DREQ0: R8.1, U52.50 (CKA0//DREQ0)
/DREQ1: U52.58 (/DREQ1); also elsewhere on the board
/HALT: R11.2, U2.5, U52.60 (/HALT)
/INTIORQ1: U33.5; also elsewhere on the board
/INTIORQ2: U33.3; also elsewhere on the board
/INT_FDC: U52.12 (/INT2); also elsewhere on the board
/IORQ: U52.62 (/IORQ); also elsewhere on the board
/M1: U52.65 (/M1); also elsewhere on the board
/MREQ: U33.4, U52.63 (/MREQ); also elsewhere on the board
/NMI: U52.9 (/NMI); also elsewhere on the board
/RD: U7.12, U52.67 (/RD); also elsewhere on the board
/TEND0: R12.1, U52.54 (CKA1//TEND0)
/TEND1: U52.59 (/TEND1); also elsewhere on the board
/VINT: J23.1, J23.2; also elsewhere on the board
/WAIT: U52.5 (/WAIT); also elsewhere on the board
/WR: U52.66 (/WR); also elsewhere on the board

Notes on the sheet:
RUN/HALT LED
BUS DATA FLOW DIRECTION CONTROL
BICOLOR LED
R11 CAN BE VARIED FROM 47 OHMS TO 100 OHMS DEPENDING ON LED BRIGHTNESS DESIRED. LOWER R4 VALUE MAKES D6 LED BRIGHTER. IF DRIVEN BY 74ACT LOGIC R11 MAY NEED TO BE GREATER THAN 100 OHMS TO LIMIT CURRENT. IF DRIVEN BY OTHER TTL FAMILIES 82 OHMS OR LESS MAY BE DESIRABLE. R11 SHOULD NOT BE LESS THAN 47 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

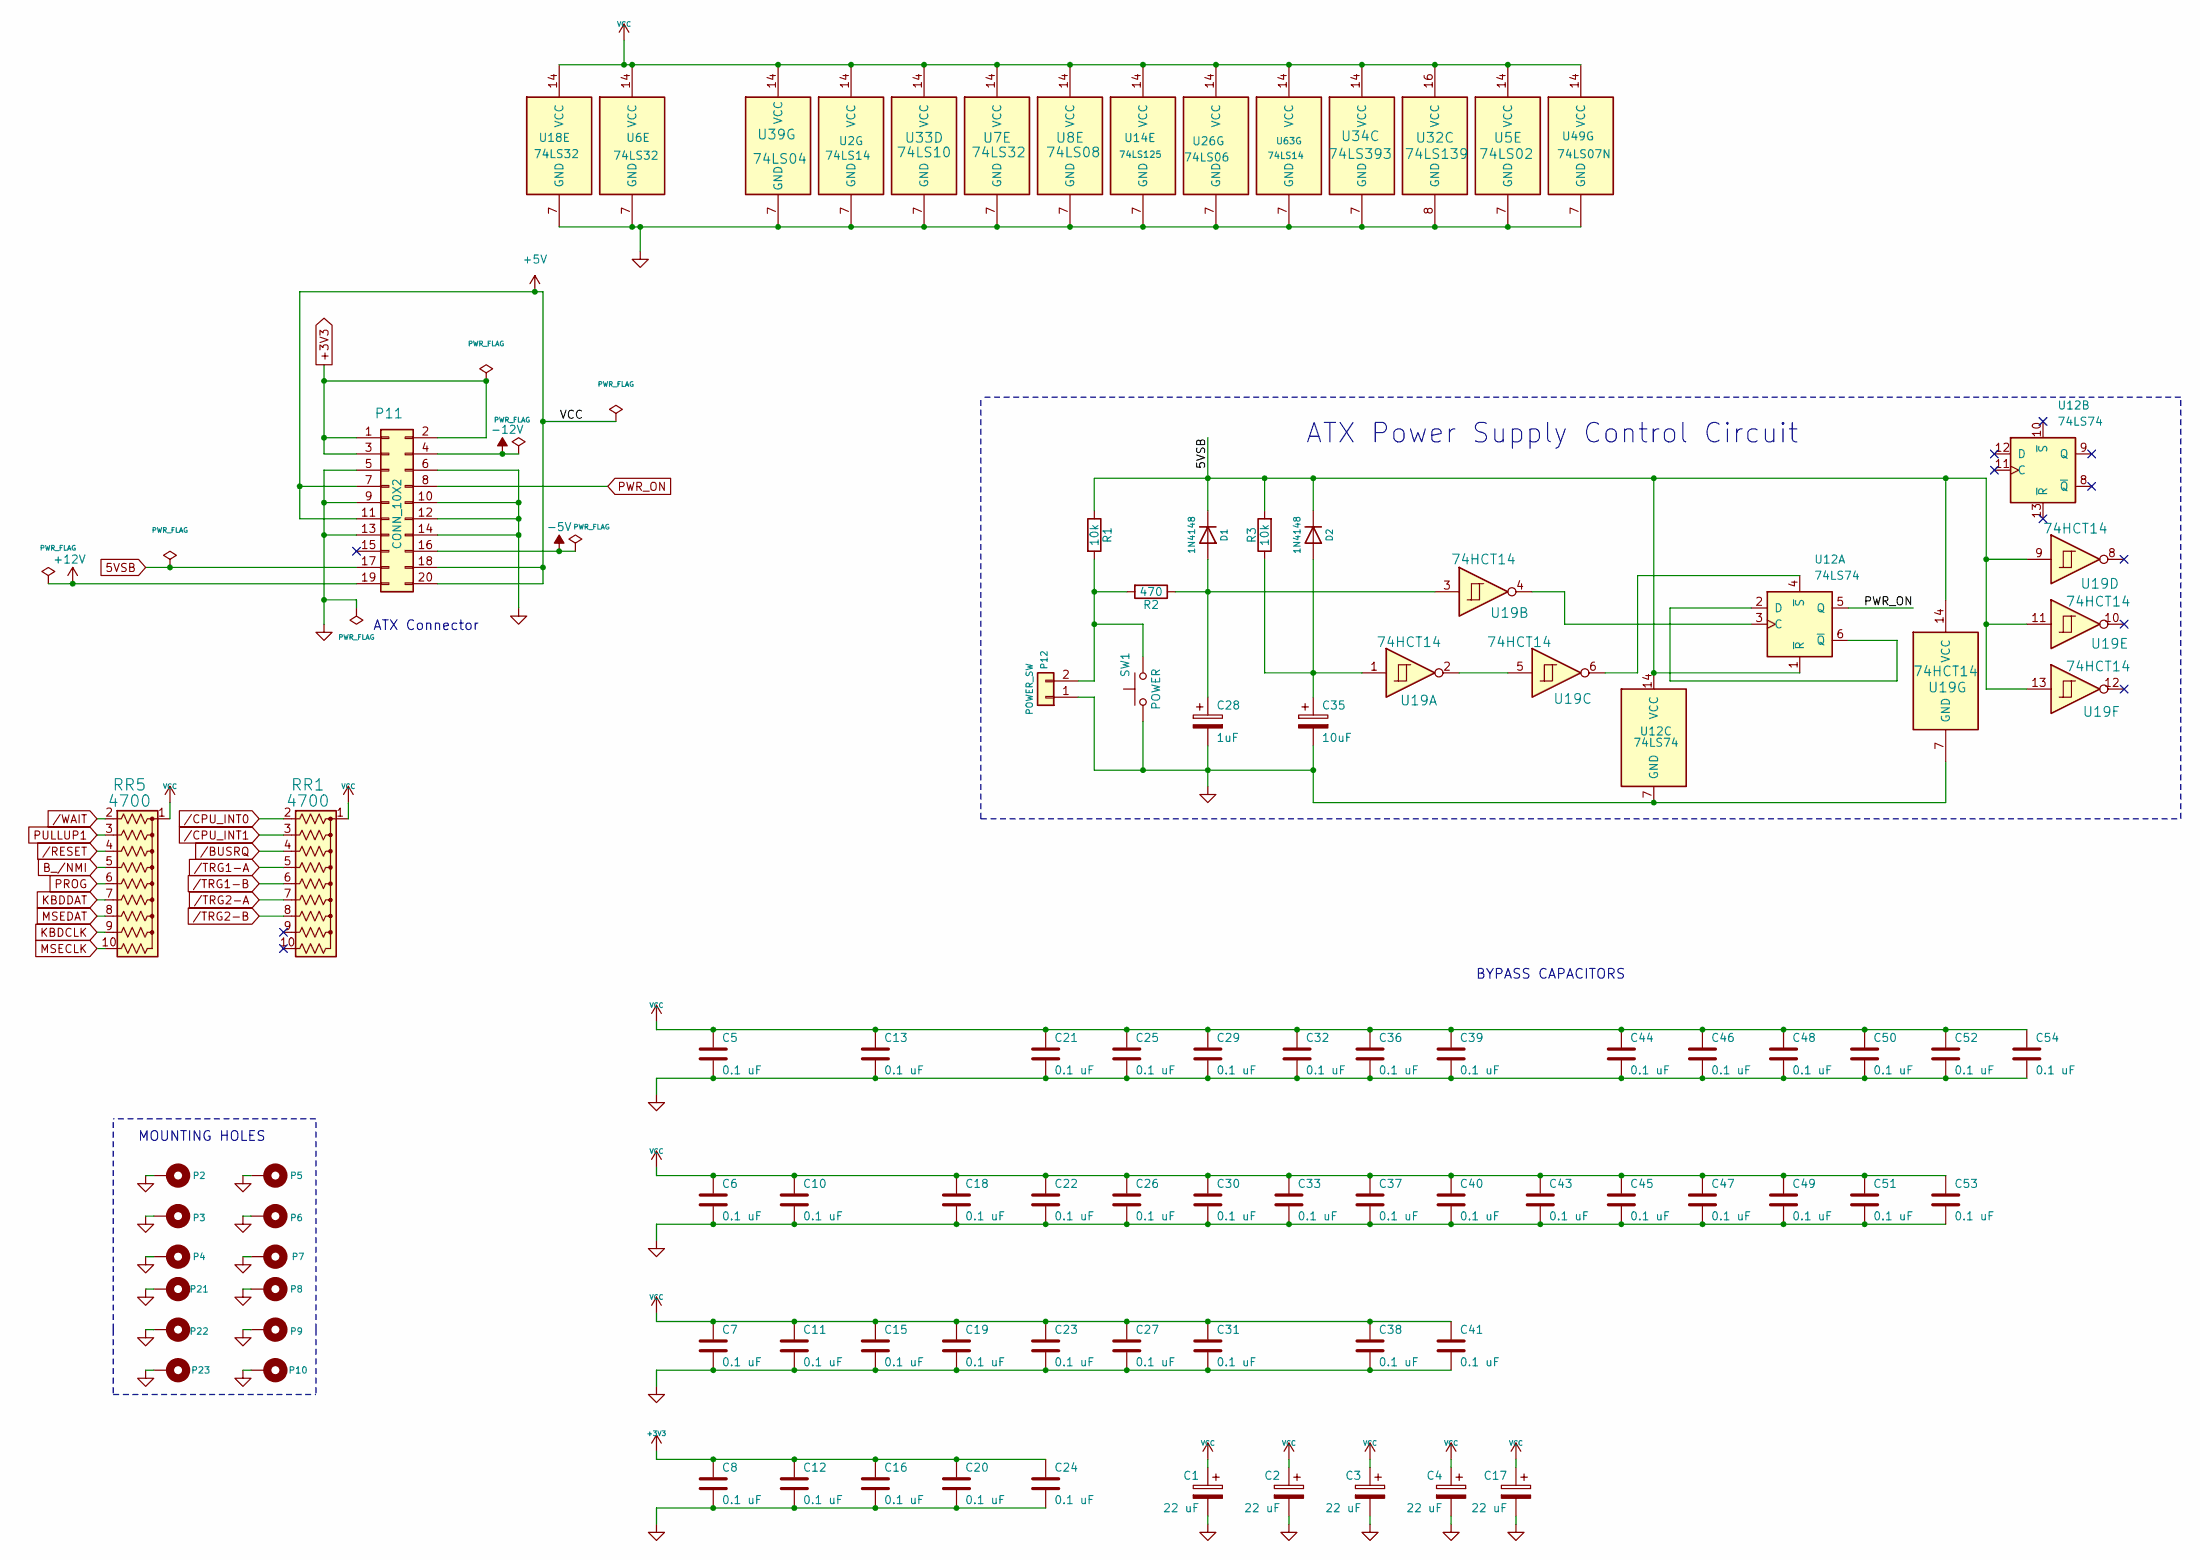
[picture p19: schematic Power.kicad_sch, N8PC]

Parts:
C1, C2, C3, C4, C17: 22 uF; STD_DDW_PCAP
C5, C6, C7, C8, C10, C11, C12, C13, C15, C16, C18, C19, C20, C21, C22, C23, C24, C25, C26, C27, C29, C30, C31, C32, C33, C36, C37, C38, C39, C40, C41, C43, C44, C45, C46, C47, C48, C49, C50, C51, C52, C53, C54: 0.1 uF; STD_DDW_CAP
C28: 1uF; STD_DDW_PCAP
C35: 10uF; STD_DDW_PCAP
D1, D2: 1N4148; STD_DDW_DIODE
P2, P3, P4, P5, P6, P7, P8, P9, P10, P21, P22, P23: CONN_1; MountingHole_3.2mm_M3_Pad_TopBottom
P11: CONN_10X2; ATXConnector
P12: POWER_SW; STD_DDW_PINHEAD_V_1x02
R1, R3: 10k; STD_DDW_RESISTOR
R2: 470; STD_DDW_RESISTOR
RR1, RR5: 4700; STD_DDW_SIP10
SW1: POWER; STD_DDW_TACTSW
U2, U63: 74LS14; STD_DDW_DIP14
U5: 74LS02; STD_DDW_DIP14
U6, U7, U18: 74LS32; STD_DDW_DIP14
U8: 74LS08; STD_DDW_DIP14
U12: 74LS74; STD_DDW_DIP14
U14: 74LS125; STD_DDW_DIP14
U19: 74HCT14; STD_DDW_DIP14
U26: 74LS06; STD_DDW_DIP14
U32: 74LS139; STD_DDW_DIP16
U33: 74LS10; STD_DDW_DIP14
U34: 74LS393; STD_DDW_DIP14
U39: 74LS04; STD_DDW_DIP14
U49: 74LS07N; STD_DDW_DIP14

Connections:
5VSB: D1.1 (K), D2.1 (K), P11.17, R1.1, R3.2, U12.1 (~R), U12.14 (VCC), U19.9, U19.11, U19.13, U19.14 (VCC)
+3V3: C8.1, C12.1, C16.1, C20.1, C24.1, P11.1, P11.2, P11.3
+5V: C1.1, C2.1, C3.1, C4.1, C5.1, C6.1, C7.1, C10.1, C11.1, C13.1, C15.1, C17.1, C18.1, C19.1, C21.1, C22.1, C23.1, C25.1, C26.1, C27.1, C29.1, C30.1, C31.1, C32.1, C33.1, C36.1, C37.1, C38.1, C39.1, C40.1, C41.1, C43.1, C44.1, C45.1, C46.1, C47.1, C48.1, C49.1, C50.1, C51.1, C52.1, C53.1, C54.1, P11.7, P11.11, P11.18, P11.20, RR1.1 (common), RR5.1 (common), U2.14 (VCC), U5.14 (VCC), U6.14 (VCC), U7.14 (VCC), U8.14 (VCC), U14.14 (VCC), U18.14 (VCC), U26.14 (VCC), U32.16 (VCC), U33.14 (VCC), U34.14 (VCC), U39.14 (VCC), U49.14 (VCC), U63.14 (VCC); also elsewhere on the board
+12V: P11.19; also elsewhere on the board
-5V: P11.16; also elsewhere on the board
-12V: P11.4; also elsewhere on the board
B_/NMI: RR5.5 (R4); also elsewhere on the board
EXT-RES: RR5.4 (R3); also elsewhere on the board
GND: C1.2, C2.2, C3.2, C4.2, C5.2, C6.2, C7.2, C8.2, C10.2, C11.2, C12.2, C13.2, C15.2, C16.2, C17.2, C18.2, C19.2, C20.2, C21.2, C22.2, C23.2, C24.2, C25.2, C26.2, C27.2, C28.2, C29.2, C30.2, C31.2, C32.2, C33.2, C35.2, C36.2, C37.2, C38.2, C39.2, C40.2, C41.2, C43.2, C44.2, C45.2, C46.2, C47.2, C48.2, C49.2, C50.2, C51.2, C52.2, C53.2, C54.2, P2.1, P3.1, P4.1, P5.1, P6.1, P7.1, P8.1, P9.1, P10.1, P11.5, P11.6, P11.9, P11.10, P11.12, P11.13, P11.14, P12.1, P21.1, P22.1, P23.1, SW1.1, U2.7 (GND), U5.7 (GND), U6.7 (GND), U7.7 (GND), U8.7 (GND), U12.7 (GND), U14.7 (GND), U18.7 (GND), U19.7 (GND), U26.7 (GND), U32.8 (GND), U33.7 (GND), U34.7 (GND), U39.7 (GND), U49.7 (GND), U63.7 (GND); also elsewhere on the board
KBDCLK: RR5.9 (R8); also elsewhere on the board
KBDDAT: RR5.7 (R6); also elsewhere on the board
MSECLK: RR5.10 (R9); also elsewhere on the board
MSEDAT: RR5.8 (R7); also elsewhere on the board
unnamed: C28.1, D1.2 (A), R2.1, U19.3
unnamed: C35.1, D2.2 (A), R3.1, U19.1
unnamed: P12.2, R1.2, R2.2, SW1.2
unnamed: U12.3 (C), U19.4
unnamed: U12.2 (D), U12.6 (~Q)
unnamed: U12.4 (~S), U19.6
unnamed: U19.2, U19.5
PROG: RR5.6 (R5); also elsewhere on the board
PULLUP1: RR5.3 (R2); also elsewhere on the board
PWR_ON: P11.8, U12.5 (Q)
/BUSRQ: RR1.4 (R3); also elsewhere on the board
/CPU_INT0: RR1.2 (R1); also elsewhere on the board
/CPU_INT1: RR1.3 (R2); also elsewhere on the board
/TRG1-A: RR1.5 (R4); also elsewhere on the board
/TRG1-B: RR1.6 (R5); also elsewhere on the board
/TRG2-A: RR1.7 (R6); also elsewhere on the board
/TRG2-B: RR1.8 (R7); also elsewhere on the board
/WAIT: RR5.2 (R1); also elsewhere on the board

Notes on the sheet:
BYPASS CAPACITORS
MOUNTING HOLES
ATX Connector
ATX Power Supply Control Circuit

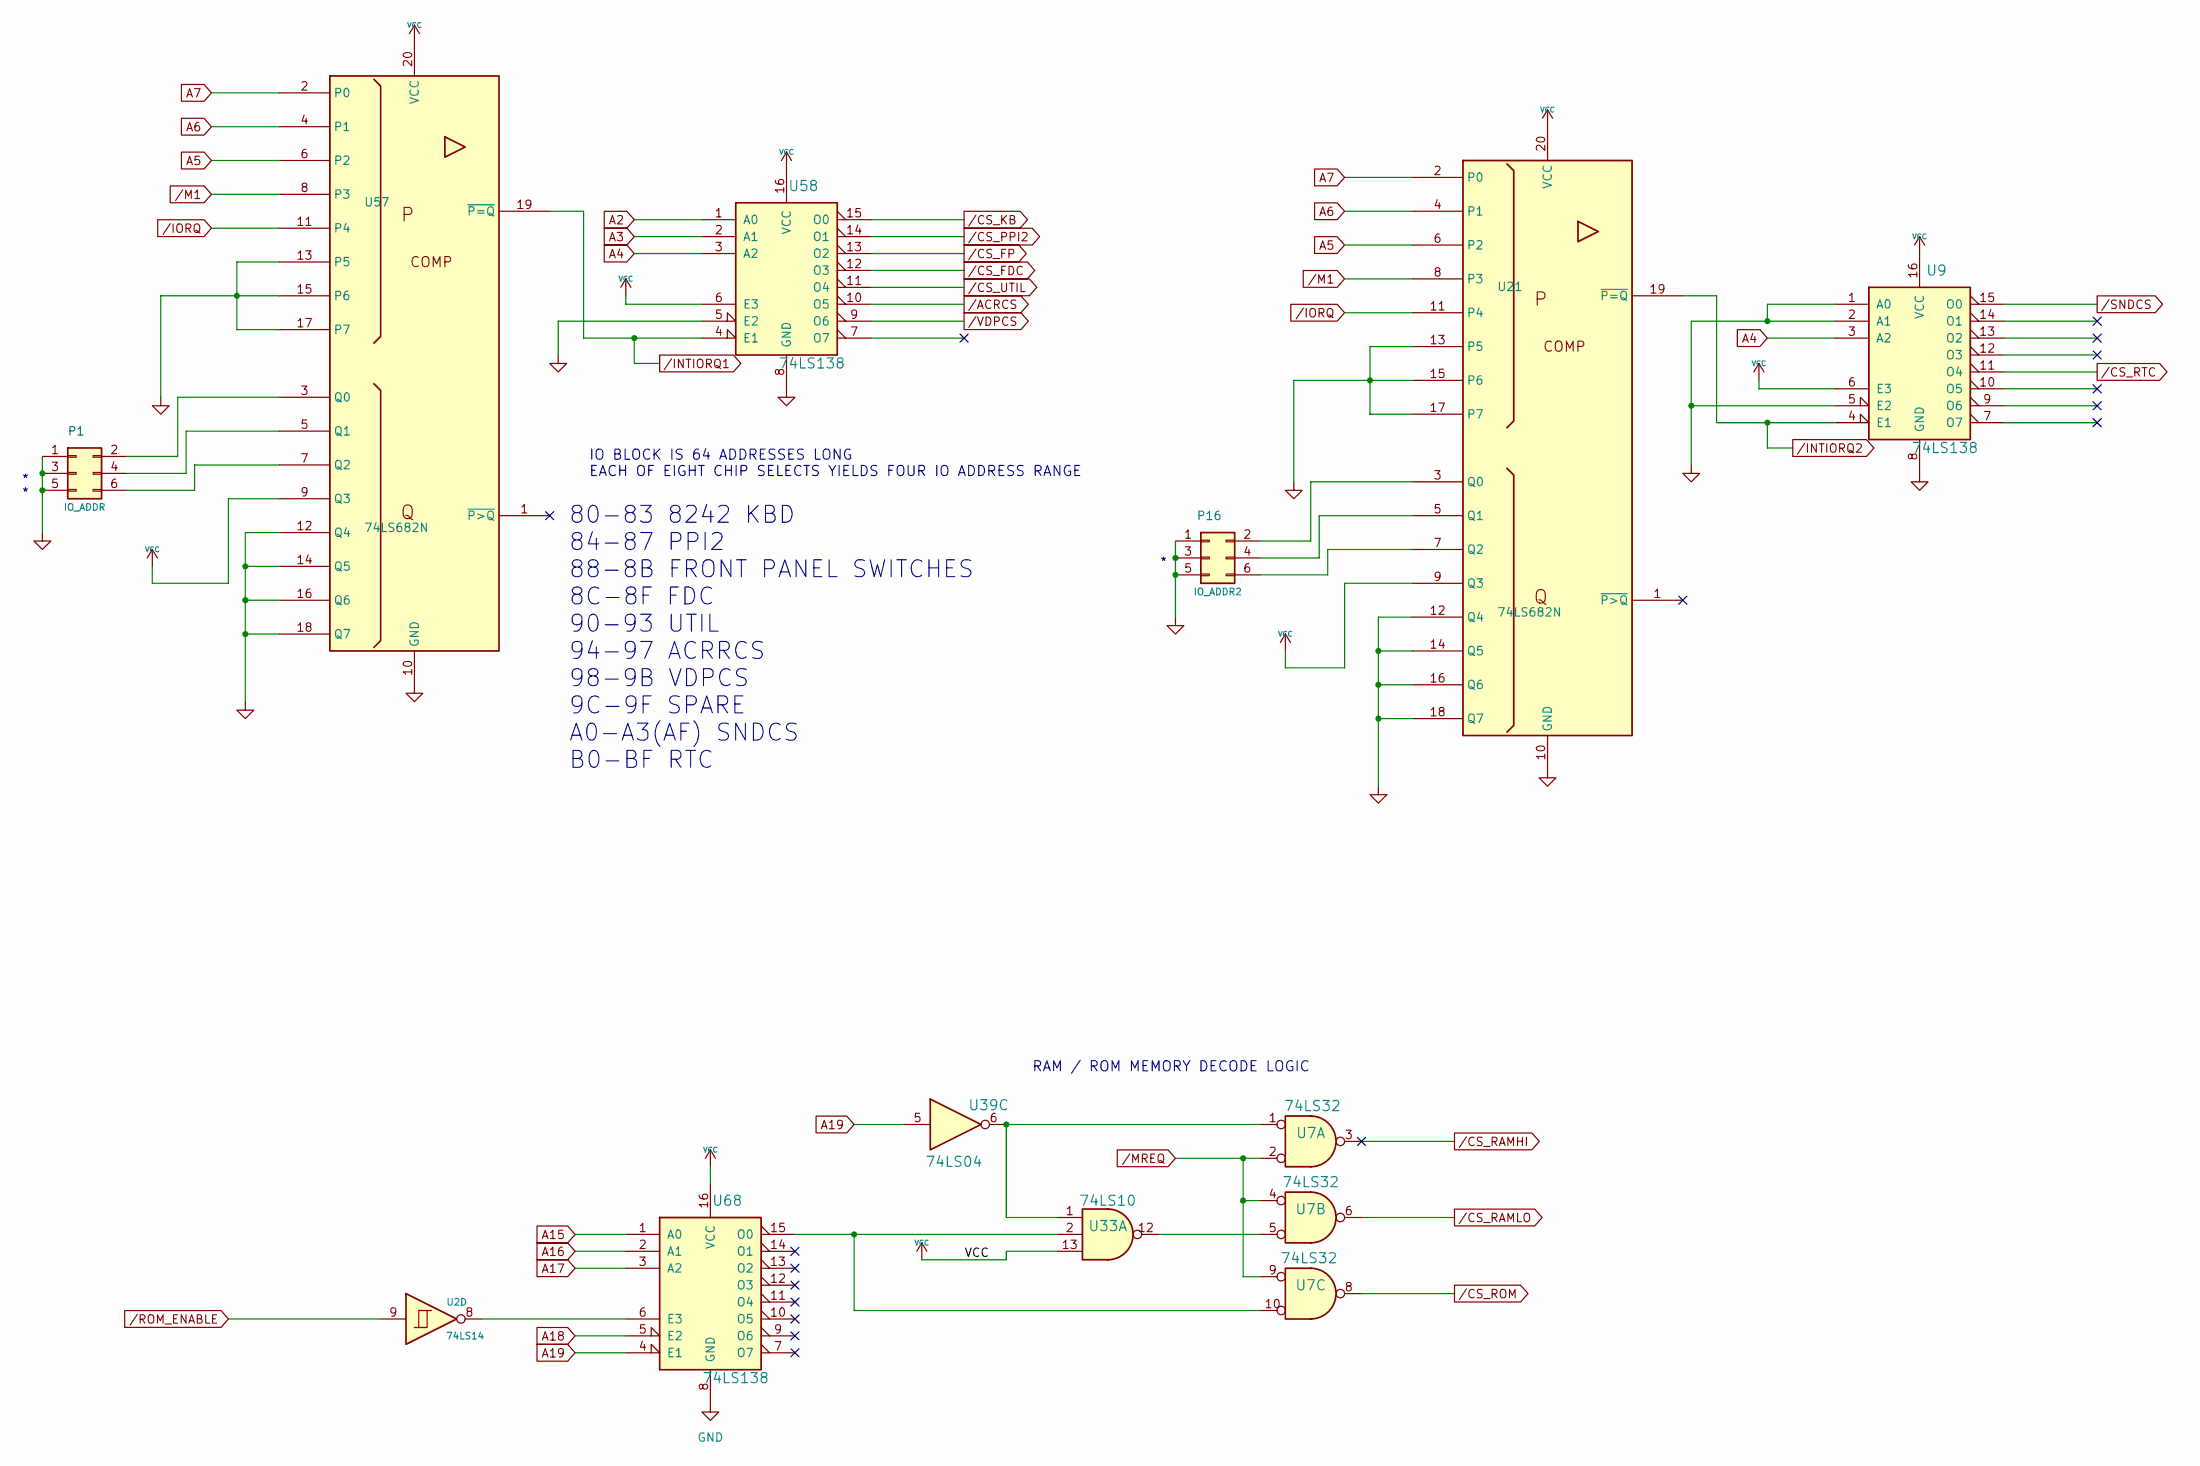
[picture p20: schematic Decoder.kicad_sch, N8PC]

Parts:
P1: IO_ADDR; STD_DDW_PinHeader_2x03
P16: IO_ADDR2; STD_DDW_PinHeader_2x03
U2: 74LS14; STD_DDW_DIP14
U7: 74LS32; STD_DDW_DIP14
U9, U58, U68: 74LS138; STD_DDW_DIP16
U21, U57: 74LS682N; STD_DDW_DIP20
U33: 74LS10; STD_DDW_DIP14
U39: 74LS04; STD_DDW_DIP14

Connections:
+5V: U9.6 (E3), U9.16 (VCC), U21.9 (Q3), U21.20 (VCC), U33.13, U57.9 (Q3), U57.20 (VCC), U58.6 (E3), U58.16 (VCC), U68.16 (VCC); also elsewhere on the board
A2: U58.1 (A0); also elsewhere on the board
A3: U58.2 (A1); also elsewhere on the board
A4: U9.3 (A2), U58.3 (A2); also elsewhere on the board
A5: U21.6 (P2), U57.6 (P2); also elsewhere on the board
A6: U21.4 (P1), U57.4 (P1); also elsewhere on the board
A7: U21.2 (P0), U57.2 (P0); also elsewhere on the board
A15: U68.1 (A0); also elsewhere on the board
A16: U68.2 (A1); also elsewhere on the board
A17: U68.3 (A2); also elsewhere on the board
A18: U68.5 (E2); also elsewhere on the board
A19: U39.5, U68.4 (E1); also elsewhere on the board
GND: P1.1, P1.3, P1.5, P16.1, P16.3, P16.5, U9.1 (A0), U9.2 (A1), U9.5 (E2), U9.8 (GND), U21.10 (GND), U21.12 (Q4), U21.13 (P5), U21.14 (Q5), U21.15 (P6), U21.16 (Q6), U21.17 (P7), U21.18 (Q7), U57.10 (GND), U57.12 (Q4), U57.13 (P5), U57.14 (Q5), U57.15 (P6), U57.16 (Q6), U57.17 (P7), U57.18 (Q7), U58.5 (E2), U58.8 (GND), U68.8 (GND); also elsewhere on the board
unnamed: P1.2, U57.3 (Q0)
unnamed: P1.4, U57.5 (Q1)
unnamed: P1.6, U57.7 (Q2)
unnamed: P16.2, U21.3 (Q0)
unnamed: P16.4, U21.5 (Q1)
unnamed: P16.6, U21.7 (Q2)
unnamed: U7.1, U33.1, U39.6
unnamed: U7.5, U33.12
unnamed: U2.8, U68.6 (E3)
unnamed: U7.10, U33.2, U68.15 (O0)
/ACRCS: U58.10 (O5); also elsewhere on the board
/CS_FDC: U58.12 (O3); also elsewhere on the board
/CS_FP: U58.13 (O2); also elsewhere on the board
/CS_KB: U58.15 (O0); also elsewhere on the board
/CS_PPI2: U58.14 (O1); also elsewhere on the board
/CS_RAMHI: U7.3
/CS_RAMLO: U7.6; also elsewhere on the board
/CS_ROM: U7.8; also elsewhere on the board
/CS_RTC: U9.11 (O4); also elsewhere on the board
/CS_UTIL: U58.11 (O4); also elsewhere on the board
/INTIORQ1: U57.19 (~P=Q), U58.4 (E1); also elsewhere on the board
/INTIORQ2: U9.4 (E1), U21.19 (~P=Q); also elsewhere on the board
/IORQ: U21.11 (P4), U57.11 (P4); also elsewhere on the board
/M1: U21.8 (P3), U57.8 (P3); also elsewhere on the board
/MREQ: U7.2, U7.4, U7.9; also elsewhere on the board
/ROM_ENABLE: U2.9; also elsewhere on the board
/SNDCS: U9.15 (O0); also elsewhere on the board
/VDPCS: U58.9 (O6); also elsewhere on the board

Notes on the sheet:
* *
RAM / ROM MEMORY DECODE LOGIC
80-83 8242 KBD 84-87 PPI2 88-8B FRONT PANEL SWITCHES 8C-8F FDC 90-93 UTIL 94-97 ACRRCS 98-9B VDPCS 9C-9F SPARE A0-A3(AF) SNDCS B0-BF RTC
IO BLOCK IS 64 ADDRESSES LONG EACH OF EIGHT CHIP SELECTS YIELDS FOUR IO ADDRESS RANGE

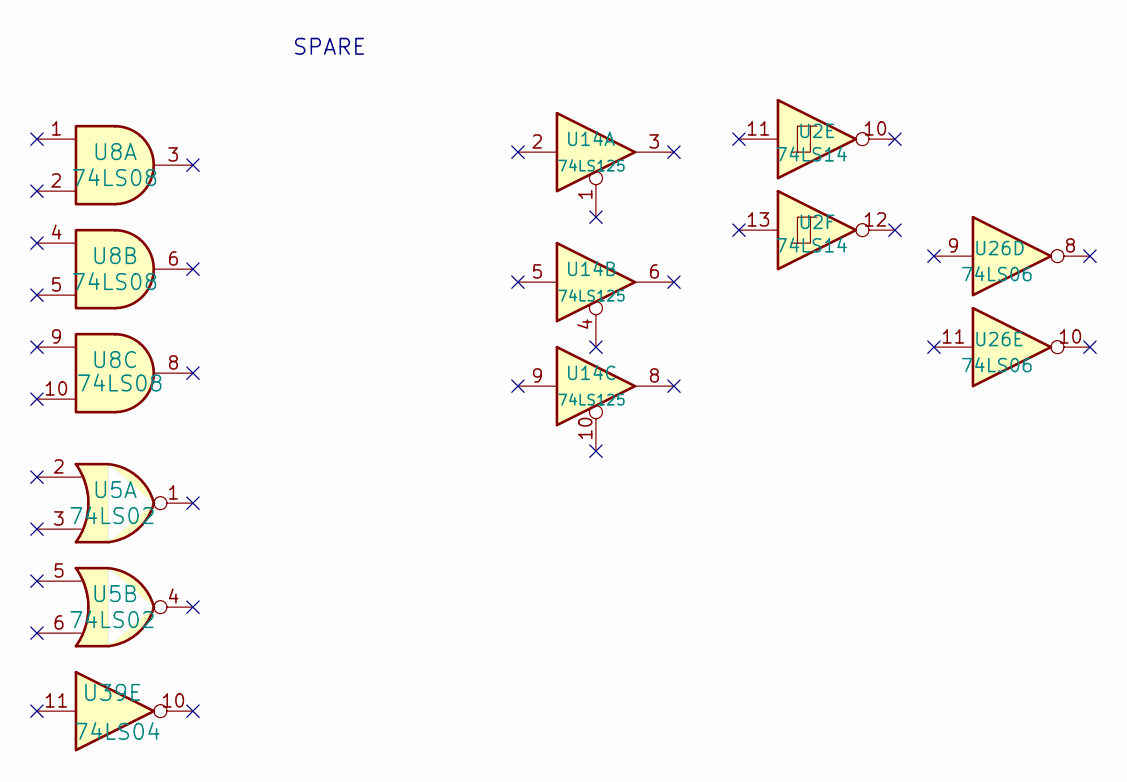
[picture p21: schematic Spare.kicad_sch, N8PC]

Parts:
U2: 74LS14; STD_DDW_DIP14
U5: 74LS02; STD_DDW_DIP14
U8: 74LS08; STD_DDW_DIP14
U14: 74LS125; STD_DDW_DIP14
U26: 74LS06; STD_DDW_DIP14
U39: 74LS04; STD_DDW_DIP14

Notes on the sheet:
SPARE

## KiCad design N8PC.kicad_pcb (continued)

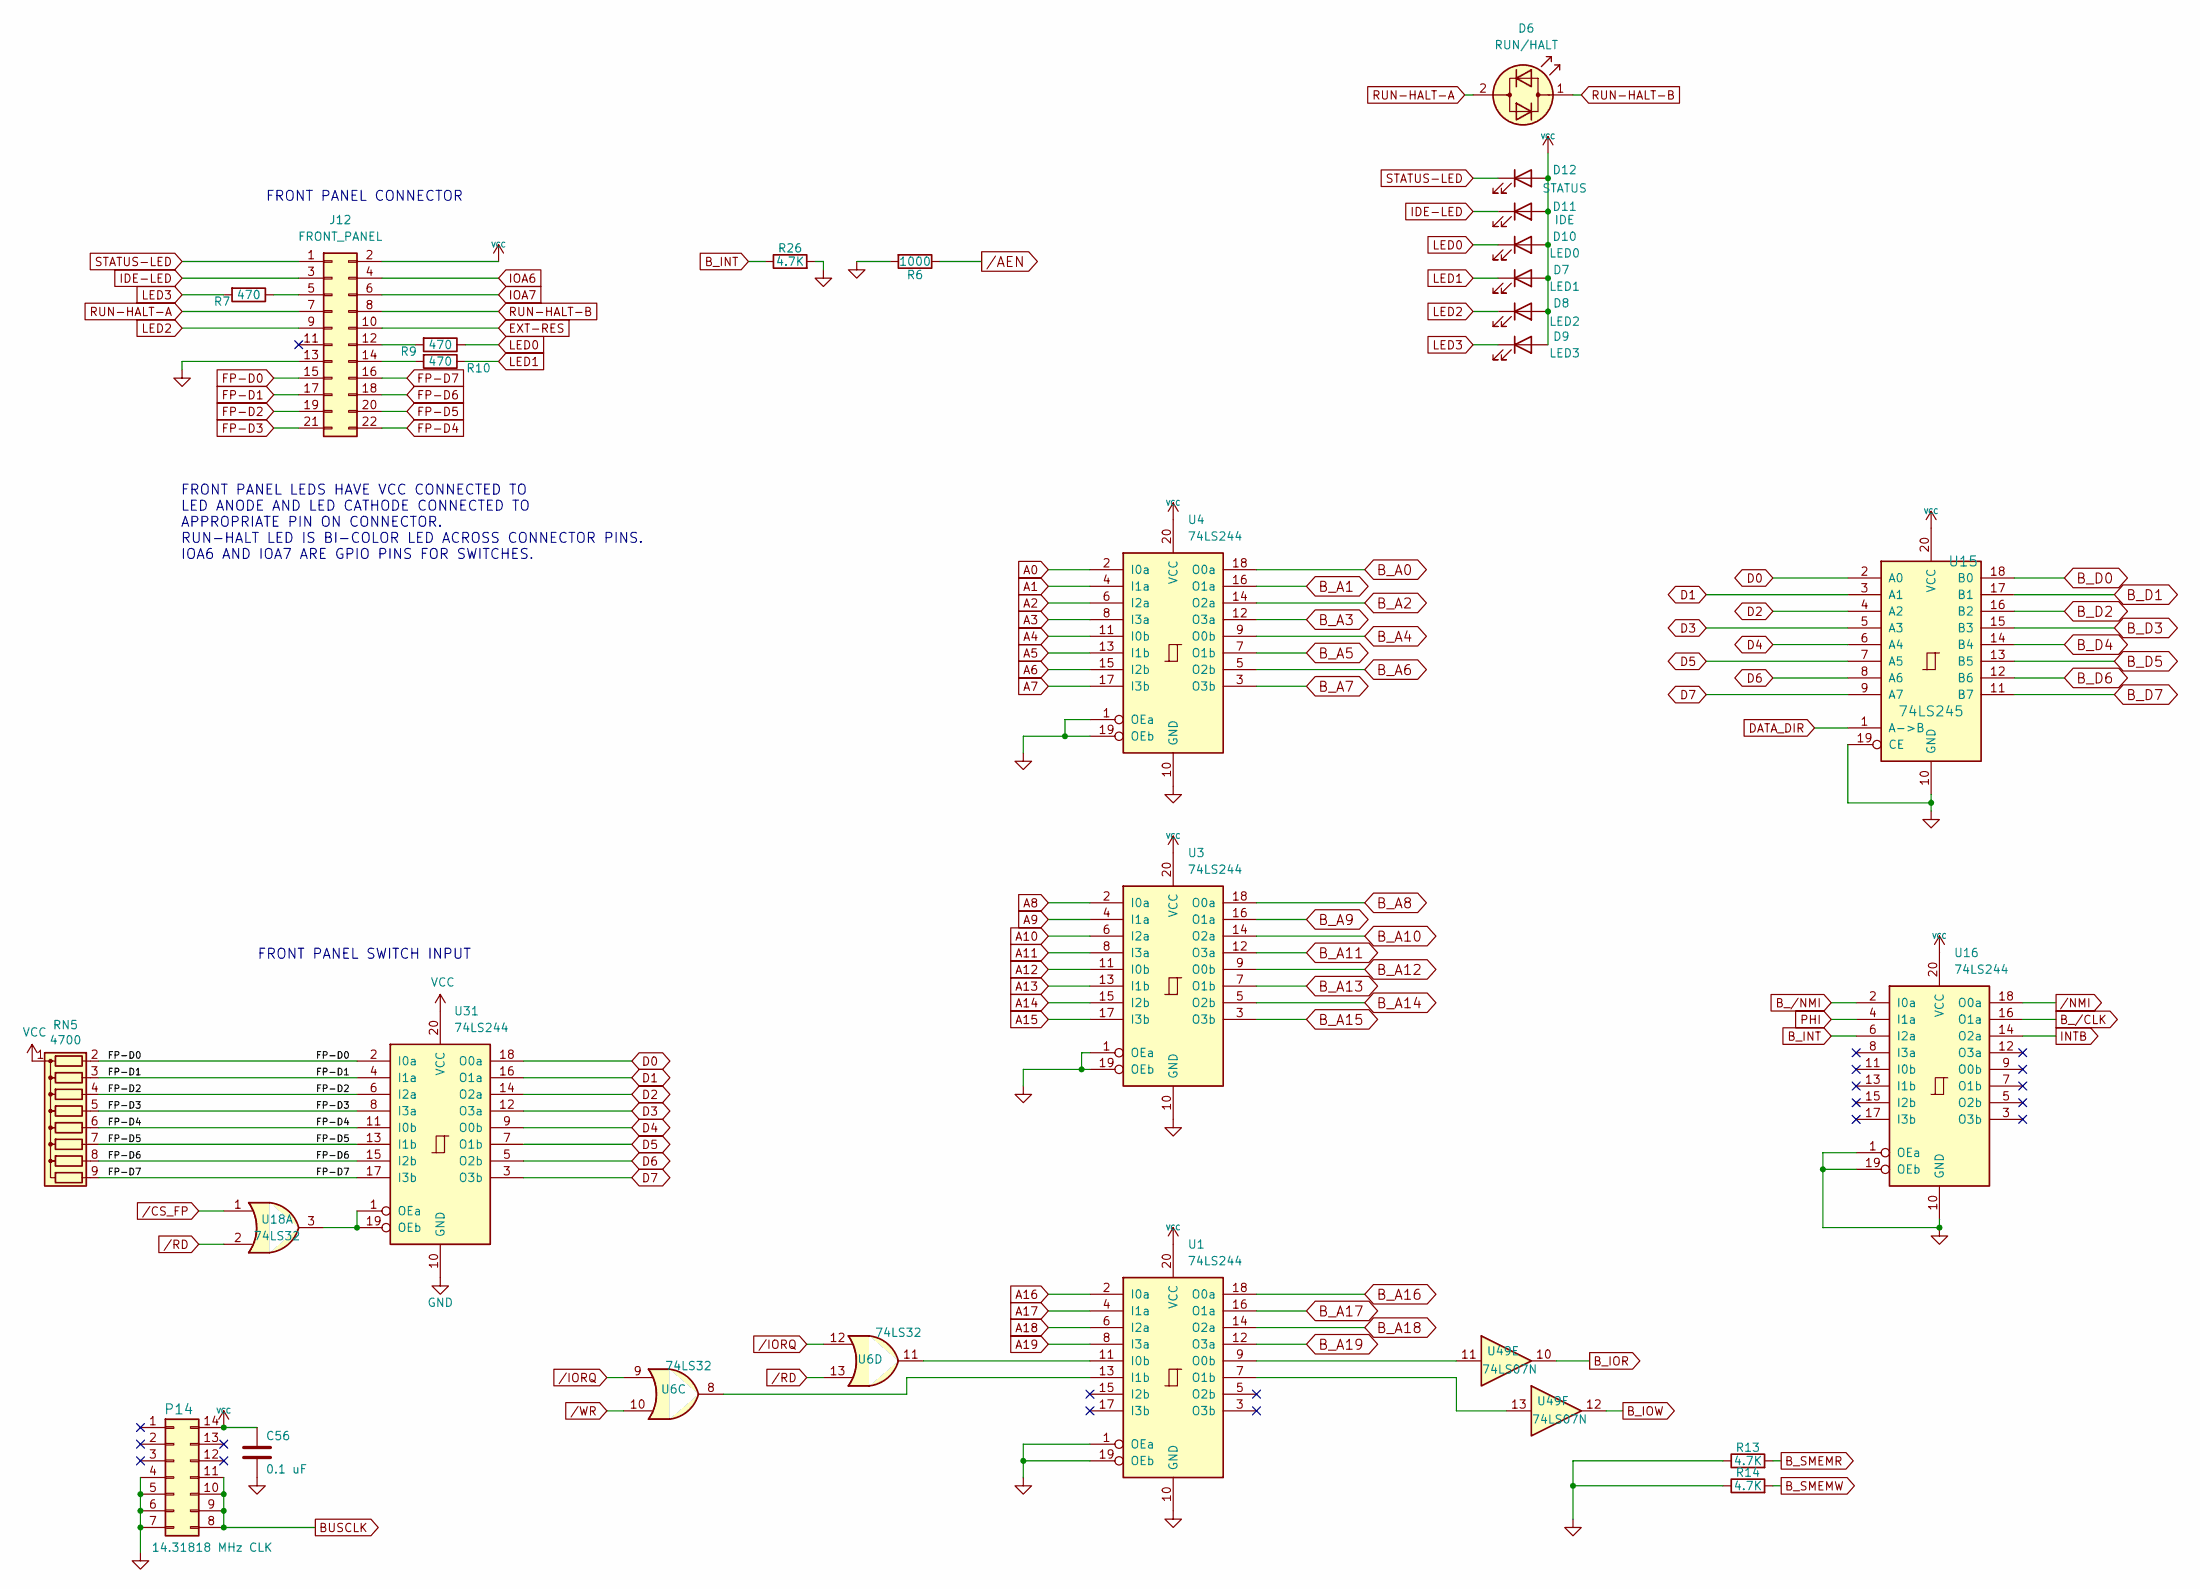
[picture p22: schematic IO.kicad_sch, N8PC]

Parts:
C56: 0.1 uF; STD_DDW_CAP
D6: RUN/HALT; STD_DDW_LED5
D7: LED1; STD_DDW_LED5
D8: LED2; STD_DDW_LED5
D9: LED3; STD_DDW_LED5
D10: LED0; STD_DDW_LED5
D11: IDE; STD_DDW_LED5
D12: STATUS; STD_DDW_LED5
J12: FRONT_PANEL; STD_DDW_PinHeader_2x11
P14: 14.31818 MHz CLK; STD_DDW_DIP14
R6: 1000; STD_DDW_RESISTOR
R7, R9, R10: 470; STD_DDW_RESISTOR
R13, R14, R26: 4.7K; STD_DDW_RESISTOR
RN5: 4700; R_Array_SIP9
U1, U3, U4, U16, U31: 74LS244; STD_DDW_DIP20
U6, U18: 74LS32; STD_DDW_DIP14
U15: 74LS245; STD_DDW_DIP20
U49: 74LS07N; STD_DDW_DIP14

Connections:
+5V: C56.1, D7.2 (A), D8.2 (A), D9.2 (A), D10.2 (A), D11.2 (A), D12.2 (A), J12.2, P14.14, RN5.1 (common), U1.20 (VCC), U3.20 (VCC), U4.20 (VCC), U15.20 (VCC), U16.20 (VCC), U31.20 (VCC); also elsewhere on the board
A0: U4.2 (I0a); also elsewhere on the board
A1: U4.4 (I1a); also elsewhere on the board
A2: U4.6 (I2a); also elsewhere on the board
A3: U4.8 (I3a); also elsewhere on the board
A4: U4.11 (I0b); also elsewhere on the board
A5: U4.13 (I1b); also elsewhere on the board
A6: U4.15 (I2b); also elsewhere on the board
A7: U4.17 (I3b); also elsewhere on the board
A8: U3.2 (I0a); also elsewhere on the board
A9: U3.4 (I1a); also elsewhere on the board
A10: U3.6 (I2a); also elsewhere on the board
A11: U3.8 (I3a); also elsewhere on the board
A12: U3.11 (I0b); also elsewhere on the board
A13: U3.13 (I1b); also elsewhere on the board
A14: U3.15 (I2b); also elsewhere on the board
A15: U3.17 (I3b); also elsewhere on the board
A16: U1.2 (I0a); also elsewhere on the board
A17: U1.4 (I1a); also elsewhere on the board
A18: U1.6 (I2a); also elsewhere on the board
A19: U1.8 (I3a); also elsewhere on the board
BUSCLK: P14.8, P14.9, P14.10, P14.11; also elsewhere on the board
B_A0: U4.18 (O0a); also elsewhere on the board
B_A1: U4.16 (O1a); also elsewhere on the board
B_A2: U4.14 (O2a); also elsewhere on the board
B_A3: U4.12 (O3a); also elsewhere on the board
B_A4: U4.9 (O0b); also elsewhere on the board
B_A5: U4.7 (O1b); also elsewhere on the board
B_A6: U4.5 (O2b); also elsewhere on the board
B_A7: U4.3 (O3b); also elsewhere on the board
B_A8: U3.18 (O0a); also elsewhere on the board
B_A9: U3.16 (O1a); also elsewhere on the board
B_A10: U3.14 (O2a); also elsewhere on the board
B_A11: U3.12 (O3a); also elsewhere on the board
B_A12: U3.9 (O0b); also elsewhere on the board
B_A13: U3.7 (O1b); also elsewhere on the board
B_A14: U3.5 (O2b); also elsewhere on the board
B_A15: U3.3 (O3b); also elsewhere on the board
B_A16: U1.18 (O0a); also elsewhere on the board
B_A17: U1.16 (O1a); also elsewhere on the board
B_A18: U1.14 (O2a); also elsewhere on the board
B_A19: U1.12 (O3a); also elsewhere on the board
B_D0: U15.18 (B0); also elsewhere on the board
B_D1: U15.17 (B1); also elsewhere on the board
B_D2: U15.16 (B2); also elsewhere on the board
B_D3: U15.15 (B3); also elsewhere on the board
B_D4: U15.14 (B4); also elsewhere on the board
B_D5: U15.13 (B5); also elsewhere on the board
B_D6: U15.12 (B6); also elsewhere on the board
B_D7: U15.11 (B7); also elsewhere on the board
B_INT: R26.1, U16.6 (I2a); also elsewhere on the board
B_IOR: U49.10; also elsewhere on the board
B_IOW: U49.12; also elsewhere on the board
B_SMEMR: R13.2; also elsewhere on the board
B_SMEMW: R14.2; also elsewhere on the board
B_/CLK: U16.16 (O1a); also elsewhere on the board
B_/NMI: U16.2 (I0a); also elsewhere on the board
D0: U15.2 (A0), U31.18 (O0a); also elsewhere on the board
D1: U15.3 (A1), U31.16 (O1a); also elsewhere on the board
D2: U15.4 (A2), U31.14 (O2a); also elsewhere on the board
D3: U15.5 (A3), U31.12 (O3a); also elsewhere on the board
D4: U15.6 (A4), U31.9 (O0b); also elsewhere on the board
D5: U15.7 (A5), U31.7 (O1b); also elsewhere on the board
D6: U15.8 (A6), U31.5 (O2b); also elsewhere on the board
D7: U15.9 (A7), U31.3 (O3b); also elsewhere on the board
DATA_DIR: U15.1 (A->B); also elsewhere on the board
EXT-RES: J12.10; also elsewhere on the board
FP-D0: J12.15, RN5.2 (R1), U31.2 (I0a)
FP-D1: J12.17, RN5.3 (R2), U31.4 (I1a)
FP-D2: J12.19, RN5.4 (R3), U31.6 (I2a)
FP-D3: J12.21, RN5.5 (R4), U31.8 (I3a)
FP-D4: J12.22, RN5.6 (R5), U31.11 (I0b)
FP-D5: J12.20, RN5.7 (R6), U31.13 (I1b)
FP-D6: J12.18, RN5.8 (R7), U31.15 (I2b)
FP-D7: J12.16, RN5.9 (R8), U31.17 (I3b)
GND: C56.2, J12.13, P14.4, P14.5, P14.6, P14.7, R6.2, R13.1, R14.1, R26.2, U1.1 (OEa), U1.10 (GND), U1.19 (OEb), U3.1 (OEa), U3.10 (GND), U3.19 (OEb), U4.1 (OEa), U4.10 (GND), U4.19 (OEb), U15.10 (GND), U15.19 (CE), U16.1 (OEa), U16.10 (GND), U16.19 (OEb), U31.10 (GND); also elsewhere on the board
IDE-LED: D11.1 (K), J12.3; also elsewhere on the board
INTB: U16.14 (O2a); also elsewhere on the board
IOA6: J12.4; also elsewhere on the board
IOA7: J12.6; also elsewhere on the board
LED0: D10.1 (K), R9.1; also elsewhere on the board
LED1: D7.1 (K), R10.1; also elsewhere on the board
LED2: D8.1 (K), J12.9; also elsewhere on the board
LED3: D9.1 (K), R7.2; also elsewhere on the board
unnamed: J12.5, R7.1
unnamed: J12.12, R9.2
unnamed: J12.14, R10.2
unnamed: U1.11 (I0b), U6.11
unnamed: U1.13 (I1b), U6.8
unnamed: U1.9 (O0b), U49.11
unnamed: U1.7 (O1b), U49.13
unnamed: U18.3, U31.1 (OEa), U31.19 (OEb)
PHI: U16.4 (I1a); also elsewhere on the board
RUN-HALT-A: D6.2 (AK), J12.7; also elsewhere on the board
RUN-HALT-B: D6.1 (KA), J12.8; also elsewhere on the board
STATUS-LED: D12.1 (K), J12.1; also elsewhere on the board
/AEN: R6.1; also elsewhere on the board
/CS_FP: U18.1; also elsewhere on the board
/IORQ: U6.9, U6.12; also elsewhere on the board
/NMI: U16.18 (O0a); also elsewhere on the board
/RD: U6.13, U18.2; also elsewhere on the board
/WR: U6.10; also elsewhere on the board

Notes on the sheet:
FRONT PANEL CONNECTOR
FRONT PANEL LEDS HAVE VCC CONNECTED TO LED ANODE AND LED CATHODE CONNECTED TO APPROPRIATE PIN ON CONNECTOR. RUN-HALT LED IS BI-COLOR LED ACROSS CONNECTOR PINS. IOA6 AND IOA7 ARE GPIO PINS FOR SWITCHES.
FRONT PANEL SWITCH INPUT

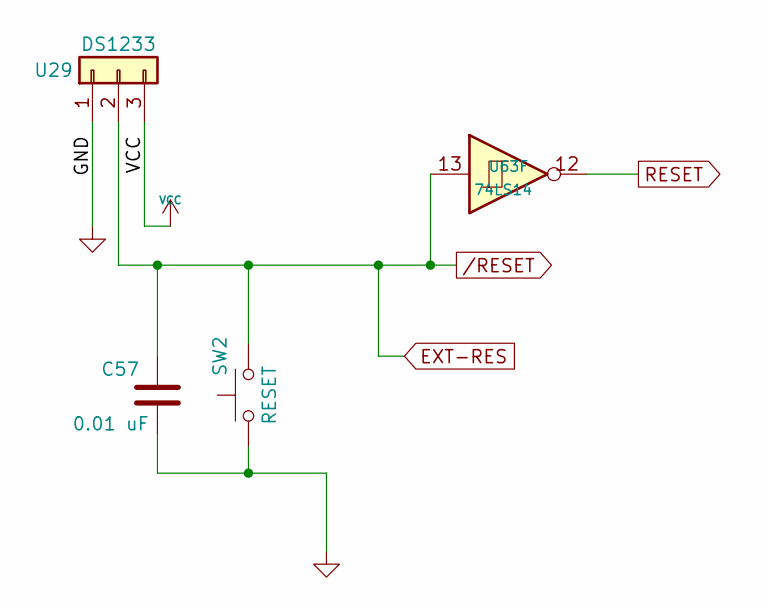
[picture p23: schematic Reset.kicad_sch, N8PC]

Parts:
C57: 0.01 uF; STD_DDW_CAP
SW2: RESET; STD_DDW_TACTSW
U29: DS1233; STD_DDW_TO92
U63: 74LS14; STD_DDW_DIP14

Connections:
+5V: U29.3; also elsewhere on the board
EXT-RES: C57.1, SW2.2, U29.2, U63.13; also elsewhere on the board
GND: C57.2, SW2.1, U29.1; also elsewhere on the board
RESET: U63.12; also elsewhere on the board

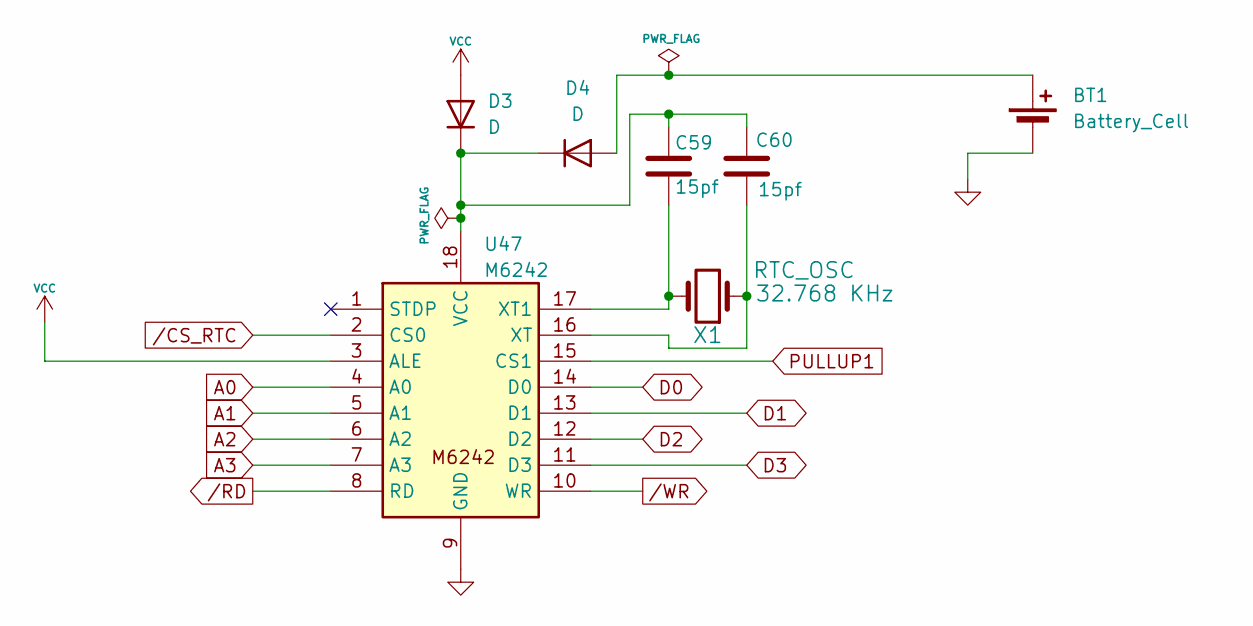
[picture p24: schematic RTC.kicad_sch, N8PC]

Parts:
BT1: Battery_Cell; BatteryHolder_MYOUNG_BS-07-A1BJ001_CR2032
C59, C60: 15pf; STD_DDW_CAP
D3, D4: D; STD_DDW_DIODE
U47: M6242; STD_DDW_DIP18
X1: RTC_OSC; DDW_STD_RTCCRYSTAL

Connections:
+5V: D3.2 (A), U47.3 (ALE); also elsewhere on the board
A0: U47.4 (A0); also elsewhere on the board
A1: U47.5 (A1); also elsewhere on the board
A2: U47.6 (A2); also elsewhere on the board
A3: U47.7 (A3); also elsewhere on the board
D0: U47.14 (D0); also elsewhere on the board
D1: U47.13 (D1); also elsewhere on the board
D2: U47.12 (D2); also elsewhere on the board
D3: U47.11 (D3); also elsewhere on the board
GND: BT1.2 (-), U47.9 (GND); also elsewhere on the board
unnamed: BT1.1 (+), D4.2 (A)
unnamed: C59.1, C60.1, D3.1 (K), D4.1 (K), U47.18 (VCC)
unnamed: C59.2, U47.17 (XT1), X1.2
unnamed: C60.2, U47.16 (XT), X1.1
PULLUP1: U47.15 (CS1); also elsewhere on the board
/CS_RTC: U47.2 (CS0); also elsewhere on the board
/RD: U47.8 (RD); also elsewhere on the board
/WR: U47.10 (WR); also elsewhere on the board

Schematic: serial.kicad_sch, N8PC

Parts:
C55, C58, C61, C62, C63, C64, C67, C71, C72, C73: 1.0 uF; STD_DDW_PCAP
J17, J19: TTL SERIAL CONSOLE; STD_DDW_PINHEAD_V_1x06
J18, J20: TTL CONSOLE PWR; STD_DDW_PINHEAD_V_1x02
JP2: CTS0; STD_DDW_PINHEAD_V_1x02
JP3: CTS1; STD_DDW_PINHEAD_V_1x02
P13, P18: SERIAL; STD_DDW_PINHEAD_V_2x05
R4: 4.7K; STD_DDW_RESISTOR
U10, U35: MAX232; STD_DDW_DIP16

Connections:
+5V: C61.1, C63.2, C71.2, C72.1, J18.1, J20.1, R4.1, U10.16 (VCC), U35.16 (VCC); also elsewhere on the board
CTS0: JP2.2 (B), P18.6, U35.13 (R1IN)
CTS1: JP3.2 (B), P13.6, U10.13 (R1IN)
CTS_TTL0: J17.6, U35.12 (R1OUT); also elsewhere on the board
CTS_TTL1: J19.6, U10.12 (R1OUT); also elsewhere on the board
GND: C61.2, C64.1, C72.2, C73.1, J17.1, J19.1, P13.9, P18.9, U10.15 (GND), U35.15 (GND); also elsewhere on the board
unnamed: J17.3, J18.2
unnamed: J19.3, J20.2
unnamed: JP2.1 (A), JP3.1 (A), R4.2
unnamed: C58.1, U10.1 (C1+)
unnamed: C58.2, U10.3 (C1-)
unnamed: C62.1, U10.4 (C2+)
unnamed: C62.2, U10.5 (C2-)
unnamed: C63.1, U10.2 (VS+)
unnamed: C64.2, U10.6 (VS-)
unnamed: C55.1, U35.1 (C1+)
unnamed: C55.2, U35.3 (C1-)
unnamed: C67.1, U35.4 (C2+)
unnamed: C67.2, U35.5 (C2-)
unnamed: C71.1, U35.2 (VS+)
unnamed: C73.2, U35.6 (VS-)
RTS0: P18.4, U35.14 (T1OUT)
RTS1: P13.4, U10.14 (T1OUT)
RTS_TTL0: J17.2, U35.11 (T1IN); also elsewhere on the board
RTS_TTL1: J19.2, U10.11 (T1IN); also elsewhere on the board
RX0: P18.3, U35.8 (R2IN)
RX1: P13.3, U10.8 (R2IN)
SIN_TTL0: J17.4, U35.9 (R2OUT); also elsewhere on the board
SIN_TTL1: J19.4, U10.9 (R2OUT); also elsewhere on the board
SOUT_TTL0: J17.5, U35.10 (T2IN); also elsewhere on the board
SOUT_TTL1: J19.5, U10.10 (T2IN); also elsewhere on the board
TX0: P18.5, U35.7 (T2OUT)
TX1: P13.5, U10.7 (T2OUT)

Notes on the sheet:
CTS is an inverted signal on the RS-232 port. So it is really /CTS. To assert the signal, it must be tied to SPACE, which is a + RS-232 voltage. (MARK, or true, is a - RS-232 voltage.)

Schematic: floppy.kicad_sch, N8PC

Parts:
P27: FLOPPY; STD_DDW_PinHeader_2x17
P41: OSC_FDC; STD_DDW_DIP14
R46, R47: 4700; STD_DDW_RESISTOR
RP1: 150; STD_DDW_SIP9
U6: 74LS32; STD_DDW_DIP14
U8: 74LS08; STD_DDW_DIP14
U32: 74LS139; STD_DDW_DIP16
U33: 74LS10; STD_DDW_DIP14
U39: 74LS04; STD_DDW_DIP14
U61: WD37C65BJM; STD_DDW_PLCC-44

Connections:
+5V: P41.14, RP1.1 (common), U61.44 (VCC); also elsewhere on the board
A0: U32.2 (A0), U61.4 (A0); also elsewhere on the board
A1: U6.5, U32.3 (A1), U39.1; also elsewhere on the board
D0: U61.7 (DB0); also elsewhere on the board
D1: U61.8 (DB1); also elsewhere on the board
D2: U61.9 (DB2); also elsewhere on the board
D3: U61.10 (DB3); also elsewhere on the board
D4: U61.11 (DB4); also elsewhere on the board
D5: U61.12 (DB5); also elsewhere on the board
D6: U61.13 (DB6); also elsewhere on the board
D7: U61.14 (DB7); also elsewhere on the board
GND: P27.1, P27.3, P27.5, P27.7, P27.9, P27.11, P27.13, P27.15, P27.17, P27.19, P27.21, P27.23, P27.25, P27.27, P27.29, P27.31, P27.33, P41.4, P41.5, P41.6, P41.7, R46.1, R47.1, U61.17 (/DCHGEN), U61.23 (XT2), U61.24 (DRV), U61.34 (GND); also elsewhere on the board
unnamed: P27.2, U61.39 (/RWC/RPM)
unnamed: P27.8, RP1.7 (R6), U61.43 (/IDX)
unnamed: P27.10, U61.37 (/MO2/DS4)
unnamed: P27.12, U61.33 (/DS1)
unnamed: P27.14, U61.35 (/DS2)
unnamed: P27.6, P27.16, U61.36 (/MO1/DS3)
unnamed: P27.18, U61.31 (/DIRC)
unnamed: P27.20, U61.32 (/STEP)
unnamed: P27.22, U61.30 (/WD)
unnamed: P27.24, U61.29 (/WE)
unnamed: P27.26, RP1.6 (R5), U61.42 (/TR00)
unnamed: P27.28, RP1.5 (R4), U61.41 (/WP)
unnamed: P27.30, RP1.3 (R2), U61.21 (/RDD)
unnamed: P27.32, U61.28 (/HS)
unnamed: P27.34, RP1.4 (R3), U61.40 (/DCHG)
unnamed: RP1.8 (R7), U61.27 (PCVAL)
unnamed: U32.5 (O1), U61.19 (/LDCR)
unnamed: U32.6 (O2), U61.18 (/LDOR)
unnamed: U6.2, U39.2
unnamed: R47.2, U39.9, U61.15 (DMA)
unnamed: R46.2, U39.13, U61.16 (IRQ)
unnamed: U33.8, U61.6 (TC)
unnamed: P41.8, P41.9, P41.10, P41.11, U61.26 (XT1)
unnamed: U6.6, U61.3 (/CS)
unnamed: U8.11, U61.5 (/DACK)
RESET: U61.20 (RST); also elsewhere on the board
/CS_FDC: U6.1, U6.4; also elsewhere on the board
/CS_UTIL: U32.1 (E); also elsewhere on the board
/DACK1: U8.12, U32.4 (O0)
/DACK_AND_TC: U8.13, U32.7 (O3), U33.10
/DREQ1: U39.8; also elsewhere on the board
/INT_FDC: U39.12; also elsewhere on the board
/RD: U61.1 (/RD); also elsewhere on the board
/TC: U6.3, U33.9
/TEND1: U33.11; also elsewhere on the board
/WR: U61.2 (/WR); also elsewhere on the board

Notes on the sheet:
IBM floppy connector A: = DS1 (no twist) B: = DS2 (twist)
CS_FDC IS IO BASE + 12 CS_UTIL IS IO BASE + 16 0 IS /DACK 1 IS /LDCR 2 IS /LDOR 3 IS /DACK AND TC
key

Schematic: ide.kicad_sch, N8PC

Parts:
K2: IDE_PWR; STD_DDW_PINHEAD_V_1x03
P29: PPIDE; STD_DDW_PINHEAD_V_2x20
P31: PARALLEL EXP; STD_DDW_PINHEAD_V_2x13
R36: 470; STD_DDW_RESISTOR
U38: 8255; STD_DDW_DIP40
U63: 74LS14; STD_DDW_DIP14

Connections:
+5V: K2.3, U38.26 (VCC); also elsewhere on the board
A0: U38.9 (A0); also elsewhere on the board
A1: U38.8 (A1); also elsewhere on the board
D0: U38.34 (D0); also elsewhere on the board
D1: U38.33 (D1); also elsewhere on the board
D2: U38.32 (D2); also elsewhere on the board
D3: U38.31 (D3); also elsewhere on the board
D4: U38.30 (D4); also elsewhere on the board
D5: U38.29 (D5); also elsewhere on the board
D6: U38.28 (D6); also elsewhere on the board
D7: U38.27 (D7); also elsewhere on the board
GND: K2.1, P29.2, P29.19, P29.22, P29.24, P29.26, P29.30, P29.40, P31.26, U38.7 (GND); also elsewhere on the board
IDE-LED: R36.2; also elsewhere on the board
unnamed: K2.2, P29.20, P31.25
unnamed: P29.39, R36.1
PA0: P29.17, P31.2, U38.4 (PA0)
PA1: P29.15, P31.4, U38.3 (PA1)
PA2: P29.13, P31.6, U38.2 (PA2)
PA3: P29.11, P31.8, U38.1 (PA3)
PA4: P29.9, P31.10, U38.40 (PA4)
PA5: P29.7, P31.12, U38.39 (PA5)
PA6: P29.5, P31.14, U38.38 (PA6)
PA7: P29.3, P31.16, U38.37 (PA7)
PB0: P29.4, P31.18, U38.18 (PB0)
PB1: P29.6, P31.20, U38.19 (PB1)
PB2: P29.8, P31.22, U38.20 (PB2)
PB3: P29.10, P31.24, U38.21 (PB3)
PB4: P29.12, P31.23, U38.22 (PB4)
PB5: P29.14, P31.21, U38.23 (PB5)
PB6: P29.16, P31.19, U38.24 (PB6)
PB7: P29.18, P31.17, U38.25 (PB7)
PC0: P29.35, P31.1, U38.14 (PC0)
PC1: P29.33, P31.3, U38.15 (PC1)
PC2: P29.36, P31.5, U38.16 (PC2)
PC3: P31.7, U38.17 (PC3), U63.9
PC4: P31.9, U38.13 (PC4), U63.11
PC5: P31.11, U38.12 (PC5), U63.3
PC6: P31.13, U38.11 (PC6), U63.5
PC7: P31.15, U38.10 (PC7), U63.1
RESET: U38.35 (RESET); also elsewhere on the board
/CS_PPI2: U38.6 (~CS); also elsewhere on the board
/PC3: P29.37, U63.8
/PC4: P29.38, U63.10
/PC5: P29.23, U63.4
/PC6: P29.25, U63.6
/PC7: P29.1, U63.2
/RD: U38.5 (~RD); also elsewhere on the board
/WR: U38.36 (~WR); also elsewhere on the board

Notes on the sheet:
NOTE: EITHER PPIDE OR PARALLEL EXPANSION PORT CAN BE USED BUT NOT BOTH SIMULTANEOUSLY.
K2 = USE FOR VCC OR GND PIN 25 PARALLEL PORT

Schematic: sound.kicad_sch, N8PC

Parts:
C101, C102: 270 pF; STD_DDW_PCAP
C109, C110: 10 uF; STD_DDW_PCAP
JP10: JUMPER; STD_DDW_PINHEAD_V_1x02
P15: AUDIO; STD_DDW_PINHEAD_V_2x05
P43: CHAN_MIX; STD_DDW_PinHeader_2x02
P51: JOYSTICK0; STD_DDW_PINHEAD_V_2x05
P52: JOYSTICK1; STD_DDW_PINHEAD_V_2x05
R16, R22, R23, R24: 10K; STD_DDW_RESISTOR
R17, R19, R21: 1000; STD_DDW_RESISTOR
RR8: 4700; STD_DDW_SIP10
RV1, RV2: 4700; STD_DDW_Potentiometer
U5: 74LS02; STD_DDW_DIP14
U34: 74LS393; STD_DDW_DIP14
U48: AY-3-8910; STD_DDW_DIP40
U49: 74LS07N; STD_DDW_DIP14
U51: STEREO_JACK; STD_DDW_Jack_3.5mm
U66, U67: 74LS157; STD_DDW_DIP16

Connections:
+5V: P15.1, P15.2, P51.9, P52.9, RR8.1 (common), U48.25 (A8), U48.28 (BC2), U48.40 (VCC), U66.16 (VCC), U67.16 (VCC); also elsewhere on the board
A0: U5.12; also elsewhere on the board
ACR5: P15.8; also elsewhere on the board
D0: U48.37 (D0); also elsewhere on the board
D1: U48.36 (D1); also elsewhere on the board
D2: U48.35 (D2); also elsewhere on the board
D3: U48.34 (D3); also elsewhere on the board
D4: U48.33 (D4); also elsewhere on the board
D5: U48.32 (D5); also elsewhere on the board
D6: U48.31 (D6); also elsewhere on the board
D7: U48.30 (D7); also elsewhere on the board
GND: C101.1, C102.2, JP10.1 (A), P15.10, P51.8, P52.8, R17.2, R19.2, R21.2, RV1.1, RV1.2, RV2.3, U48.1 (GND), U48.24 (A9), U51.S, U66.8 (GND), U66.15 (E), U67.8 (GND), U67.15 (E); also elsewhere on the board
IOA0: U48.21 (IOA0), U66.4 (Za)
IOA1: U48.20 (IOA1), U66.7 (Zb)
IOA2: U48.19 (IOA2), U66.12 (Zd)
IOA3: U48.18 (IOA3), U66.9 (Zc)
IOA4: U48.17 (IOA4), U67.4 (Za)
IOA5: U48.16 (IOA5), U67.7 (Zb)
IOA6: U48.15 (IOA6); also elsewhere on the board
IOA7: P15.4, U48.14 (IOA7); also elsewhere on the board
IOB0: U48.13 (IOB0), U49.1
IOB1: U48.12 (IOB1), U49.3
IOB2: U48.11 (IOB2), U49.5
IOB3: U48.10 (IOB3), U49.9
IOB4: P51.6, U48.9 (IOB4)
IOB5: P52.6, U48.8 (IOB5)
IOB6: U48.7 (IOB6), U66.1 (S), U67.1 (S)
IOB7: P15.6, U48.6 (IOB7)
unnamed: C101.2, C109.1, R22.1, R24.2, RV1.3
unnamed: C102.1, C110.1, R16.2, R23.1, RV2.1, RV2.2
unnamed: JP10.2 (B), U48.26 (TEST2)
unnamed: C109.2, P15.3, U51.T
unnamed: C110.2, P15.9, U51.R
unnamed: P43.1, R19.1, R23.2, U48.38 (OUTC)
unnamed: P43.2, P43.4, R16.1, R17.1, R24.1, U48.3 (OUTB)
unnamed: P43.3, R21.1, R22.2, U48.4 (OUTA)
unnamed: U34.3 (Q0), U48.22 (CLOCK)
unnamed: U5.13, U48.29 (BC1)
unnamed: U5.10, U48.27 (BDIR)
RESET: U34.2 (MR); also elsewhere on the board
VRY: U34.1 (CP); also elsewhere on the board
/BCK-A: P51.3, RR8.3 (R2), U66.5 (I0b)
/BCK-B: P52.3, RR8.8 (R7), U66.6 (I1b)
/FWD-A: P51.1, RR8.2 (R1), U66.2 (I0a)
/FWD-B: P52.1, RR8.7 (R6), U66.3 (I1a)
/LFT-A: P51.5, RR8.4 (R3), U66.14 (I0d)
/LFT-B: P52.5, RR8.9 (R8), U66.13 (I1d)
/RESAY3: U48.23 (RESET); also elsewhere on the board
/RGT-A: P51.7, RR8.5 (R4), U66.11 (I0c)
/RGT-B: P52.7, RR8.10 (R9), U66.10 (I1c)
/SNDCS: U5.9, U5.11; also elsewhere on the board
/TRG1-A: P51.2, U49.2, U67.2 (I0a); also elsewhere on the board
/TRG1-B: P52.2, U49.4, U67.3 (I1a); also elsewhere on the board
/TRG2-A: P51.4, U49.6, U67.5 (I0b); also elsewhere on the board
/TRG2-B: P52.4, U49.8, U67.6 (I1b); also elsewhere on the board
/WR: U5.8; also elsewhere on the board

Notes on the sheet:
NOTE: JP10 SHOULD BE LEFT OPEN

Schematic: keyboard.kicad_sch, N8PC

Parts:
J15: MOUSE; PS2_DIN
J16: KEYBOARD; PS2_DIN
NT1: NetTie_2; NetTie-2_THT_Pad0.3mm
U18: 74LS32; STD_DDW_DIP14
U24: CLK; STD_DDW_DIP14
U25: 82c42; STD_DDW_DIP40
U26: 74LS06; STD_DDW_DIP14

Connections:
+5V: J15.4, J16.4, U24.1, U24.14, U25.5 (SS), U25.40 (VCC); also elsewhere on the board
A0: U25.9 (A0); also elsewhere on the board
CLK: U24.8, U24.11, U25.3 (X2)
D0: U25.12 (D0); also elsewhere on the board
D1: U25.13 (D1); also elsewhere on the board
D2: U25.14 (D2); also elsewhere on the board
D3: U25.15 (D3); also elsewhere on the board
D4: U25.16 (D4); also elsewhere on the board
D5: U25.17 (D5); also elsewhere on the board
D6: U25.18 (D6); also elsewhere on the board
D7: U25.19 (D7); also elsewhere on the board
EXT-RES: U25.4 (RESET); also elsewhere on the board
GND: J15.3, J16.3, NT1.1, U24.4, U24.7; also elsewhere on the board
INT_KM: U18.6; also elsewhere on the board
KBDCLK: J16.5, U25.1 (T0), U26.6; also elsewhere on the board
KBDDAT: J16.1, U25.27 (P10), U26.12; also elsewhere on the board
MSECLK: J15.5, U25.39 (T1), U26.4; also elsewhere on the board
MSEDAT: J15.1, U25.28 (P11), U26.2; also elsewhere on the board
unnamed: NT1.2, U25.2 (X1), U25.7 (EA), U25.20 (VSS)
unnamed: U25.23 (P22), U26.1
unnamed: U25.24 (P23), U26.3
unnamed: U18.4, U25.35 (P24/OB)
unnamed: U18.5, U25.36 (P25/BF)
unnamed: U25.37 (P26/DRQ), U26.5
unnamed: U25.38 (P27/DAK), U26.13
PROG: U25.25 (PROG); also elsewhere on the board
/CS_KB: U25.6 (CS); also elsewhere on the board
/RD: U25.8 (RD); also elsewhere on the board
/WR: U25.10 (WR); also elsewhere on the board

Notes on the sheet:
8 MHz Crystal Oscillator
NOTE: IMPORTANT KNOWN TO WORK: - VT82C42N (VIA) LIKELY TO WORK BUT UNTESTED: - HT6542B (Holtek) - 83C42 (Western Digital) - KBD42W11 (SMSC) KNOWN DO NOT WORK: - 8042 (Intel & clones of PC/AT era)
KEYBOARD AND MOUSE

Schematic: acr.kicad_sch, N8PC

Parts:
R5: 470; STD_DDW_RESISTOR
U32: 74LS139; STD_DDW_DIP16
U39: 74LS04; STD_DDW_DIP14
U55: 74LS273; STD_DDW_DIP20
U70: 74LS174; STD_DDW_DIP16

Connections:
+5V: U55.20 (VCC), U70.16 (VCC); also elsewhere on the board
A1: U32.13 (A1); also elsewhere on the board
A15_ROM: U70.2 (Q0); also elsewhere on the board
A16_ROM: U70.5 (Q1); also elsewhere on the board
A17_ROM: U70.7 (Q2); also elsewhere on the board
A18_ROM: U70.10 (Q3); also elsewhere on the board
A19_ROM: U70.12 (Q4); also elsewhere on the board
ACR5: U55.15 (Q5); also elsewhere on the board
D0: U55.3 (D0), U70.3 (D0); also elsewhere on the board
D1: U55.4 (D1), U70.4 (D1); also elsewhere on the board
D2: U55.7 (D2), U70.6 (D2); also elsewhere on the board
D3: U55.8 (D3), U70.11 (D3); also elsewhere on the board
D4: U55.13 (D4), U70.13 (D4); also elsewhere on the board
D5: U55.14 (D5); also elsewhere on the board
D6: U55.17 (D6); also elsewhere on the board
D7: U55.18 (D7), U70.14 (D5); also elsewhere on the board
EXT-RES: U55.1 (~Mr), U70.1 (~Mr); also elsewhere on the board
GND: U55.10 (GND), U70.8 (GND); also elsewhere on the board
LED0: U55.2 (Q0); also elsewhere on the board
LED1: U55.5 (Q1); also elsewhere on the board
LED2: U55.6 (Q2); also elsewhere on the board
LED3: U70.15 (Q5); also elsewhere on the board
unnamed: R5.1, U39.4
unnamed: U32.12 (O0), U55.11 (Cp)
unnamed: U32.10 (O2), U70.9 (Cp)
RTS_TTL1: U55.16 (Q6); also elsewhere on the board
STATUS-LED: R5.2; also elsewhere on the board
/ACRCS: U32.15 (E); also elsewhere on the board
/RESAY3: U55.12 (Q4); also elsewhere on the board
/ROM_ENABLE: U55.19 (Q7); also elsewhere on the board
/STATUS: U39.3, U55.9 (Q3)
/WR: U32.14 (A0); also elsewhere on the board

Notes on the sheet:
STATUS LED
AUXILIARY CONTROL REGISTER

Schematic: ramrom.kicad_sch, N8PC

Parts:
K3, K4, K5, K16, K18: CONN_3; STD_DDW_PINHEAD_V_1x03
U13: 27C080; STD_DDW_DIP32
U53: SRAM_512KO; STD_DDW_DIP32

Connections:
+5V: K3.3, K16.3, K18.3, U13.32 (VCC), U53.32 (VCC); also elsewhere on the board
A0: U13.12 (A0), U53.12 (A0); also elsewhere on the board
A1: U13.11 (A1), U53.11 (A1); also elsewhere on the board
A2: U13.10 (A2), U53.10 (A2); also elsewhere on the board
A3: U13.9 (A3), U53.9 (A3); also elsewhere on the board
A4: U13.8 (A4), U53.8 (A4); also elsewhere on the board
A5: U13.7 (A5), U53.7 (A5); also elsewhere on the board
A6: U13.6 (A6), U53.6 (A6); also elsewhere on the board
A7: U13.5 (A7), U53.5 (A7); also elsewhere on the board
A8: U13.27 (A8), U53.27 (A8); also elsewhere on the board
A9: U13.26 (A9), U53.26 (A9); also elsewhere on the board
A10: U13.23 (A10), U53.23 (A10); also elsewhere on the board
A11: U13.25 (A11), U53.25 (A11); also elsewhere on the board
A12: U13.4 (A12), U53.4 (A12); also elsewhere on the board
A13: U13.28 (A13), U53.28 (A13); also elsewhere on the board
A14: U13.29 (A14), U53.3 (A14); also elsewhere on the board
A15: U53.31 (A15); also elsewhere on the board
A15_ROM: K18.1; also elsewhere on the board
A16: U53.2 (A16); also elsewhere on the board
A16_ROM: U13.2 (A16); also elsewhere on the board
A17: K16.1; also elsewhere on the board
A17_ROM: K3.1; also elsewhere on the board
A18: U53.1 (A18); also elsewhere on the board
A18_ROM: K4.1, K5.3; also elsewhere on the board
A19_ROM: K5.1; also elsewhere on the board
D0: U13.13 (D0), U53.13 (DQ0); also elsewhere on the board
D1: U13.14 (D1), U53.14 (DQ1); also elsewhere on the board
D2: U13.15 (D2), U53.15 (DQ2); also elsewhere on the board
D3: U13.17 (D3), U53.17 (DQ3); also elsewhere on the board
D4: U13.18 (D4), U53.18 (DQ4); also elsewhere on the board
D5: U13.19 (D5), U53.19 (DQ5); also elsewhere on the board
D6: U13.20 (D6), U53.20 (DQ6); also elsewhere on the board
D7: U13.21 (D7), U53.21 (DQ7); also elsewhere on the board
GND: U13.16 (GND), U53.16 (VSS); also elsewhere on the board
unnamed: K3.2, U13.30 (A17)
unnamed: K4.2, U13.31 (A18)
unnamed: K5.2, U13.1 (A19)
unnamed: K16.2, U53.30 (A17)
unnamed: K18.2, U13.3 (A15)
/CS_RAMLO: U53.22 (CE#); also elsewhere on the board
/CS_ROM: U13.22 (~CE); also elsewhere on the board
/RD: U13.24 (~OE), U53.24 (OE#); also elsewhere on the board
/WR: K4.3, U53.29 (WE#); also elsewhere on the board

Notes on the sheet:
K3 = USE FOR 32 PIN EPROM OR 28 PIN EPROM K4 = USE FOR 27C080 EPROM OR 29C040 FLASH K5 = USE FOR 27C080 EPROM OR 29C040 FLASH K18 = USE FOR 32 PIN EPROM OR 28 PIN EPROM
K16 = USE FOR 512K SRAM OR 128K SRAM

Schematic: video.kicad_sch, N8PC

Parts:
C34: 4.7pF; STD_DDW_CAP
D5: 1N5817; STD_DDW_DIODE
J11: F18A TANG NANO Connector; STD_DDW_PinHeader_2x10
U18: 74LS32; STD_DDW_DIP14
U23: TMS9918 EMU; STD_DDW_DIP40

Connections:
+5V: D5.2 (A), U23.33 (VCC); also elsewhere on the board
A0: C34.1, J11.14, U23.13 (MODE); also elsewhere on the board
D0: J11.19, U23.17 (CD7); also elsewhere on the board
D1: J11.17, U23.18 (CD6); also elsewhere on the board
D2: J11.15, U23.19 (CD5); also elsewhere on the board
D3: J11.13, U23.20 (CD4); also elsewhere on the board
D4: J11.11, U23.21 (CD3); also elsewhere on the board
D5: J11.9, U23.22 (CD2); also elsewhere on the board
D6: J11.7, U23.23 (CD1); also elsewhere on the board
D7: J11.5, U23.24 (CD0); also elsewhere on the board
EXT-RES: J11.12, U23.34 (~RESET); also elsewhere on the board
GND: C34.2, J11.1, J11.3, U23.12 (GND); also elsewhere on the board
unnamed: D5.1 (K), J11.2
VRY: J11.4, U23.38 (CPUCLK); also elsewhere on the board
/RD: U18.13; also elsewhere on the board
/VDPCS: U18.9, U18.12; also elsewhere on the board
/VDPRD: J11.18, U18.11, U23.15 (~CSR)
/VDPWR: J11.16, U18.8, U23.14 (~CSW)
/VINT: U23.16 (~INT); also elsewhere on the board
/WR: U18.10; also elsewhere on the board

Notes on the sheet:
Connector for Tang Nano F18A emulator https://github.com/lfantoniosi/tn_vdp
TMS9918 Socket, suitable for a Pico99 or F18A TMS9918 emulator Not suitable for an actual TMS9918 chip.

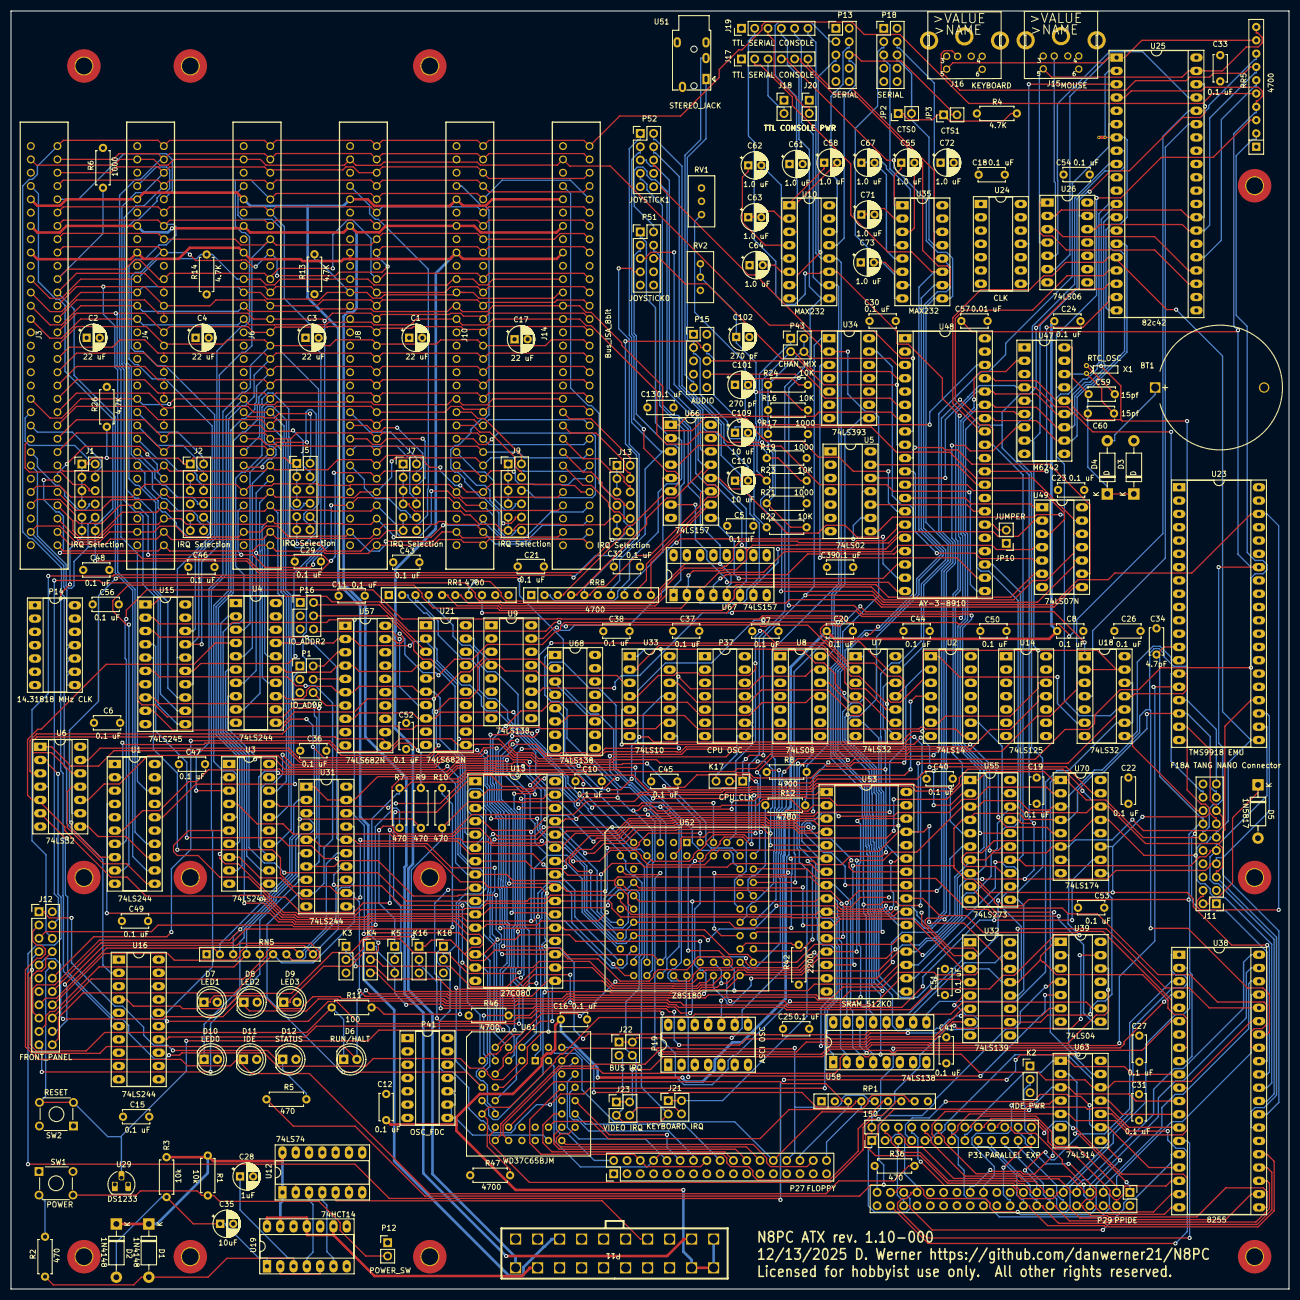
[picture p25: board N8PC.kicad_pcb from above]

Board: 4 copper layers, 244.0 x 244.0 mm, 226 parts (0 on the bottom side), 364 nets.

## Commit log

2025-11-30 rev 1.0
    [Decoder.kicad_sch, ECBbus.kicad_sch, IO.kicad_sch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]
2025-12-14 V1.1 PCB and schematic fix issue with data direction for bus
    [Decoder.kicad_sch, ECBbus.kicad_sch, IO.kicad_sch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]
2025-12-14 update for front panel fix
    [IO.kicad_sch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]
